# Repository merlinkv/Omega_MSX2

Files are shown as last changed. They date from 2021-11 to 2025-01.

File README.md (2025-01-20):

# Omega_MSX2
Update of the Omega Home Computer Project

# Original description

This project is an open source implementation of an MSX2 compatible computer. The project is built using a combination of 1980's era components - Z80 CPU, V9958 VDP, AY-3-8910/YM2149F PSG, 8255 PPI, 7400-series logic, and some newer components, such as 512 KiB SRAM and 512 KiB Flash ROM and a few simple programmable logic devices (ATF16V8B SPLDs).

# Keyboard PCB

* 14-04-2024
   - Version updated to 1.2 MKV
   - Schematics, PCB and Gerbers successfully ported to KiCad 8.0.1
   - The board has been rerouted.
   - Some components are now SMD
   - [Interactive BOM](https://htmlpreview.github.io/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)

# Mainboard PCB

* 10-05-2024
   - Added positility to select the connection type of Slots pin 44 (by SPDT switch SW3). They can be connected to GND (normal) or to NMI.
   - [Interactive BOM](https://htmlpreview.github.io/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)
* 20-04-2024
   - Version updated to 1.2.7 MKV
   - Power lines design has been changed.
   - Board has been re-routed.
* 14-04-2024
   - Version updated to 1.2.6 MKV
   - Schematics, PCB and Gerbers successfully ported to KiCad 8.0.1
   - The board has been re-routed.

# July 18, 2023

Added new ROMs.

# Mainboard PCB 1.2.5 MKV

* Improved routing parameters resulting on a bit more clear video & audio. In my opinion, before the RGB image was very good, now is really great.
* Power Switch footprint modified to, if desired, allow solder big section wires.
* Added another +5v Extra Power connector. The idea is to use it with horizontal pins and connect one small 4x4cm fan on top of the V9958.
* Board is tested working 100% with F4-FMPAC & o4Mega (4MB RAM) modules, internal Gotek with LCD 16x2 screen, cartridges Carnivore 2 & TDC-600 (floppy controller) at the same time with one **5.2v/3A** PSU

# Mainboard PCB 1.2 MKV

* Added possibility to use up to four different ROMs (two PLCC32 IC's).
* Added extra footprints for ROM selection switches.
* Changed internal FDD power connector to a better position.
* Changed all routing parameters and a couple of silk errors corrected.

# Mainboard PCB 1.1 MKV

Omega Mainboard PCB 1.1 MKV is a variant of the Mainboards 1.4US & 1.4EU by Sergey Kiselev & Jordi Solis

All "standard" capacitors, resistors & inductors are now in SMD 1206 format and placed at the bottom of the PCB.

New footprints for internal/external connections:

* 5-pins connector for DC-DC converter (+5v IN - +12v/-12v OUT)
* 2-pins connector for Power ON-OFF switch
* Two Extra Power connectors +5v (2-pins)
* One Extra Power connector +12v/-12v (3-pins)
* Connector for FM-PAC Module (AMP-GND, 2-pins)
* Connector for FM-PAC Power (+12v/-12v, 3-pins)
* Connector for RGB & Composite video (5-pins)
* Connector for S-Video (3-pins)
* Connector for Audio (Mono, 2-pins)
* Separate connectors for NMI & RESET (2-pins each)
* NMI signal connected to pin 44 of each slots (MSX3 Update?)
* FDD Power Connector (+5v/+12v, 4-pins)

# Notes

* Electrolytic capacitors: I recommend to use High Frequency and Low ESR ones.
* SMD resistors: Best is to use ones with 1% tolerance. All must be 1/4w.
* SMD capacitors: I recommend to use X7R type (10%) or less tolerance.
* ROM: AM29F040, SST39SF040 or compatible IC's can be used.
* SPLD's: ATF16V8B or GAL16V8B can be used without needed to use new jed's.
* For power cable and power switch best is to use wires with big section.
* At the moment I recommend to use one **5.2v/3A PSU**.
* It's possible to use one **5.5v/3A** PSU (near the limits but it's inside the power range).

# Links

* https://www.winuaespanol.com/phpbb3/viewtopic.php?p=13291#p13291
* https://github.com/skiselev/omega
* https://www.va-de-retro.com/foros/viewtopic.php?f=17&t=9304&start=40#p168183
* http://retrowiki.es/viewtopic.php?f=49&t=200037057&start=32#p200145495

# Images

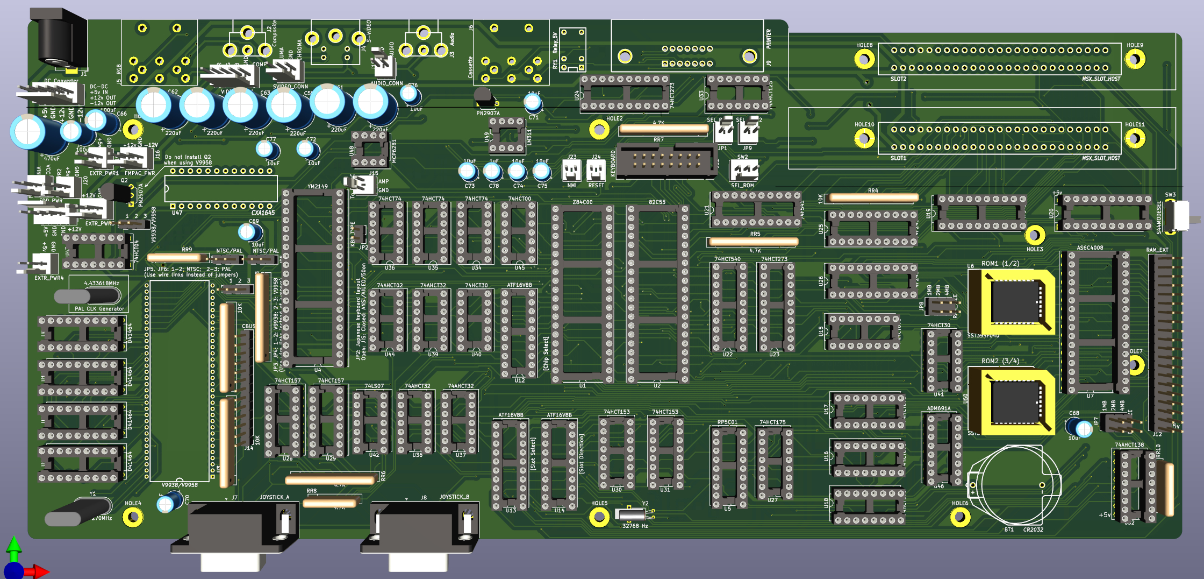
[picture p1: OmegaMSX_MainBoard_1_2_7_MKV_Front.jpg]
Vwersion 1.2.7 MKV Front

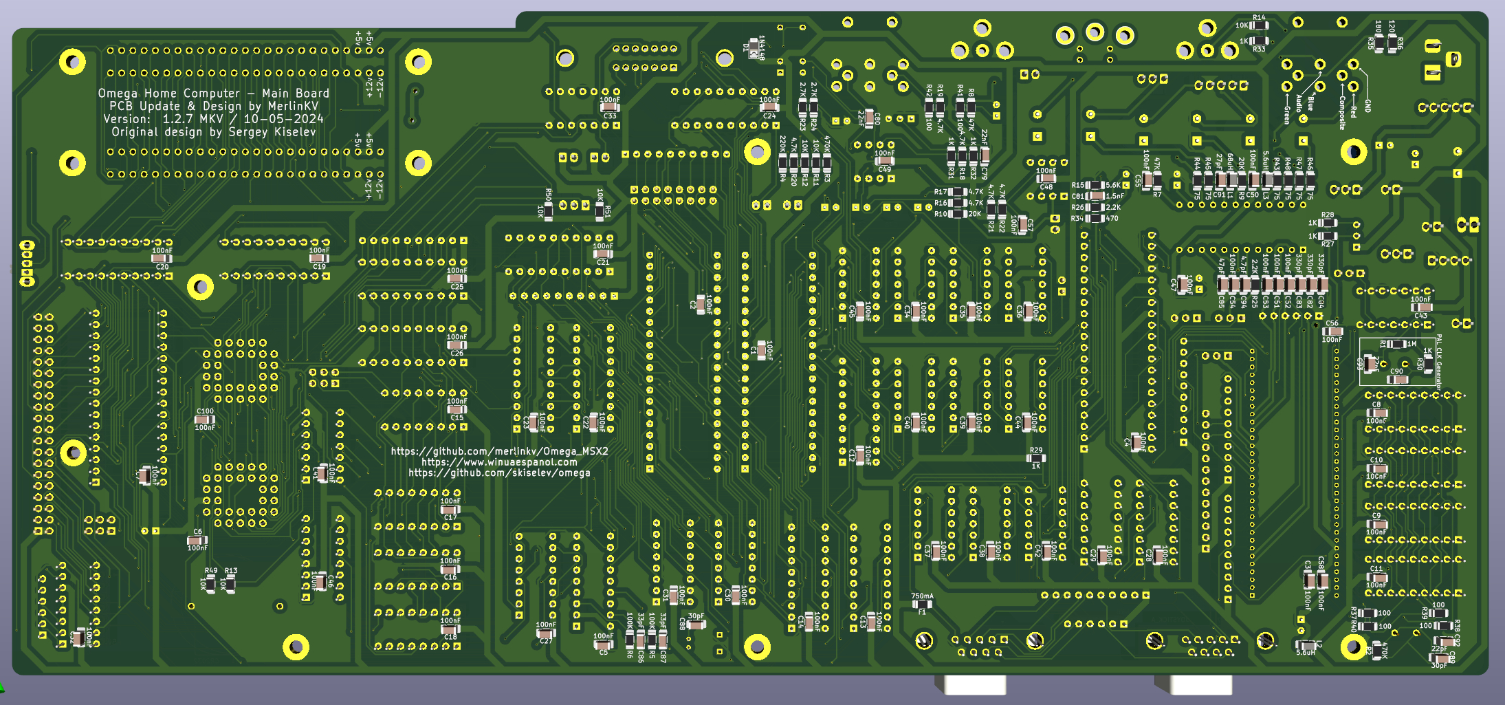
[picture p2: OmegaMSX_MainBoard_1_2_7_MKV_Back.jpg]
Vwersion 1.2.7 MKV Back

Vwersion 1.2.7 MKV Back
Vwersion 1.2.7 MKV Back
Vwersion 1.2.7 MKV Back
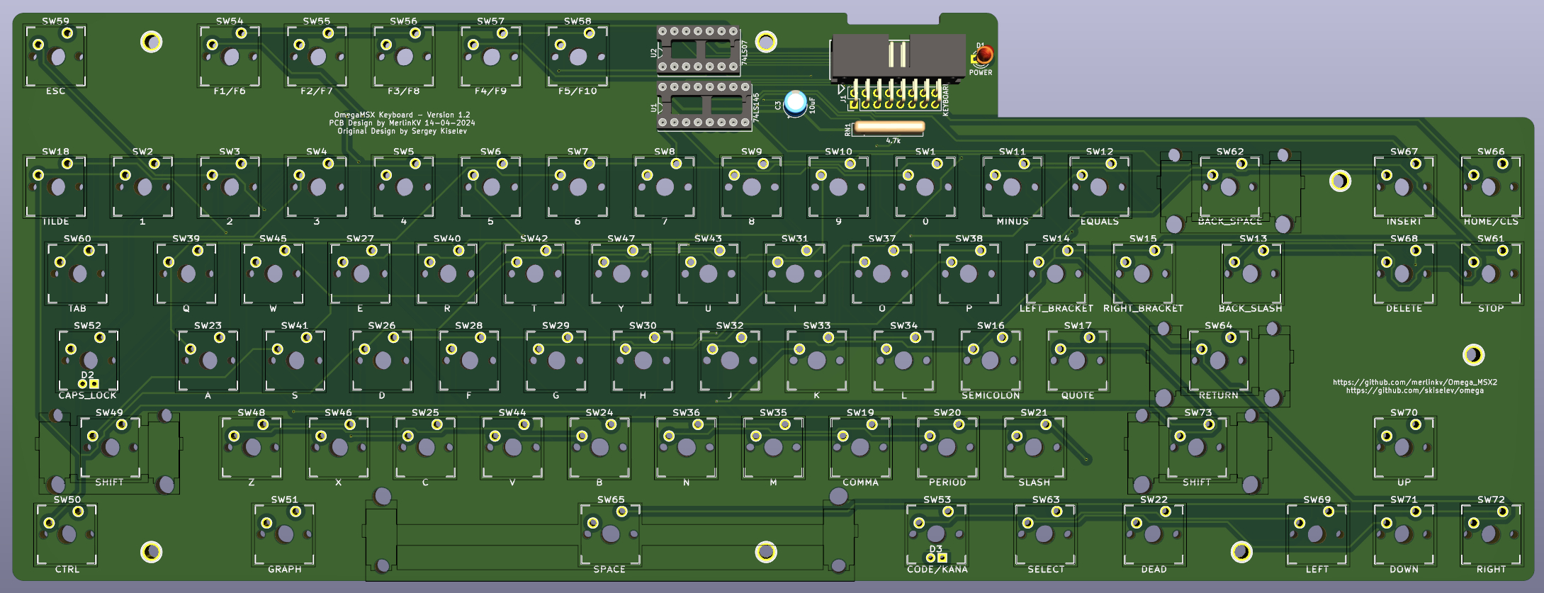
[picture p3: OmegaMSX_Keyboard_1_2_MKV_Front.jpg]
Version 1.2 MKV Front

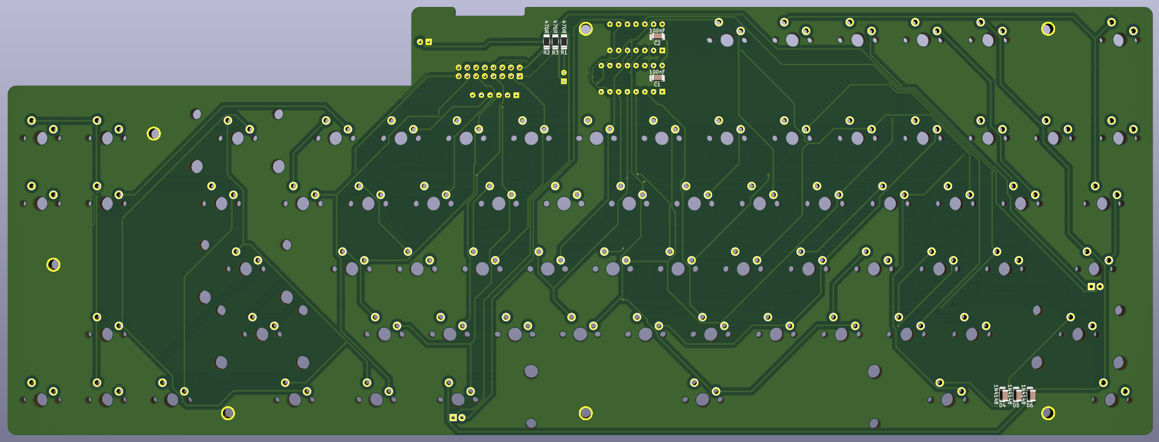
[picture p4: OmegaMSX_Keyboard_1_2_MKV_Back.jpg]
Version 1.2 MKV Back


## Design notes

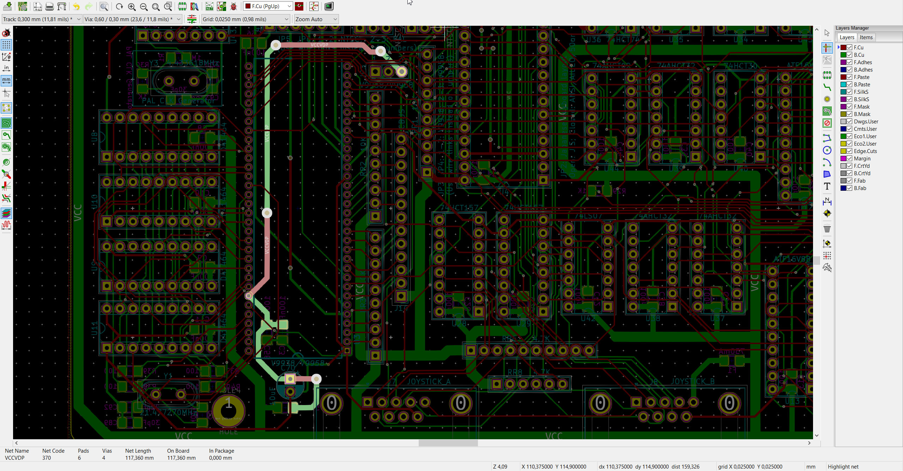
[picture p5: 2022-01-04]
Mainboard_1_2_MKV/OmegaMB_1_2_MKV_VCCVDP.jpg

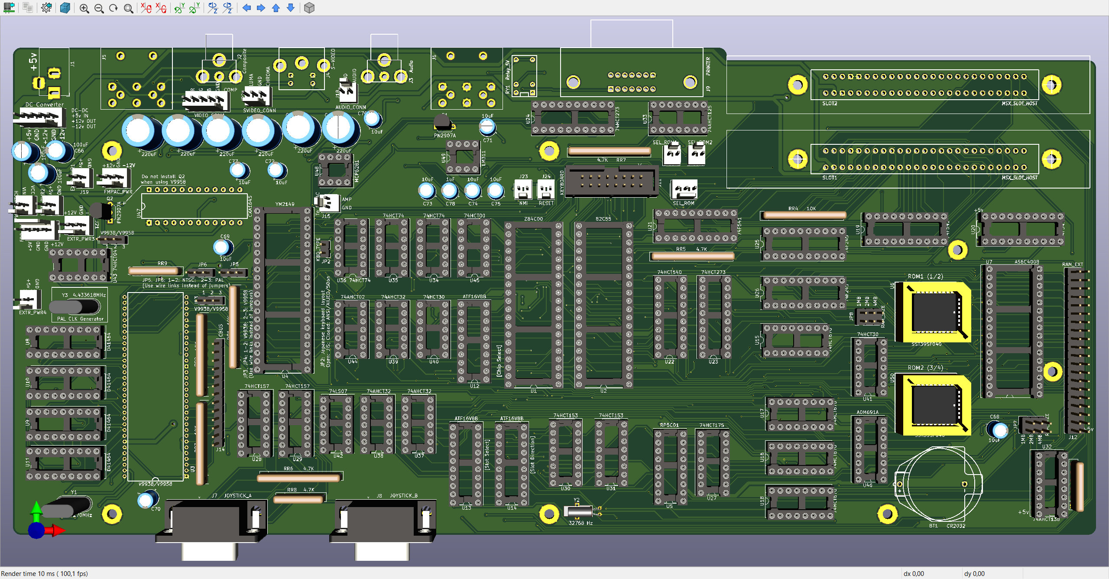
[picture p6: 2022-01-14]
Mainboard_1_2_5_MKV/OmegaMB_1_2_5_MKV_Front.jpg

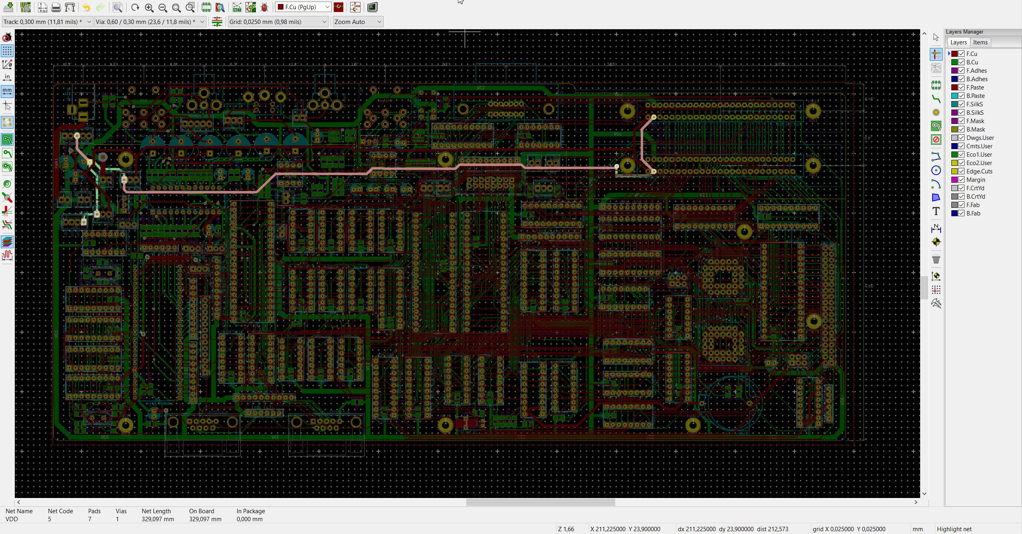
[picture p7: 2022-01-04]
Mainboard_1_2_MKV/OmegaMB_1_2_MKV_VDD.jpg

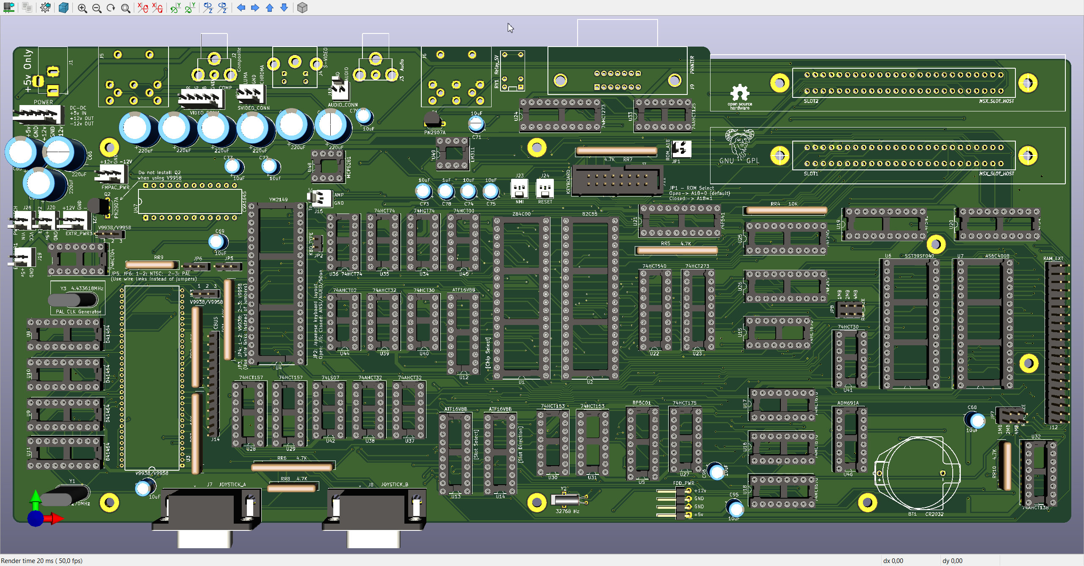
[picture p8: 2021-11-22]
Mainboard_1_1_MKV/OmegaMB_1_1_MKV_Front.jpg

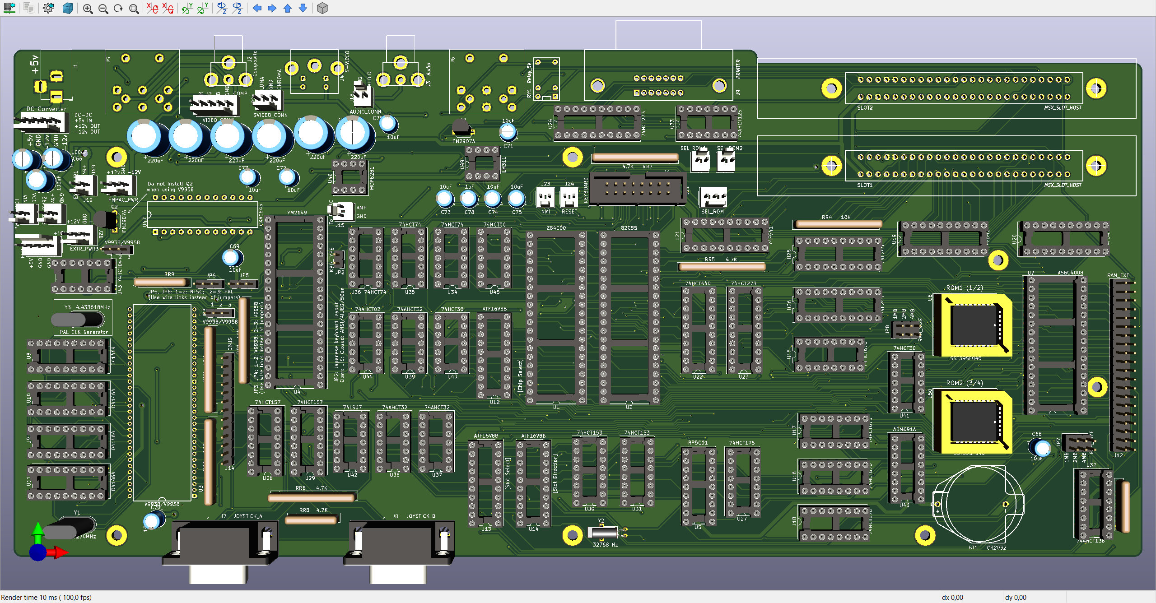
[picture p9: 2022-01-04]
Mainboard_1_2_MKV/OmegaMB_1_2_MKV_Front.jpg

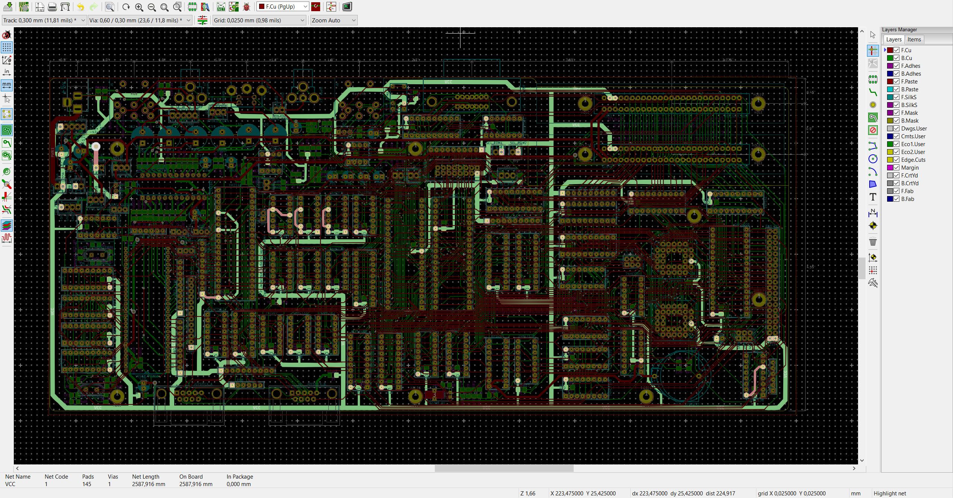
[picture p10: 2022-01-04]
Mainboard_1_2_MKV/OmegaMB_1_2_MKV_VCC.jpg

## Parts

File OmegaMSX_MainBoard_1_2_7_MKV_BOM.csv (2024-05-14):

Id | Designator | Footprint | Quantity | Designation | Supplier and ref
1 | SW3 | SW_Slide_SPDT_Angled_CK_OS102011MA1Q | 1 | S44MODESEL
2 | HOLE1,HOLE2,HOLE3,HOLE4,HOLE5,HOLE6,HOLE7,HOLE8,HOLE9,HOLE10,HOLE11 | MountingHole_3mm_Pad | 11 | HOLE
3 | C59,C60,C63,C64,C61,C62 | CP_Radial_D10.0mm_P5.00mm | 6 | 220uF
4 | C65 | CP_Radial_D10.0mm_P5.00mm | 1 | 470uF
5 | C66,C67 | CP_Radial_D6.3mm_P2.50mm | 2 | 100uF
6 | C72,C75,C76,C74,C77,C71,C73,C68,C69,C70 | CP_Radial_D5.0mm_P2.50mm | 10 | 10uF
7 | J1 | BarrelJack_Horizontal | 1 | 5V
8 | J7 | DSUB-9_Male_Horizontal_P2.77x2.84mm_EdgePinOffset4.94mm_Housed_MountingHolesOffset7.48mm | 1 | JOYSTICK_A
9 | J8 | DSUB-9_Male_Horizontal_P2.77x2.84mm_EdgePinOffset4.94mm_Housed_MountingHolesOffset7.48mm | 1 | JOYSTICK_B
10 | JP1 | Molex_KK-254_AE-6410-02A_1x02_P2.54mm_Vertical | 1 | SEL_ROM1
11 | JP2 | PinHeader_1x02_P2.54mm_Vertical | 1 | KBD_TYPE
12 | JP3,JP4 | PinHeader_1x03_P2.54mm_Vertical | 2 | V9938/V9958
13 | JP5,JP6 | PinHeader_1x03_P2.54mm_Vertical | 2 | NTSC/PAL
14 | RR1,RR2,RR3,RR4 | R_Array_SIP10 | 4 | 10K
15 | RR6,RR5,RR7 | R_Array_SIP10 | 3 | 4.7K
16 | RR8,RR10 | R_Array_SIP6 | 2 | 4.7K
17 | RR9 | R_Array_SIP6 | 1 | 470
18 | U2 | DIP-40_W15.24mm_Socket | 1 | 82C55
19 | U3 | IC_SDIP64_600 | 1 | V9938/V9958
20 | U4 | DIP-40_W15.24mm_Socket | 1 | YM2149
21 | U5 | DIP-18_W7.62mm_Socket | 1 | RP5C01
22 | U6,U50 | SST39SF040_PLCC32 | 2 | SST39SF040
23 | U7 | DIP-32_W15.24mm_Socket | 1 | AS6C4008
24 | U8,U9,U10,U11 | DIP-18_W7.62mm_Socket | 4 | D41464
25 | U12,U14,U13 | DIP-20_W7.62mm_Socket | 3 | ATF16V8B
26 | U15,U17,U18,U16 | DIP-16_W7.62mm_Socket | 4 | 74HCT670
27 | U20,U21,U19 | DIP-20_W7.62mm_Socket | 3 | 74F541
28 | U23,U24 | DIP-20_W7.62mm_Socket | 2 | 74HCT273
29 | U25,U26 | DIP-20_W7.62mm_Socket | 2 | 74F245
30 | U27 | DIP-16_W7.62mm_Socket | 1 | 74HCT175
31 | U28,U29 | DIP-16_W7.62mm_Socket | 2 | 74HCT157
32 | U31,U30 | DIP-16_W7.62mm_Socket | 2 | 74HCT153
33 | U33 | DIP-14_W7.62mm_Socket | 1 | 74AHCT125
34 | U34,U35,U36 | DIP-14_W7.62mm_Socket | 3 | 74HCT74
35 | U38,U39,U37 | DIP-14_W7.62mm_Socket | 3 | 74AHCT32
36 | U42 | DIP-14_W7.62mm_Socket | 1 | 74LS07
37 | U44 | DIP-14_W7.62mm_Socket | 1 | 74AHCT02
38 | U45 | DIP-14_W7.62mm_Socket | 1 | 74HCT00
39 | U47 | IC_DIP24_400 | 1 | CXA1645
40 | Y3 | Crystal_HC49-U_Vertical | 1 | 4.433618MHz
41 | J3 | Conn_RCA_Right | 1 | Audio
42 | U22 | DIP-20_W7.62mm_Socket | 1 | 74HCT540
43 | U40,U41 | DIP-14_W7.62mm_Socket | 2 | 74HCT30
44 | J11 | IDC-Header_2x08_P2.54mm_Vertical | 1 | KEYBOARD
45 | Q2,Q1 | TO-92L_Inline_Wide | 2 | PN2907A
46 | J12 | PinHeader_2x20_P2.54mm_Vertical | 1 | RAM_EXT
47 | BT1 | Battery_Holder_CR2032_Universal | 1 | CR2032
48 | U46 | DIP-16_W7.62mm_Socket | 1 | ADM691A
49 | J9 | Conn_Micro_Ribbon_14F | 1 | PRINTER
50 | J4 | Conn_Mini_DIN_4pin | 1 | S-VIDEO
51 | U48 | DIP-8_W7.62mm_Socket | 1 | MCP6281
52 | U43 | DIP-14_W7.62mm_Socket | 1 | 74HCT04
53 | J6 | DIN8 | 1 | Cassette
54 | RY1 | Relay_SPDT | 1 | Relay_5V
55 | C78 | CP_Radial_D5.0mm_P2.50mm | 1 | 1uF
56 | U49 | DIP-8_W7.62mm_Socket | 1 | LM311
57 | J5 | DIN8 | 1 | RGB
58 | J2 | Conn_RCA_Right | 1 | Composite
59 | Y1 | Crystal_HC49-U_Vertical | 1 | 21.477270MHz
60 | Y2 | Crystal_C38-LF_D3.0mm_L8.0mm_Horizontal_1EP_style2 | 1 | 32768 Hz
61 | J14 | PinHeader_1x13_P2.54mm_Vertical | 1 | CBUS
62 | JP7,JP8 | PinHeader_2x03_P2.54mm_Vertical | 2 | RAM_SIZE
63 | U32 | DIP-16_W7.62mm_Socket | 1 | 74AHCT138
64 | J15 | Molex_KK-254_AE-6410-02A_1x02_P2.54mm_Vertical | 1 | To_FMPAC
65 | J16 | Molex_KK-254_AE-6410-03A_1x03_P2.54mm_Vertical | 1 | FMPAC_PWR
66 | J25 | Molex_KK-254_AE-6410-04A_1x04_P2.54mm_Vertical | 1 | FDD_PWR
67 | J21 | Molex_KK-254_AE-6410-03A_1x03_P2.54mm_Vertical | 1 | EXTR_PWR3
68 | SLOT1,SLOT2 | Conn_Edge_50P | 2 | MSX_SLOT_HOST
69 | U1 | DIP-40_W15.24mm_Socket | 1 | Z84C00
70 | J22 | Molex_KK-254_AE-6410-03A_1x03_P2.54mm_Vertical | 1 | SVIDEO_CONN
71 | J19 | Molex_KK-254_AE-6410-02A_1x02_P2.54mm_Vertical | 1 | EXTR_PWR1
72 | J20 | Molex_KK-254_AE-6410-02A_1x02_P2.54mm_Vertical | 1 | EXTR_PWR2
73 | J17 | Molex_KK-254_AE-6410-05A_1x05_P2.54mm_Vertical | 1 | VIDEO_CONN
74 | J18 | Molex_KK-254_AE-6410-02A_1x02_P2.54mm_Vertical | 1 | AUDIO_CONN
75 | J23 | Molex_KK-254_AE-6410-02A_1x02_P2.54mm_Vertical | 1 | NMI
76 | J24 | Molex_KK-254_AE-6410-02A_1x02_P2.54mm_Vertical | 1 | RESET
77 | J10 | Molex_KK-254_AE-6410-05A_1x05_P2.54mm_Vertical | 1 | DC Converter
78 | JP9 | Molex_KK-254_AE-6410-02A_1x02_P2.54mm_Vertical | 1 | SEL_ROM2
79 | SW2 | Molex_KK-254_AE-6410-03A_1x03_P2.54mm_Vertical | 1 | SEL_ROM
80 | J27 | Molex_KK-254_AE-6410-02A_1x02_P2.54mm_Vertical | 1 | EXTR_PWR4
81 | J26 | Molex_KK-254_AE-6410-02A_1x02_P2.54mm_Vertical_Omega | 1 | PWR_SW
82 | C1,C2,C4,C5,C6,C7,C8,C9,C10,C11,C12,C13,C14,C15,C17,C18,C20,C21,C22,C24,C25,C26,C27,C28,C29,C30,C31,C32,C33,C34,C35,C36,C37,C38,C39,C40,C41,C42,C43,C44,C45,C46,C47,C52,C56,C23,C54,C51,C53,C19,C16,C48,C57,C49,C55,C58,C3,C50,C100 | C_1206_3216Metric_Pad1.33x1.80mm_HandSolder | 59 | 100nF
83 | C80,C79 | C_1206_3216Metric_Pad1.33x1.80mm_HandSolder | 2 | 22nF
84 | C82,C83,C84 | C_1206_3216Metric_Pad1.33x1.80mm_HandSolder | 3 | 330pF
85 | C85 | C_1206_3216Metric_Pad1.33x1.80mm_HandSolder | 1 | 47pF
86 | C86,C87 | C_1206_3216Metric_Pad1.33x1.80mm_HandSolder | 2 | 33pF
87 | C92,C93 | C_1206_3216Metric_Pad1.33x1.80mm_HandSolder | 2 | 22pF
88 | D1 | D_1206_3216Metric_Pad1.42x1.75mm_HandSolder | 1 | 1N4148
89 | R1 | R_1206_3216Metric_Pad1.30x1.75mm_HandSolder | 1 | 1M
90 | R2,R3 | R_1206_3216Metric_Pad1.30x1.75mm_HandSolder | 2 | 470K
91 | R5,R6 | R_1206_3216Metric_Pad1.30x1.75mm_HandSolder | 2 | 100K
92 | R7,R8 | R_1206_3216Metric_Pad1.30x1.75mm_HandSolder | 2 | 47K
93 | R17,R21,R22,R16,R19,R18,R20 | R_1206_3216Metric_Pad1.30x1.75mm_HandSolder | 7 | 4.7K
94 | R25,R26 | R_1206_3216Metric_Pad1.30x1.75mm_HandSolder | 2 | 2.2K
95 | R30,R29,R27,R28,R31,R32,R33 | R_1206_3216Metric_Pad1.30x1.75mm_HandSolder | 7 | 1K
96 | R37,R39,R40,R41,R38,R42 | R_1206_3216Metric_Pad1.30x1.75mm_HandSolder | 6 | 100
97 | R47,R48,R45,R44,R43,R46 | R_1206_3216Metric_Pad1.30x1.75mm_HandSolder | 6 | 75
98 | R9,R10 | R_1206_3216Metric_Pad1.30x1.75mm_HandSolder | 2 | 20K
99 | C94 | C_1206_3216Metric_Pad1.33x1.80mm_HandSolder | 1 | 4.7pF
100 | C81 | C_1206_3216Metric_Pad1.33x1.80mm_HandSolder | 1 | 1.5nF
101 | R13,R12,R11,R14,R49,R50,R51 | R_1206_3216Metric_Pad1.30x1.75mm_HandSolder | 7 | 10K
102 | R15 | R_1206_3216Metric_Pad1.30x1.75mm_HandSolder | 1 | 5.6K
103 | L1 | L_1206_3216Metric_Pad1.42x1.75mm_HandSolder | 1 | 68uH
104 | C91 | C_1206_3216Metric_Pad1.33x1.80mm_HandSolder | 1 | 27pF
105 | R23,R24 | R_1206_3216Metric_Pad1.30x1.75mm_HandSolder | 2 | 2.7K
106 | R4 | R_1206_3216Metric_Pad1.30x1.75mm_HandSolder | 1 | 220K
107 | R35 | R_1206_3216Metric_Pad1.30x1.75mm_HandSolder | 1 | 180
108 | R36 | R_1206_3216Metric_Pad1.30x1.75mm_HandSolder | 1 | 120
109 | R34 | R_1206_3216Metric_Pad1.30x1.75mm_HandSolder | 1 | 470
110 | L2,L3 | L_1206_3216Metric_Pad1.42x1.75mm_HandSolder | 2 | 5.6uH
111 | F1 | Fuse_1206_3216Metric_Pad1.42x1.75mm_HandSolder | 1 | 750mA
112 | C89,C90,C88 | C_1206_3216Metric_Pad1.33x1.80mm_HandSolder | 3 | 30pF

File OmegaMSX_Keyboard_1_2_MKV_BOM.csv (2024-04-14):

Id | Designator | Footprint | Quantity | Designation | Supplier and ref
1 | SW1 | CHERRY_PCB_100H | 1 | 0
2 | SW2 | CHERRY_PCB_100H | 1 | 1
3 | SW3 | CHERRY_PCB_100H | 1 | 2
4 | SW4 | CHERRY_PCB_100H | 1 | 3
5 | SW5 | CHERRY_PCB_100H | 1 | 4
6 | SW6 | CHERRY_PCB_100H | 1 | 5
7 | SW7 | CHERRY_PCB_100H | 1 | 6
8 | SW8 | CHERRY_PCB_100H | 1 | 7
9 | SW9 | CHERRY_PCB_100H | 1 | 8
10 | SW10 | CHERRY_PCB_100H | 1 | 9
11 | SW11 | CHERRY_PCB_100H | 1 | MINUS
12 | SW12 | CHERRY_PCB_100H | 1 | EQUALS
13 | SW13 | CHERRY_PCB_150H | 1 | BACK_SLASH
14 | SW14 | CHERRY_PCB_100H | 1 | LEFT_BRACKET
15 | SW15 | CHERRY_PCB_100H | 1 | RIGHT_BRACKET
16 | SW16 | CHERRY_PCB_100H | 1 | SEMICOLON
17 | SW17 | CHERRY_PCB_100H | 1 | QUOTE
18 | SW18 | CHERRY_PCB_100H | 1 | TILDE
19 | SW19 | CHERRY_PCB_100H | 1 | COMMA
20 | SW20 | CHERRY_PCB_100H | 1 | PERIOD
21 | SW21 | CHERRY_PCB_100H | 1 | SLASH
22 | SW22 | CHERRY_PCB_100H | 1 | DEAD
23 | SW23 | CHERRY_PCB_100H | 1 | A
24 | SW24 | CHERRY_PCB_100H | 1 | B
25 | SW25 | CHERRY_PCB_100H | 1 | C
26 | SW26 | CHERRY_PCB_100H | 1 | D
27 | SW27 | CHERRY_PCB_100H | 1 | E
28 | SW28 | CHERRY_PCB_100H | 1 | F
29 | SW29 | CHERRY_PCB_100H | 1 | G
30 | SW30 | CHERRY_PCB_100H | 1 | H
31 | SW31 | CHERRY_PCB_100H | 1 | I
32 | SW32 | CHERRY_PCB_100H | 1 | J
33 | SW33 | CHERRY_PCB_100H | 1 | K
34 | SW34 | CHERRY_PCB_100H | 1 | L
35 | SW35 | CHERRY_PCB_100H | 1 | M
36 | SW36 | CHERRY_PCB_100H | 1 | N
37 | SW37 | CHERRY_PCB_100H | 1 | O
38 | SW38 | CHERRY_PCB_100H | 1 | P
39 | SW39 | CHERRY_PCB_100H | 1 | Q
40 | SW40 | CHERRY_PCB_100H | 1 | R
41 | SW41 | CHERRY_PCB_100H | 1 | S
42 | SW42 | CHERRY_PCB_100H | 1 | T
43 | SW43 | CHERRY_PCB_100H | 1 | U
44 | SW44 | CHERRY_PCB_100H | 1 | V
45 | SW45 | CHERRY_PCB_100H | 1 | W
46 | SW46 | CHERRY_PCB_100H | 1 | X
47 | SW47 | CHERRY_PCB_100H | 1 | Y
48 | SW48 | CHERRY_PCB_100H | 1 | Z
49 | SW49 | CHERRY_PCB_225H | 1 | SHIFT
50 | SW50 | CHERRY_PCB_125H | 1 | CTRL
51 | SW51 | CHERRY_PCB_125H | 1 | GRAPH
52 | SW52 | CHERRY_PCB_175H | 1 | CAPS_LOCK
53 | SW53 | CHERRY_PCB_125H | 1 | CODE/KANA
54 | SW54 | CHERRY_PCB_100H | 1 | F1/F6
55 | SW55 | CHERRY_PCB_100H | 1 | F2/F7
56 | SW56 | CHERRY_PCB_100H | 1 | F3/F8
57 | SW57 | CHERRY_PCB_100H | 1 | F4/F9
58 | SW58 | CHERRY_PCB_100H | 1 | F5/F10
59 | SW59 | CHERRY_PCB_100H | 1 | ESC
60 | SW60 | CHERRY_PCB_100H | 1 | TAB
61 | SW61 | CHERRY_PCB_100H | 1 | STOP
62 | SW62 | CHERRY_PCB_200H | 1 | BACK_SPACE
63 | SW64 | CHERRY_PCB_225H | 1 | RETURN
64 | SW65 | CHERRY_PCB_625H | 1 | SPACE
65 | SW66 | CHERRY_PCB_100H | 1 | HOME/CLS
66 | SW67 | CHERRY_PCB_100H | 1 | INSERT
67 | SW68 | CHERRY_PCB_100H | 1 | DELETE
68 | SW69 | CHERRY_PCB_100H | 1 | LEFT
69 | SW70 | CHERRY_PCB_100H | 1 | UP
70 | SW71 | CHERRY_PCB_100H | 1 | DOWN
71 | SW72 | CHERRY_PCB_100H | 1 | RIGHT
72 | SW63 | CHERRY_PCB_125H | 1 | SELECT
73 | SW73 | CHERRY_PCB_275H | 1 | SHIFT
74 | C3 | CP_Radial_D5.0mm_P2.50mm | 1 | 10uF
75 | D1 | LED_D3.0mm | 1 | POWER
76 | HOLE1,HOLE2,HOLE3,HOLE4,HOLE5,HOLE6,HOLE7 | Hole_3mm | 7 | HOLE
77 | J1 | PinHeader_2x08_P2.54mm_Vertical | 1 | KEYBOARD
78 | U1 | DIP-16_W7.62mm_Socket | 1 | 74LS145
79 | U2 | DIP-14_W7.62mm_Socket | 1 | 74LS07
80 | D3 | CHERRY_MX_LED | 1 | KANA
81 | D2 | CHERRY_MX_LED | 1 | CAPS
82 | RN1 | R_Array_SIP6 | 1 | 4.7k
83 | C1,C2 | C_1206_3216Metric_Pad1.33x1.80mm_HandSolder | 2 | 100nF
84 | D4,D5,D6 | C_1206_3216Metric_Pad1.33x1.80mm_HandSolder | 3 | 1N4148
85 | R1,R2,R3 | R_1206_3216Metric_Pad1.30x1.75mm_HandSolder | 3 | 470R

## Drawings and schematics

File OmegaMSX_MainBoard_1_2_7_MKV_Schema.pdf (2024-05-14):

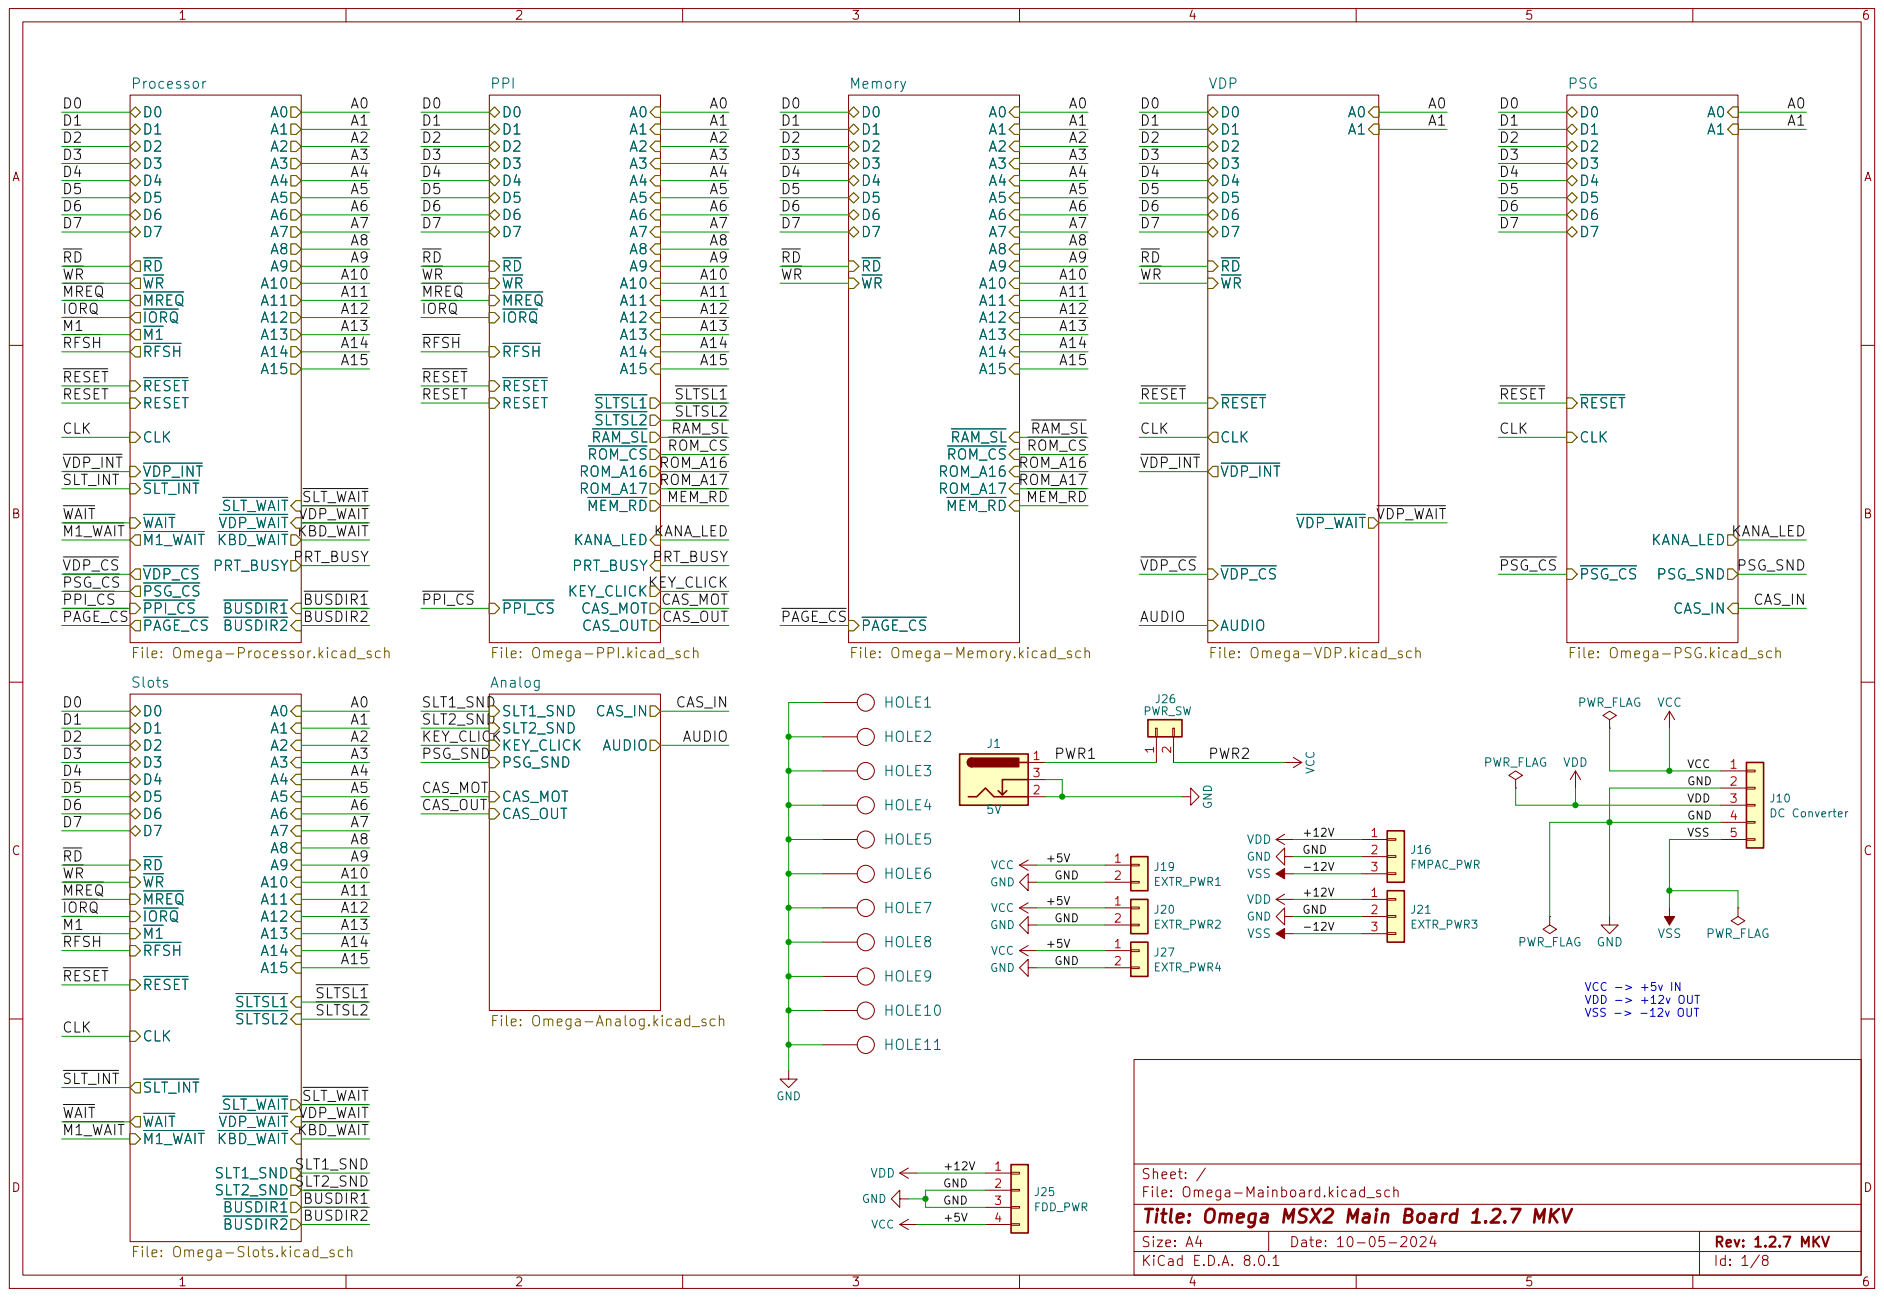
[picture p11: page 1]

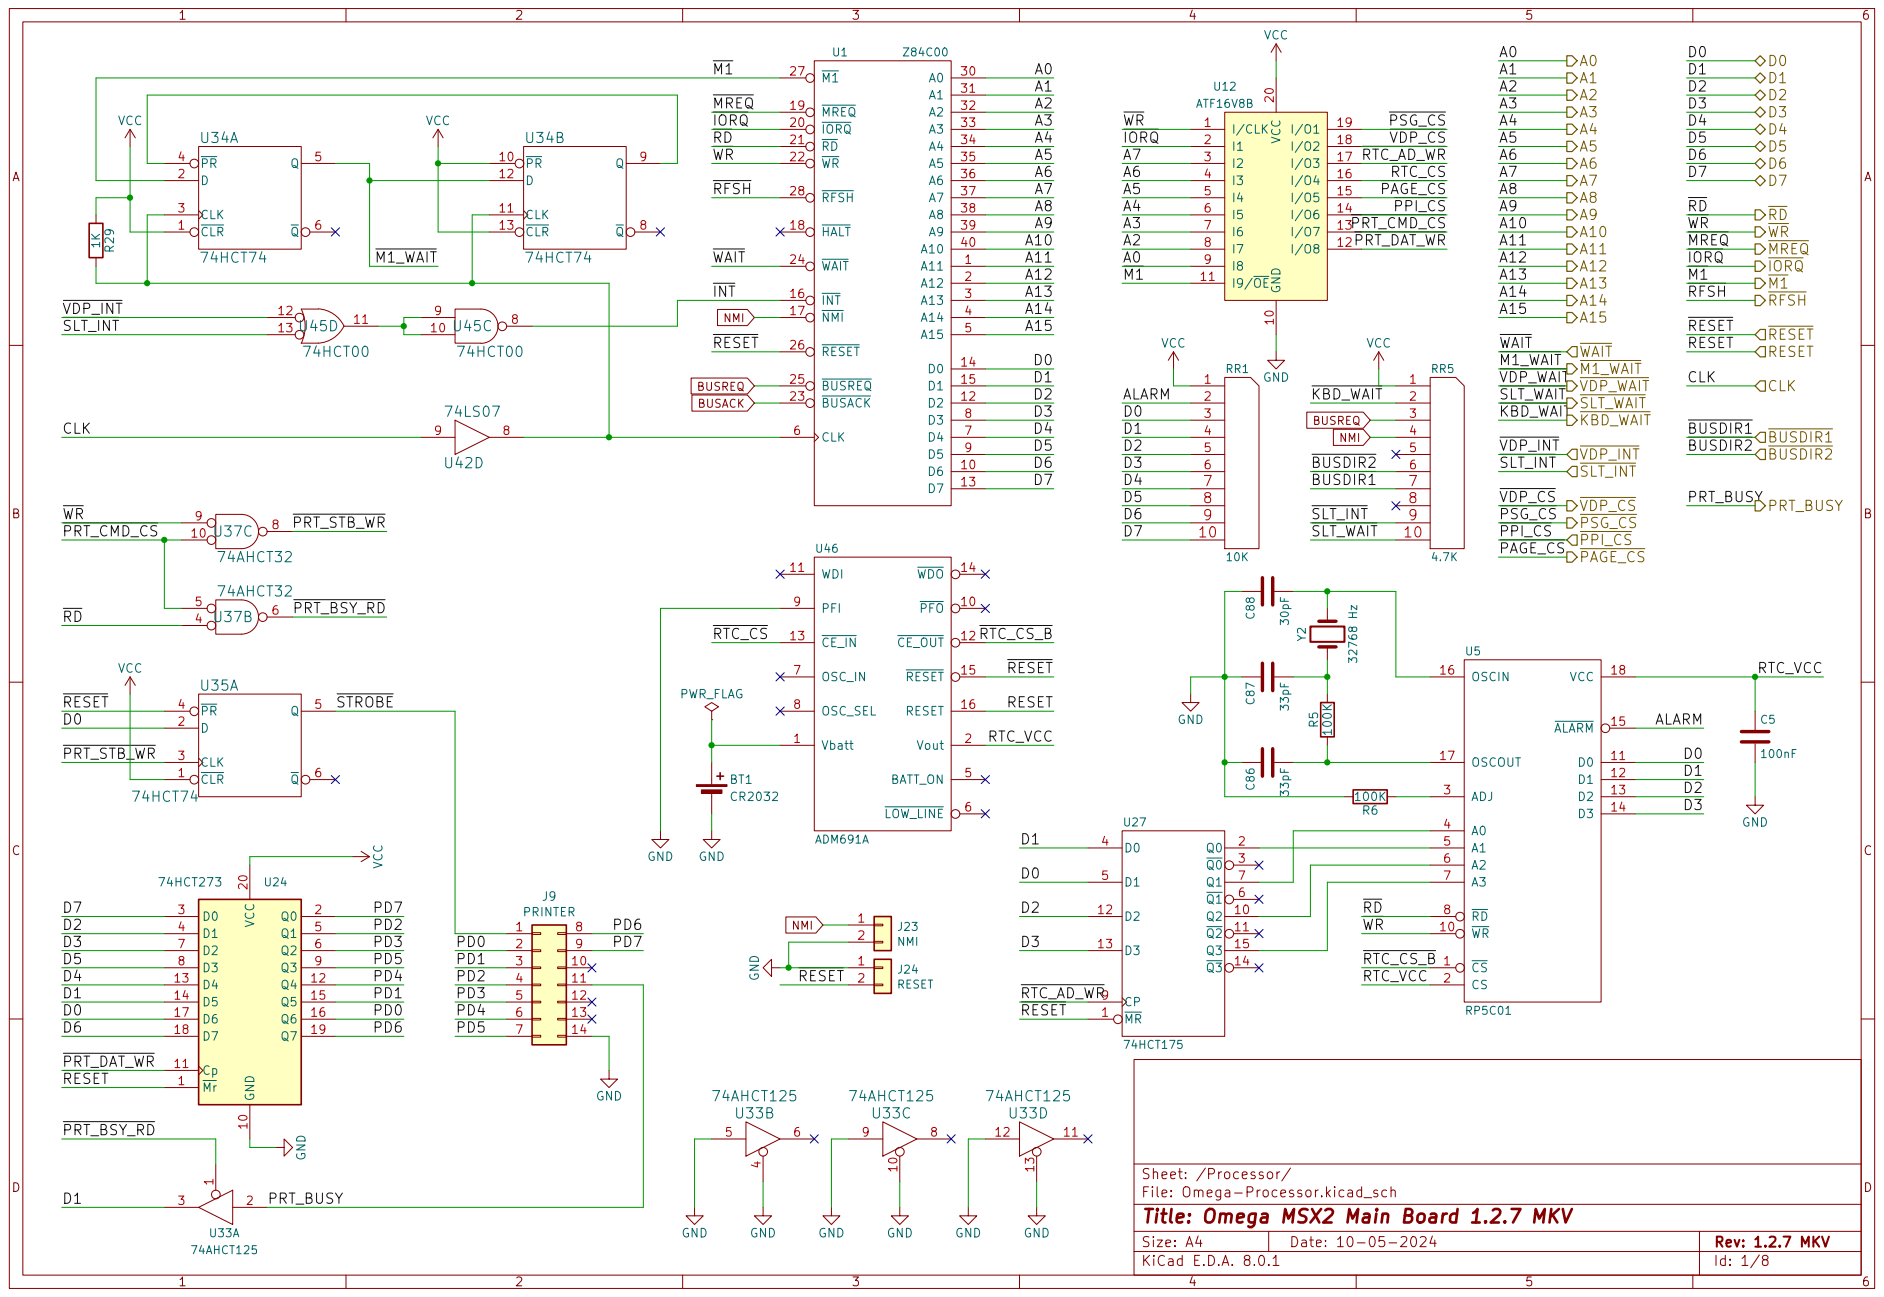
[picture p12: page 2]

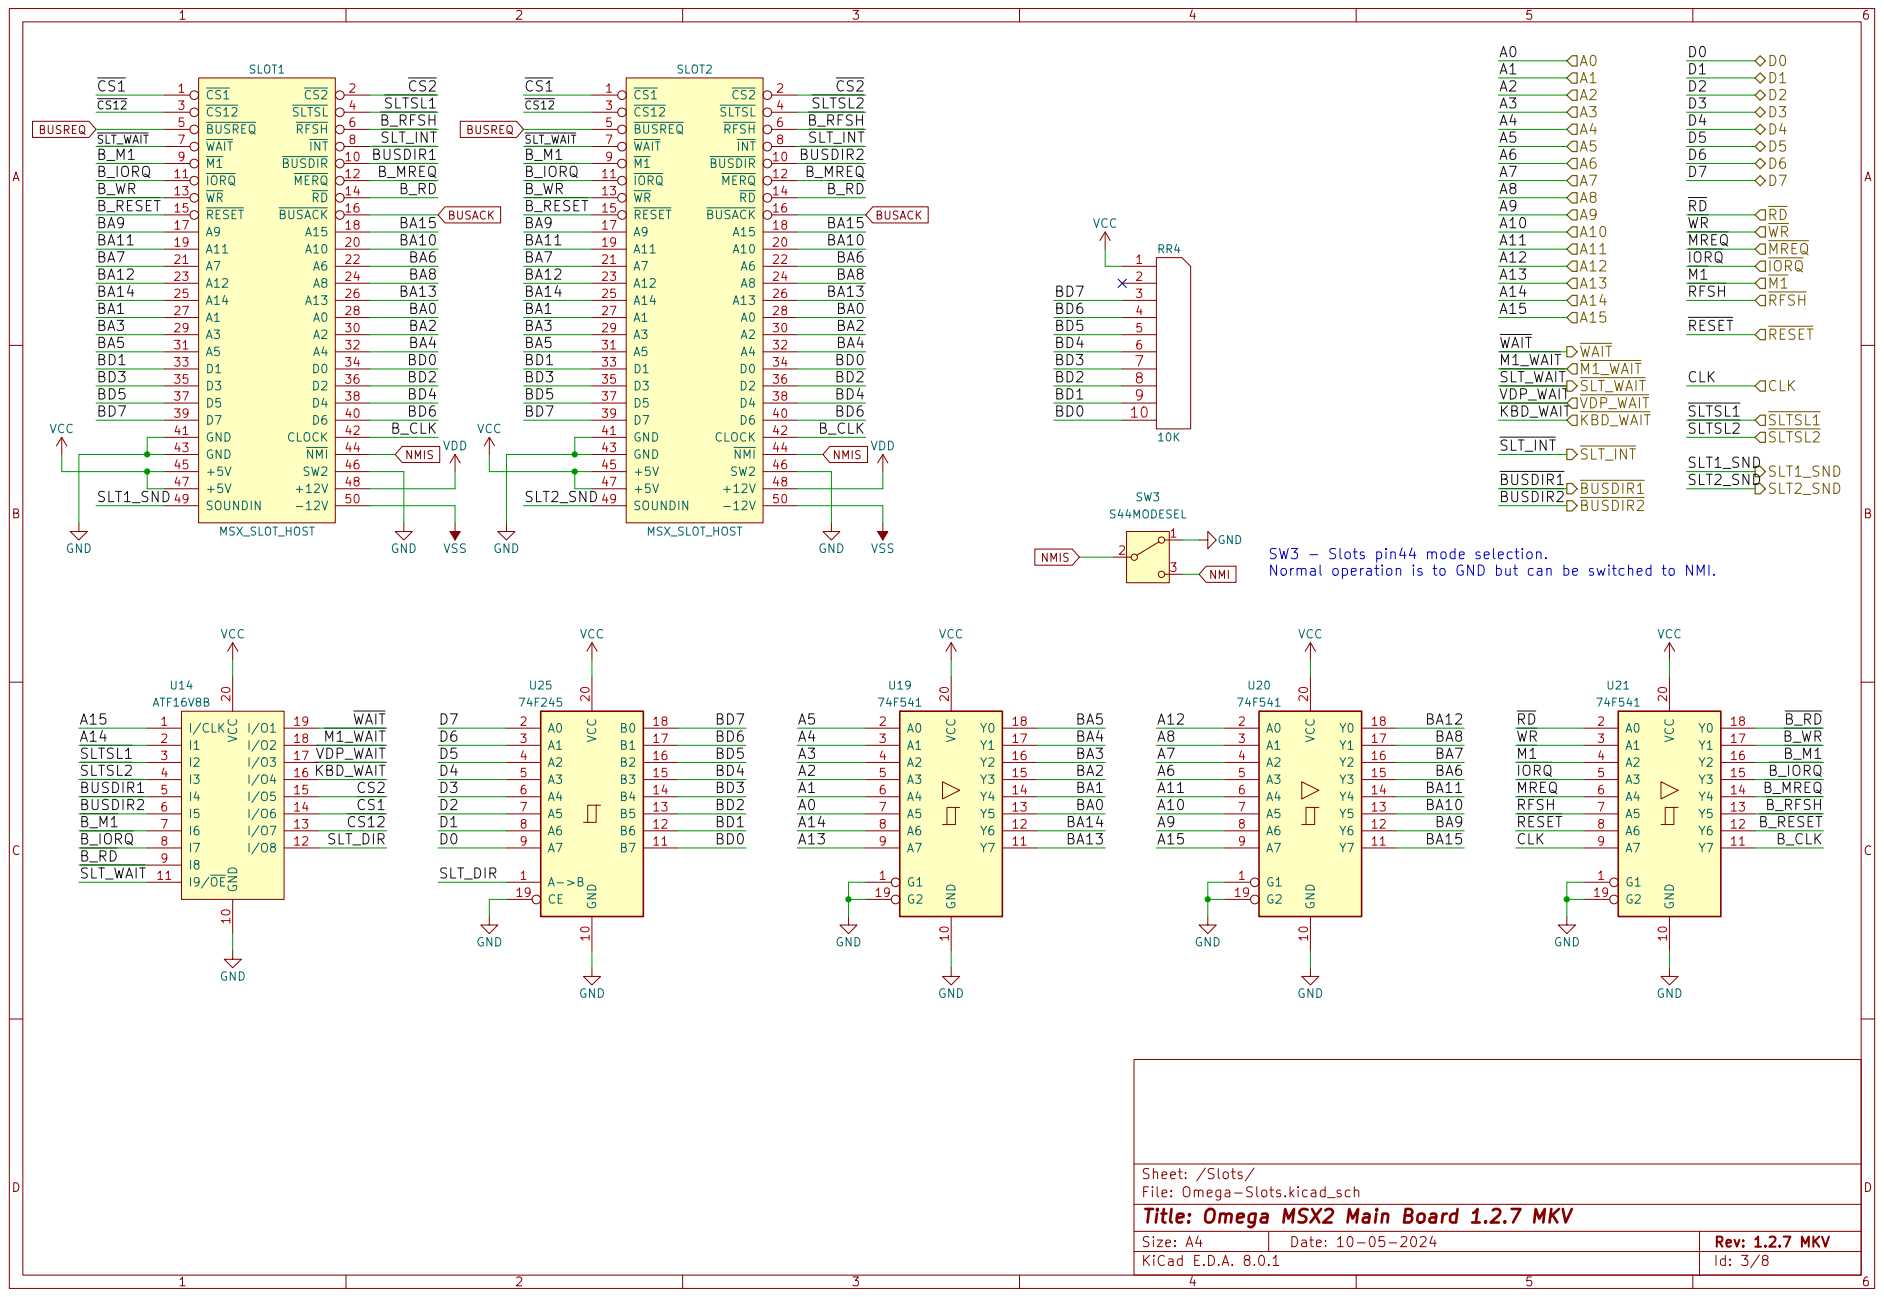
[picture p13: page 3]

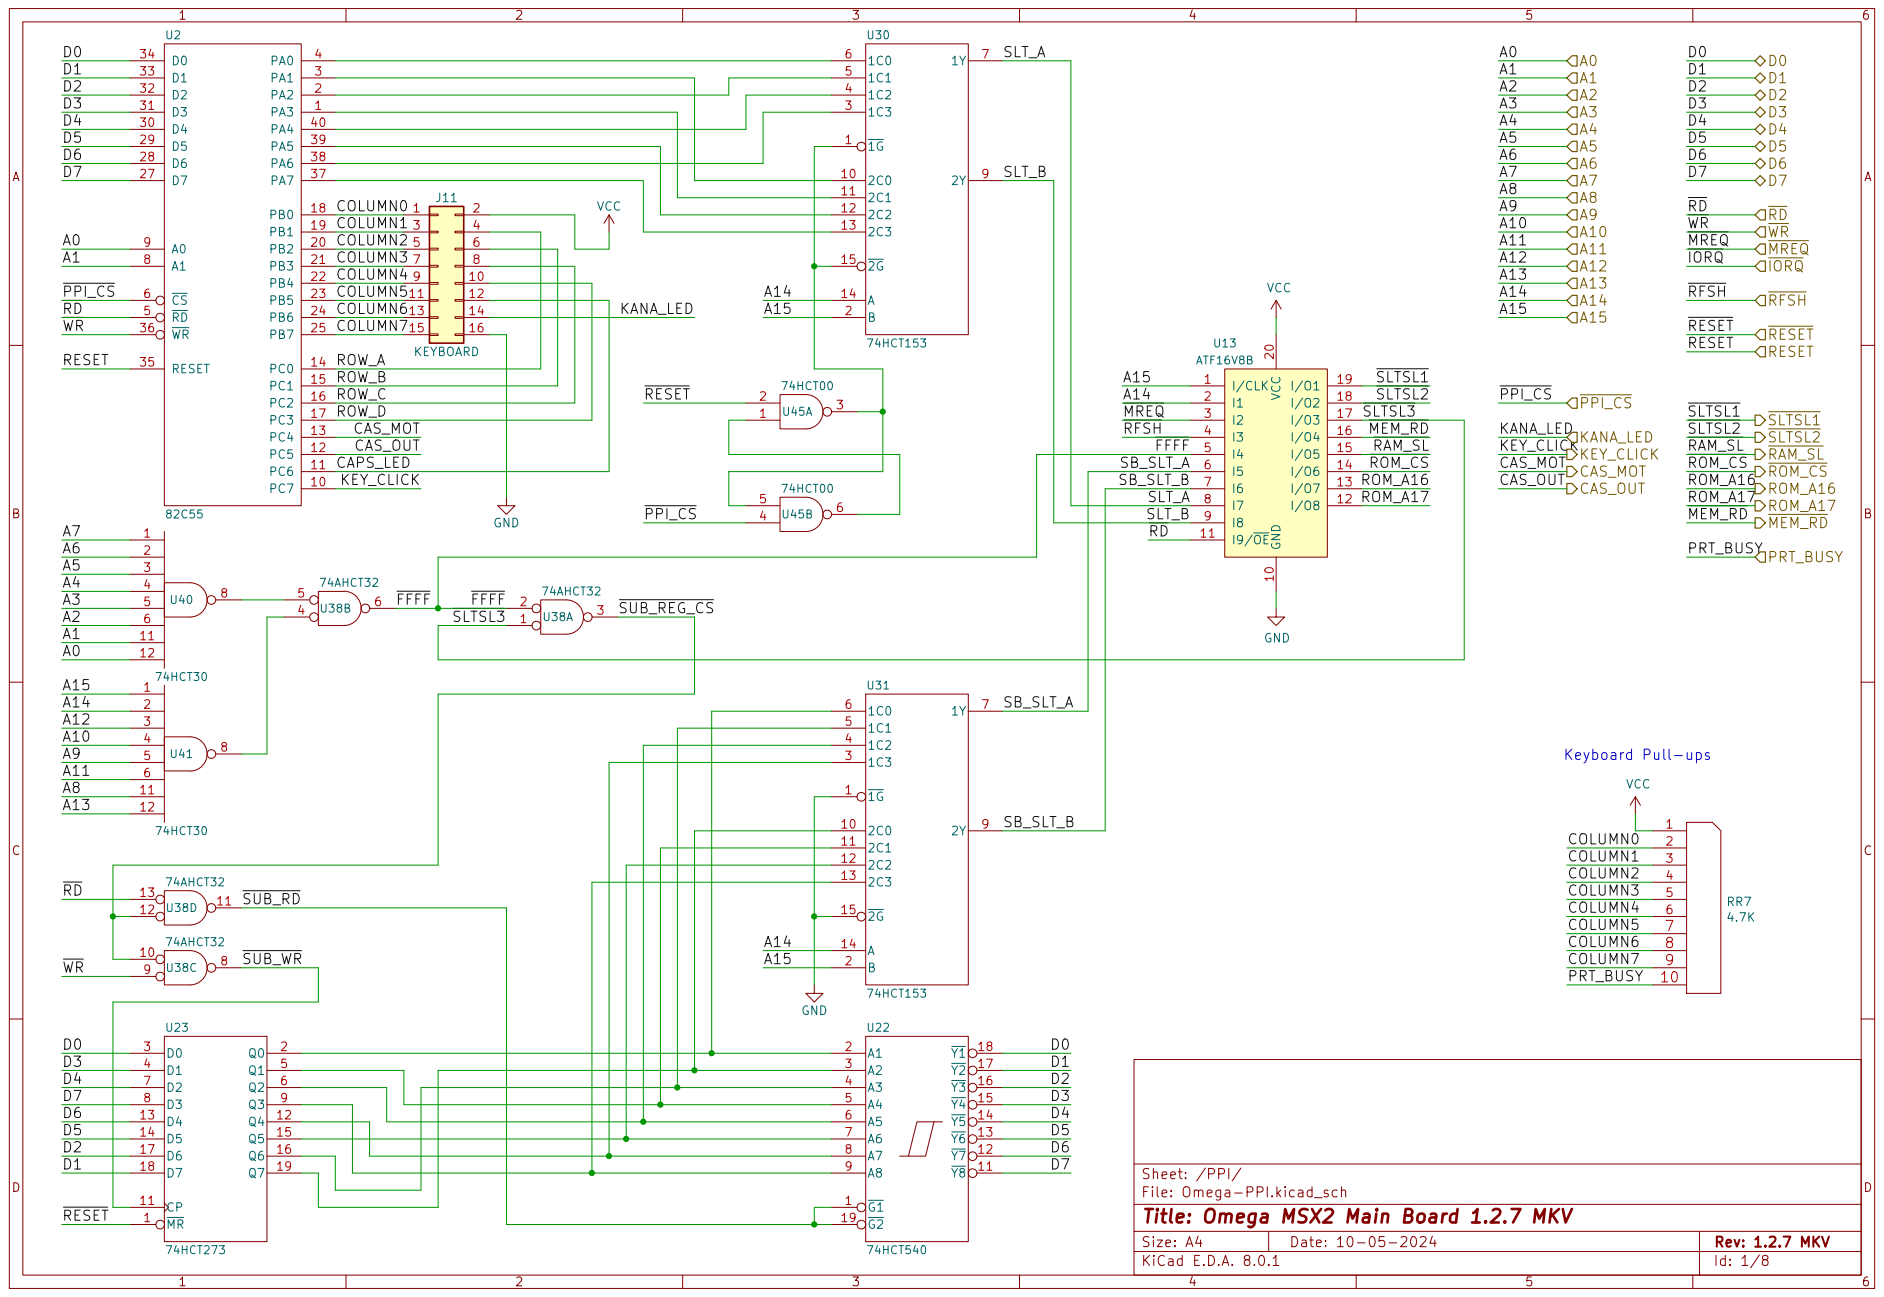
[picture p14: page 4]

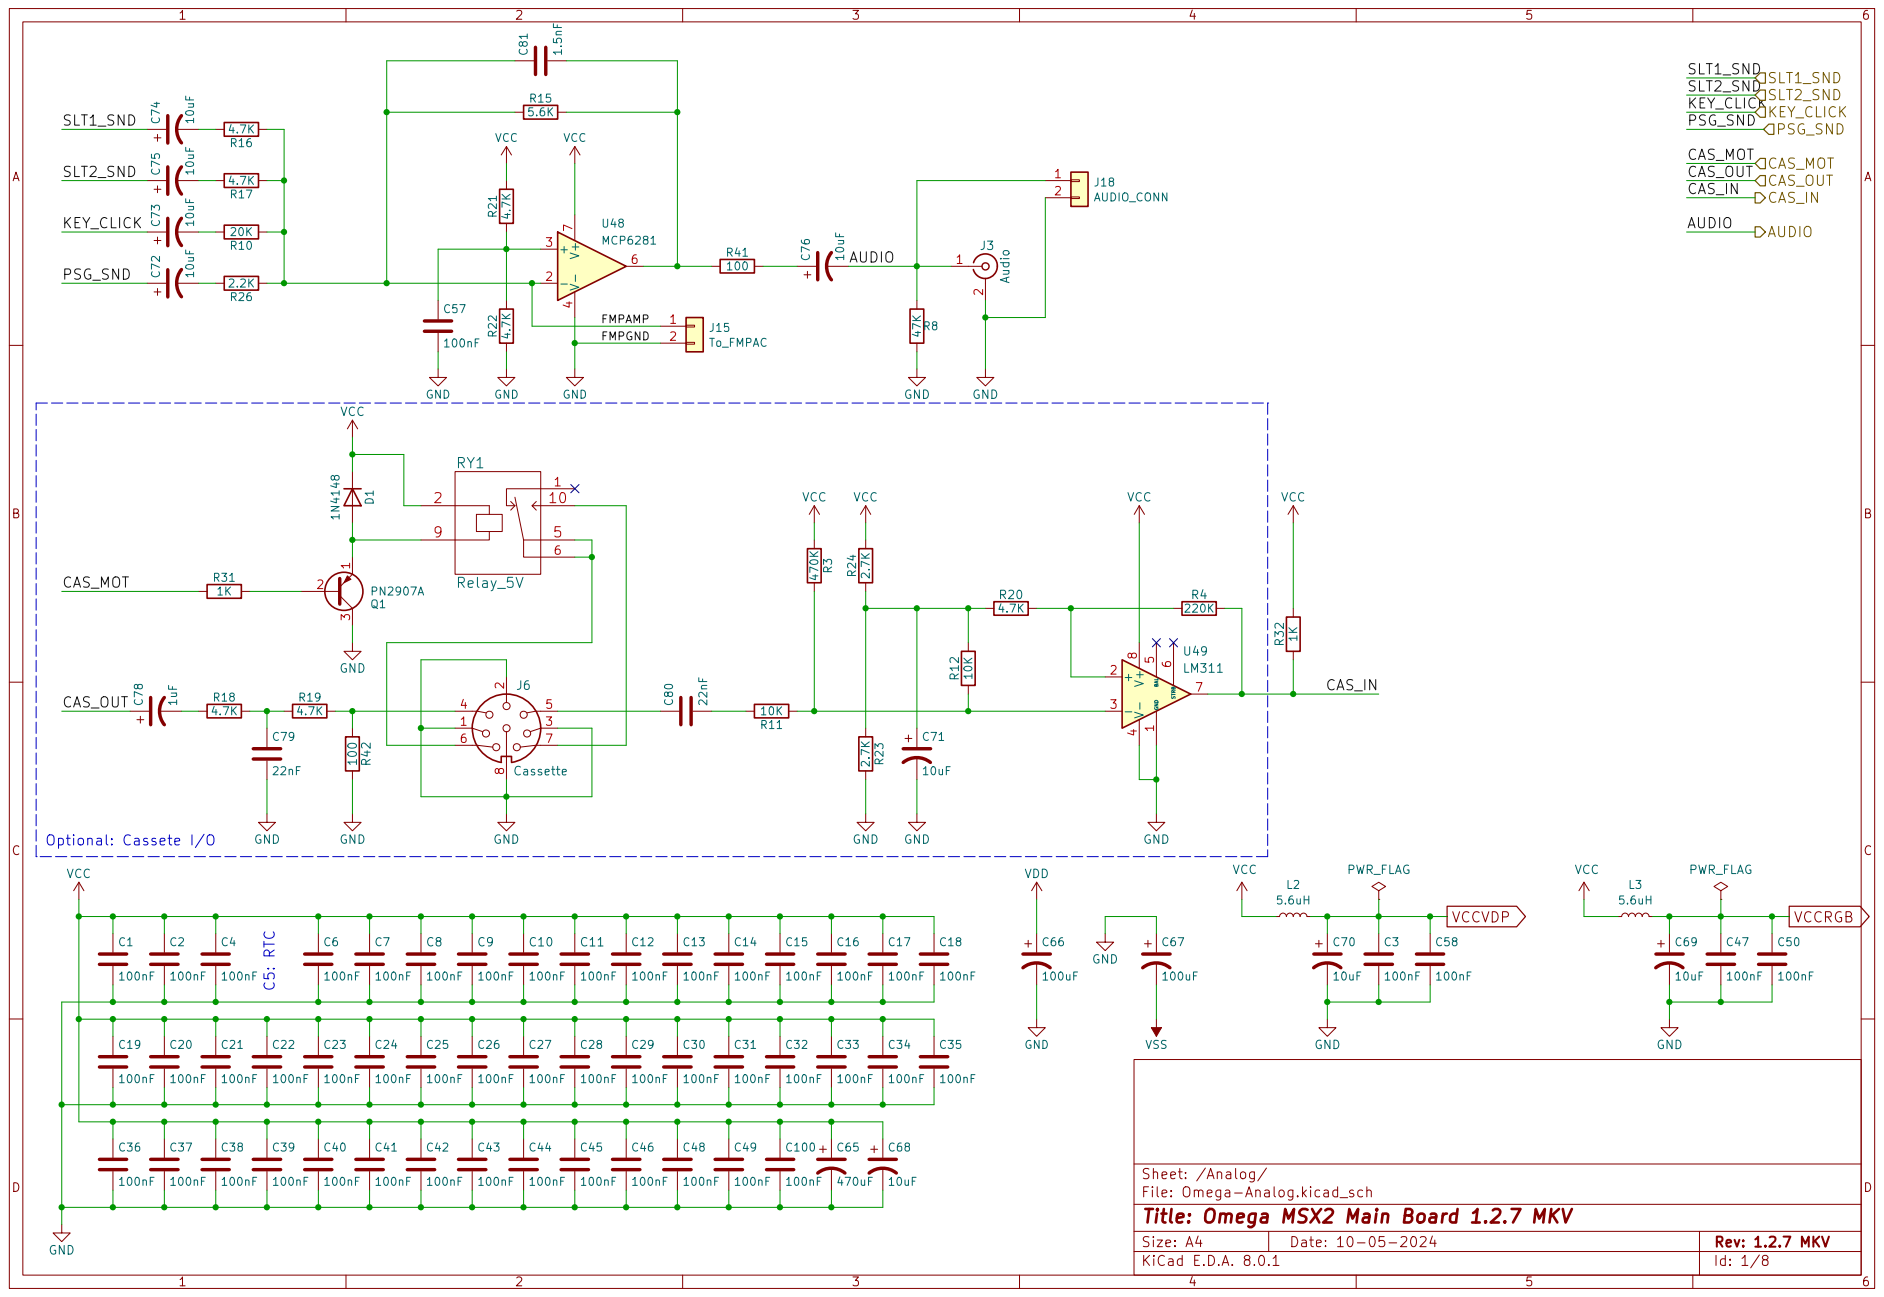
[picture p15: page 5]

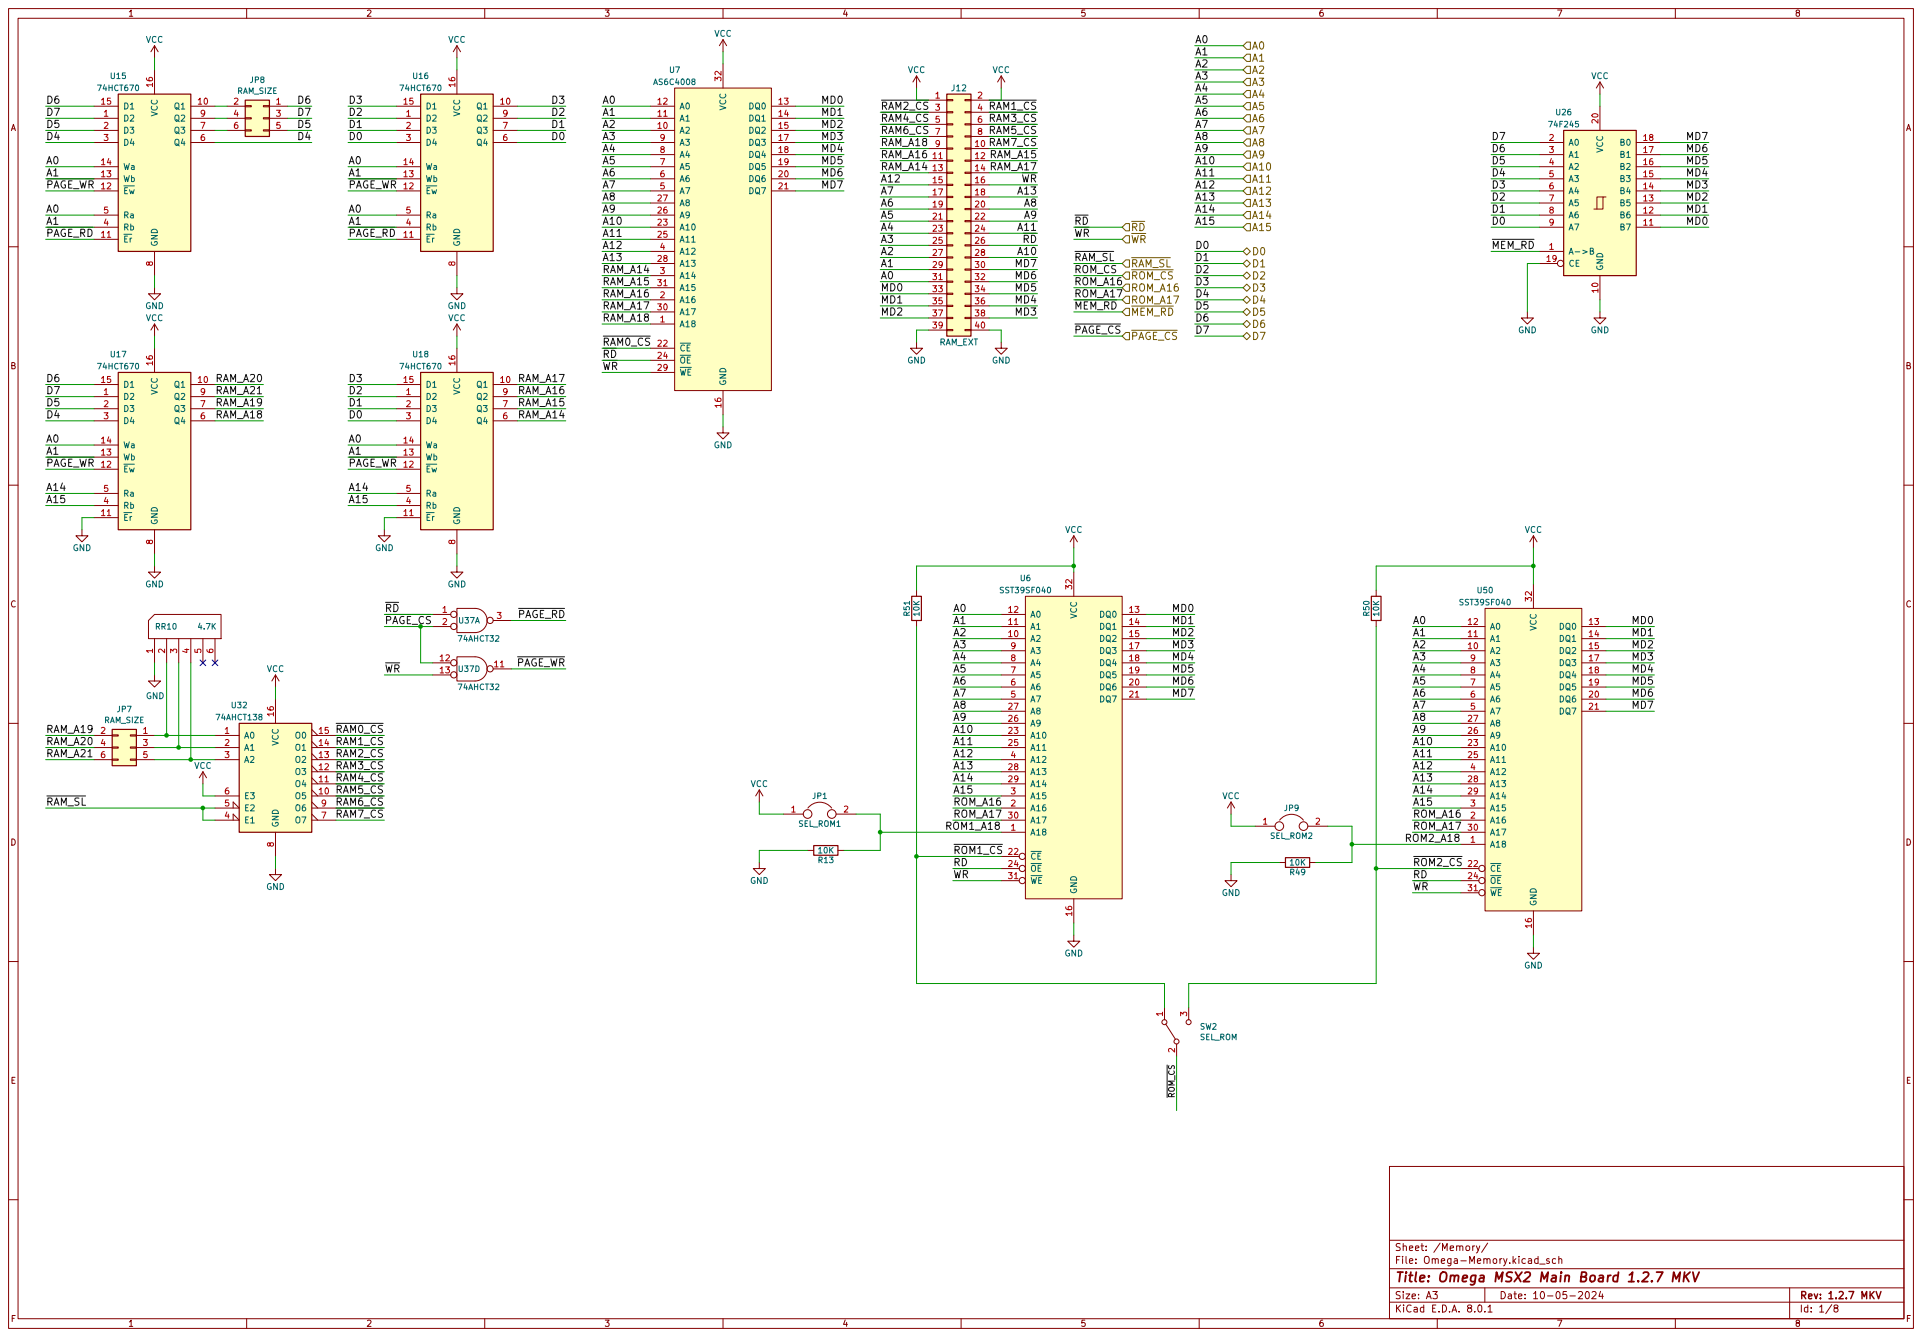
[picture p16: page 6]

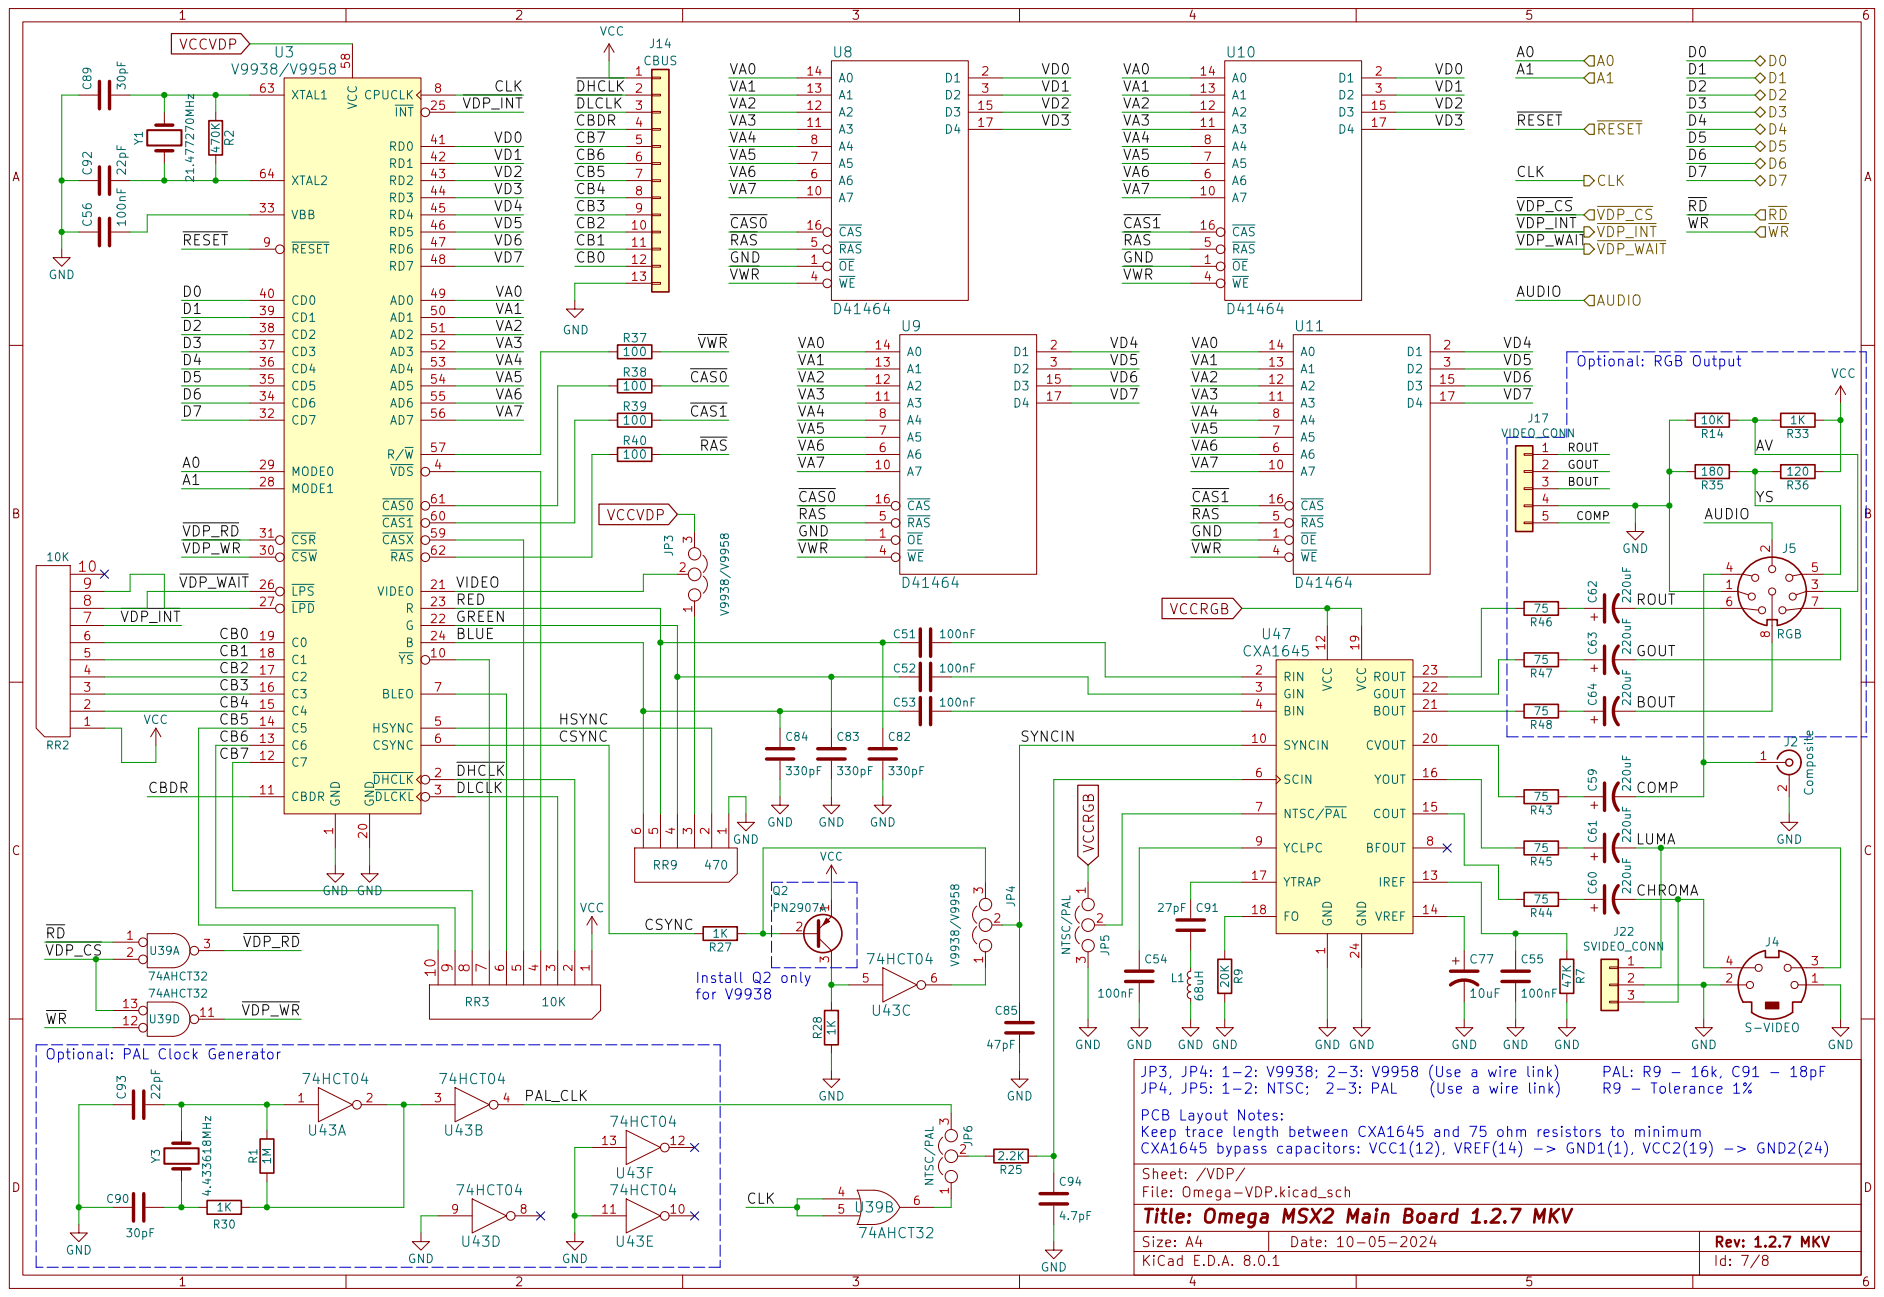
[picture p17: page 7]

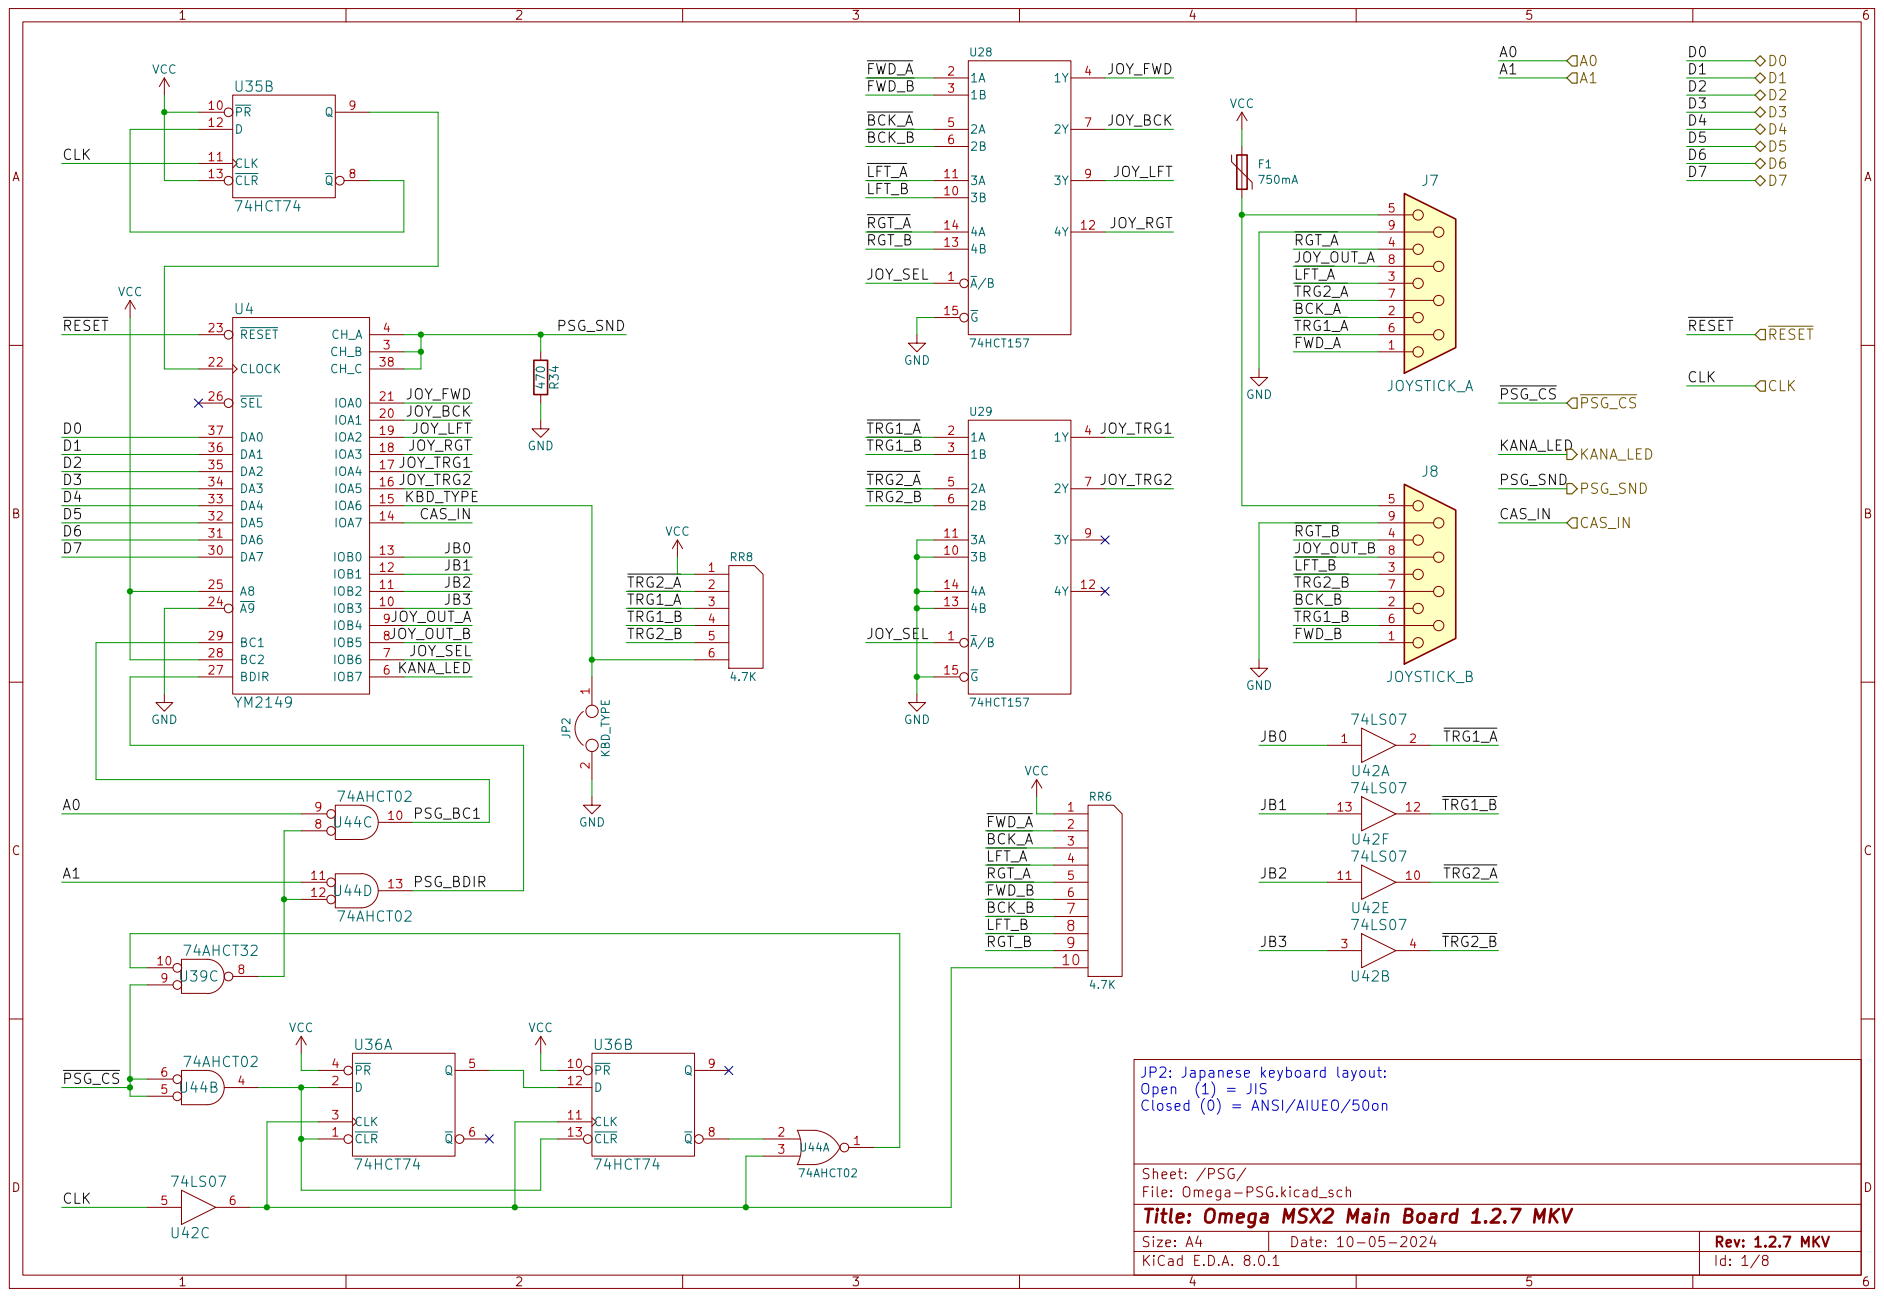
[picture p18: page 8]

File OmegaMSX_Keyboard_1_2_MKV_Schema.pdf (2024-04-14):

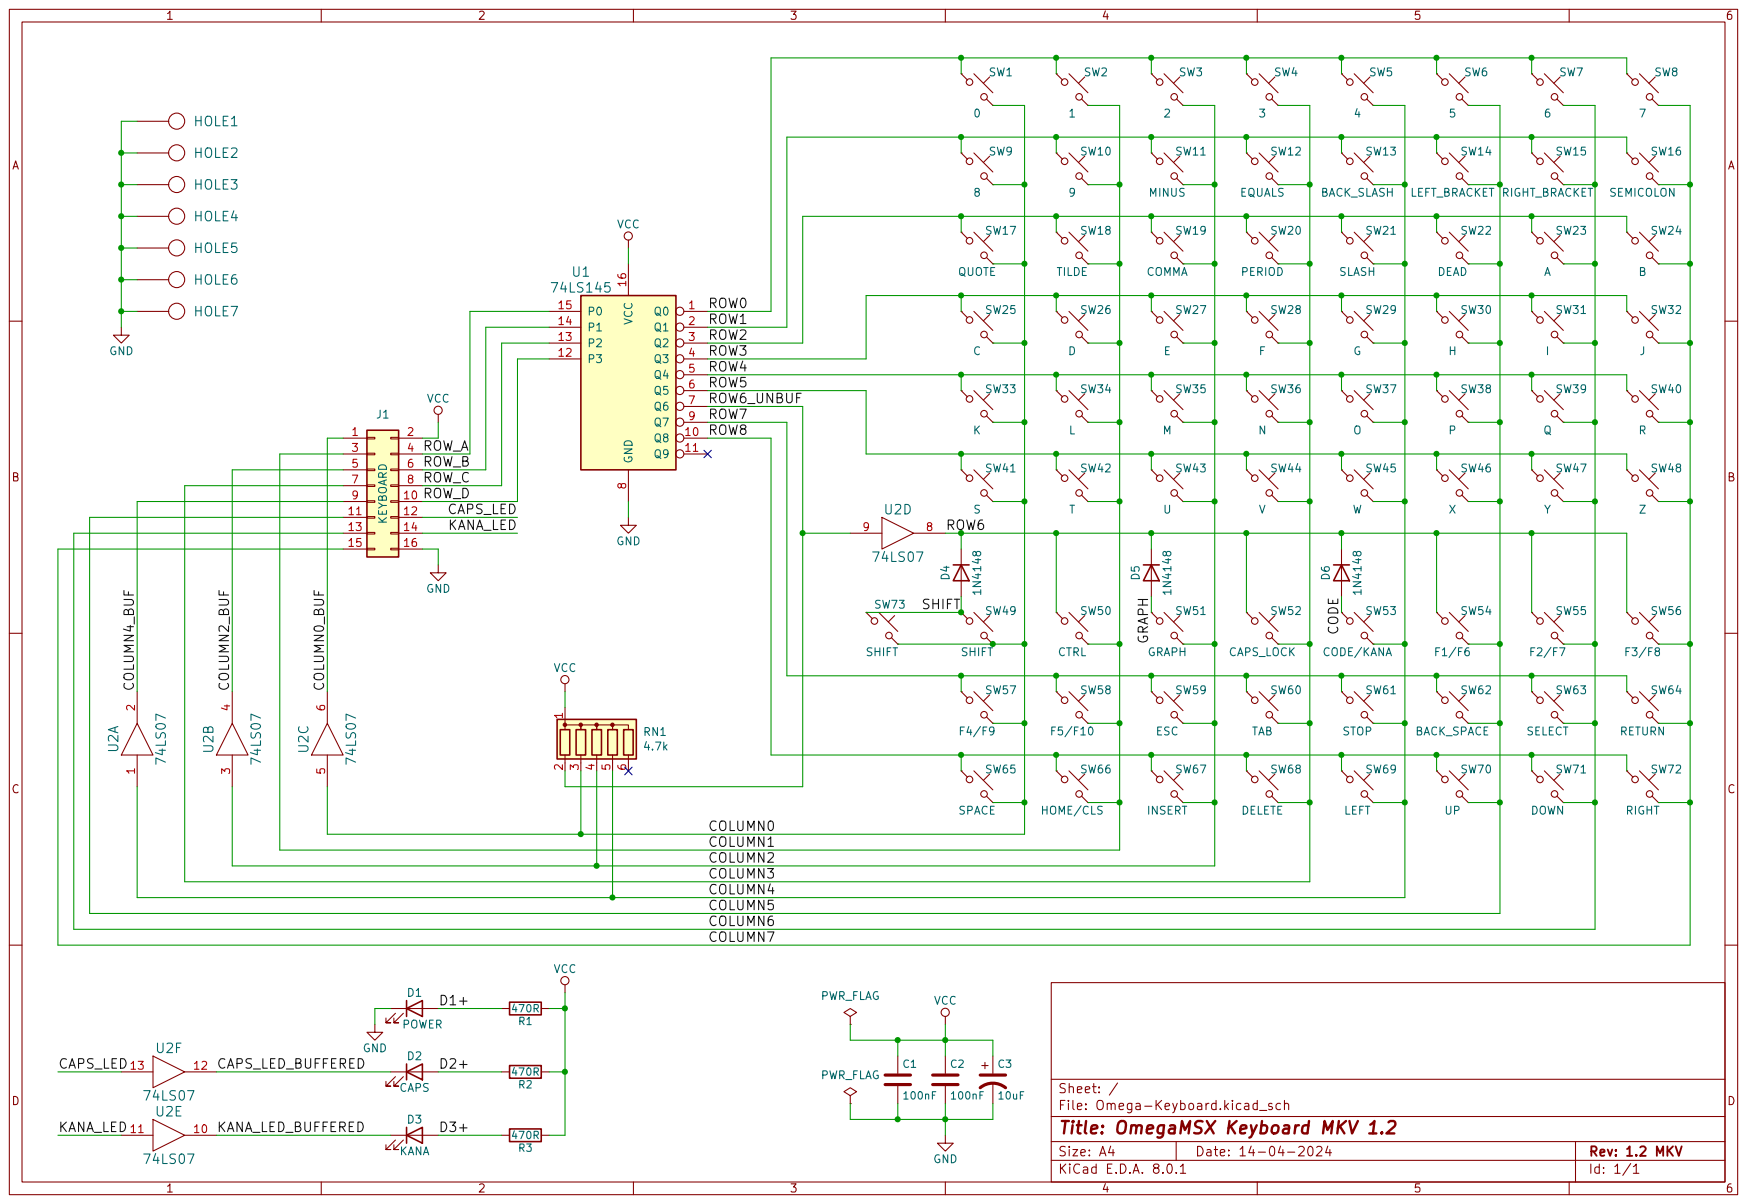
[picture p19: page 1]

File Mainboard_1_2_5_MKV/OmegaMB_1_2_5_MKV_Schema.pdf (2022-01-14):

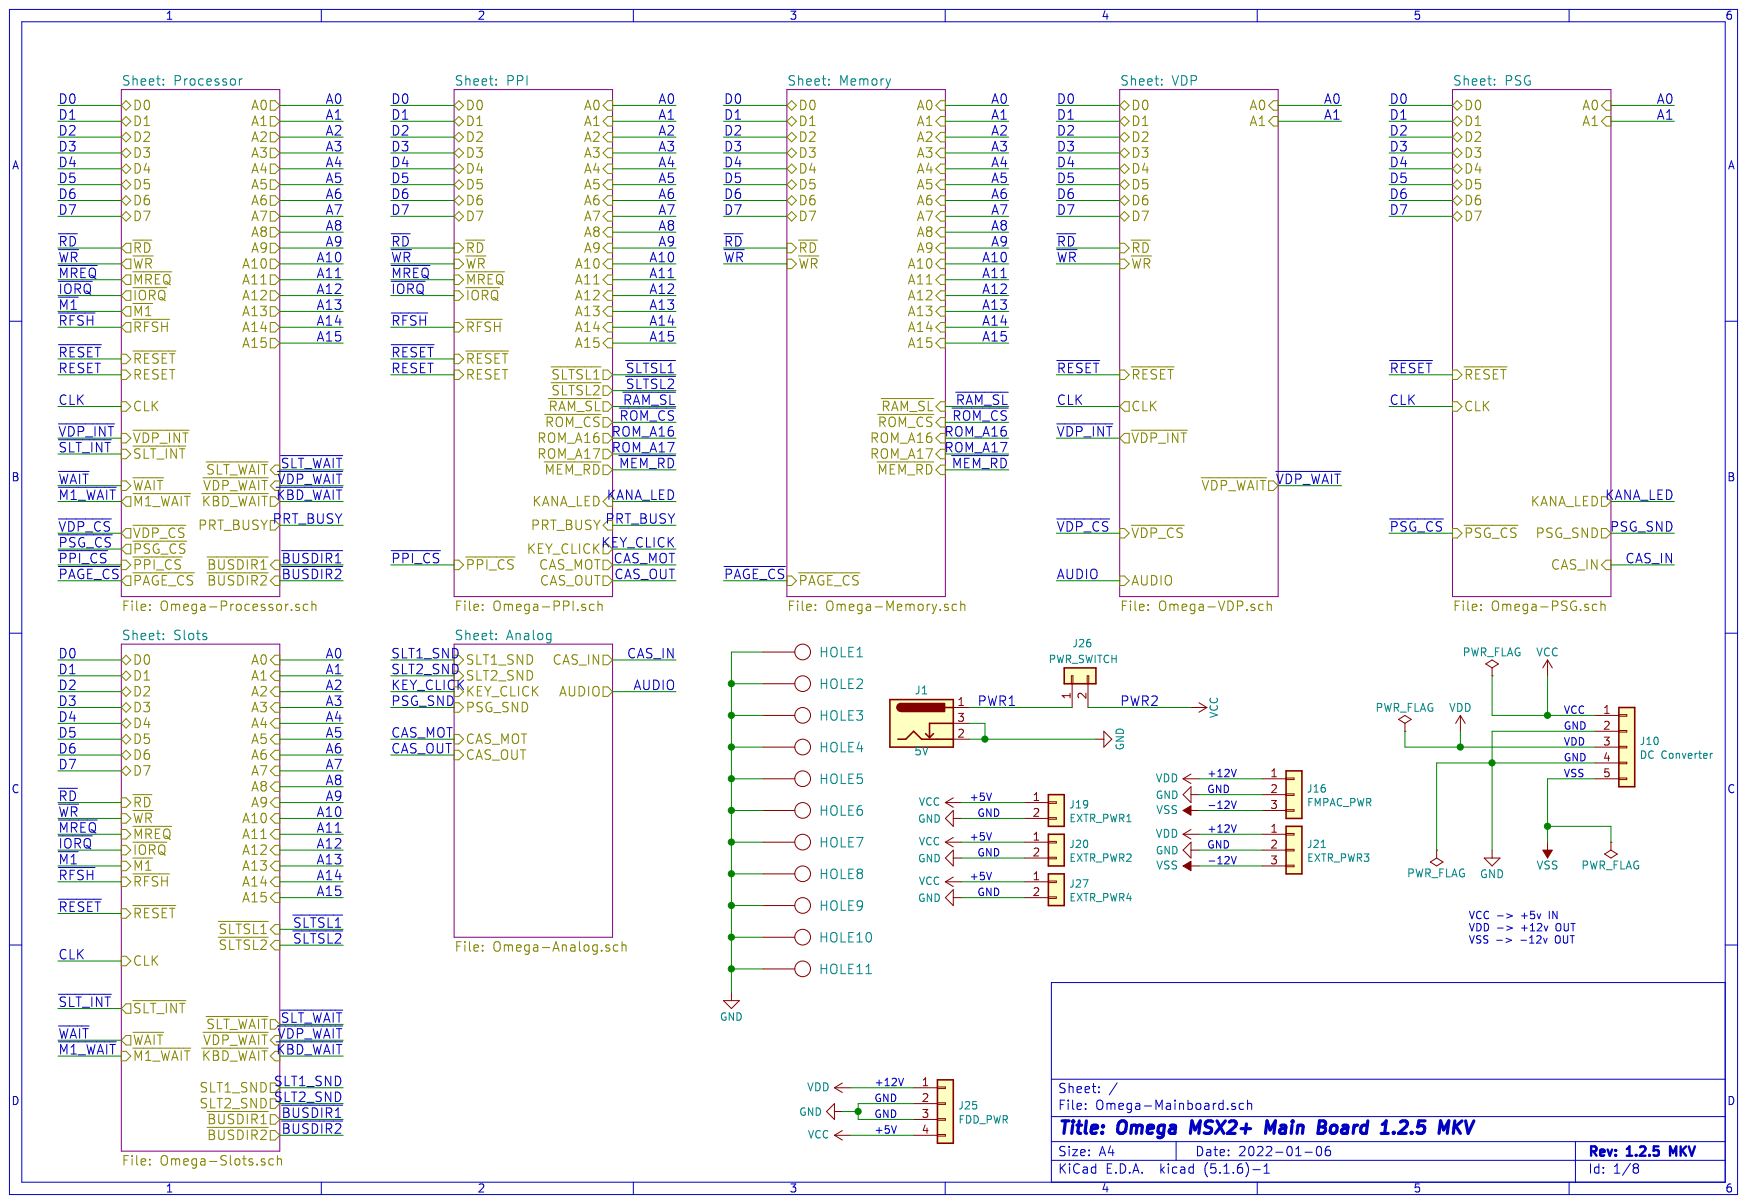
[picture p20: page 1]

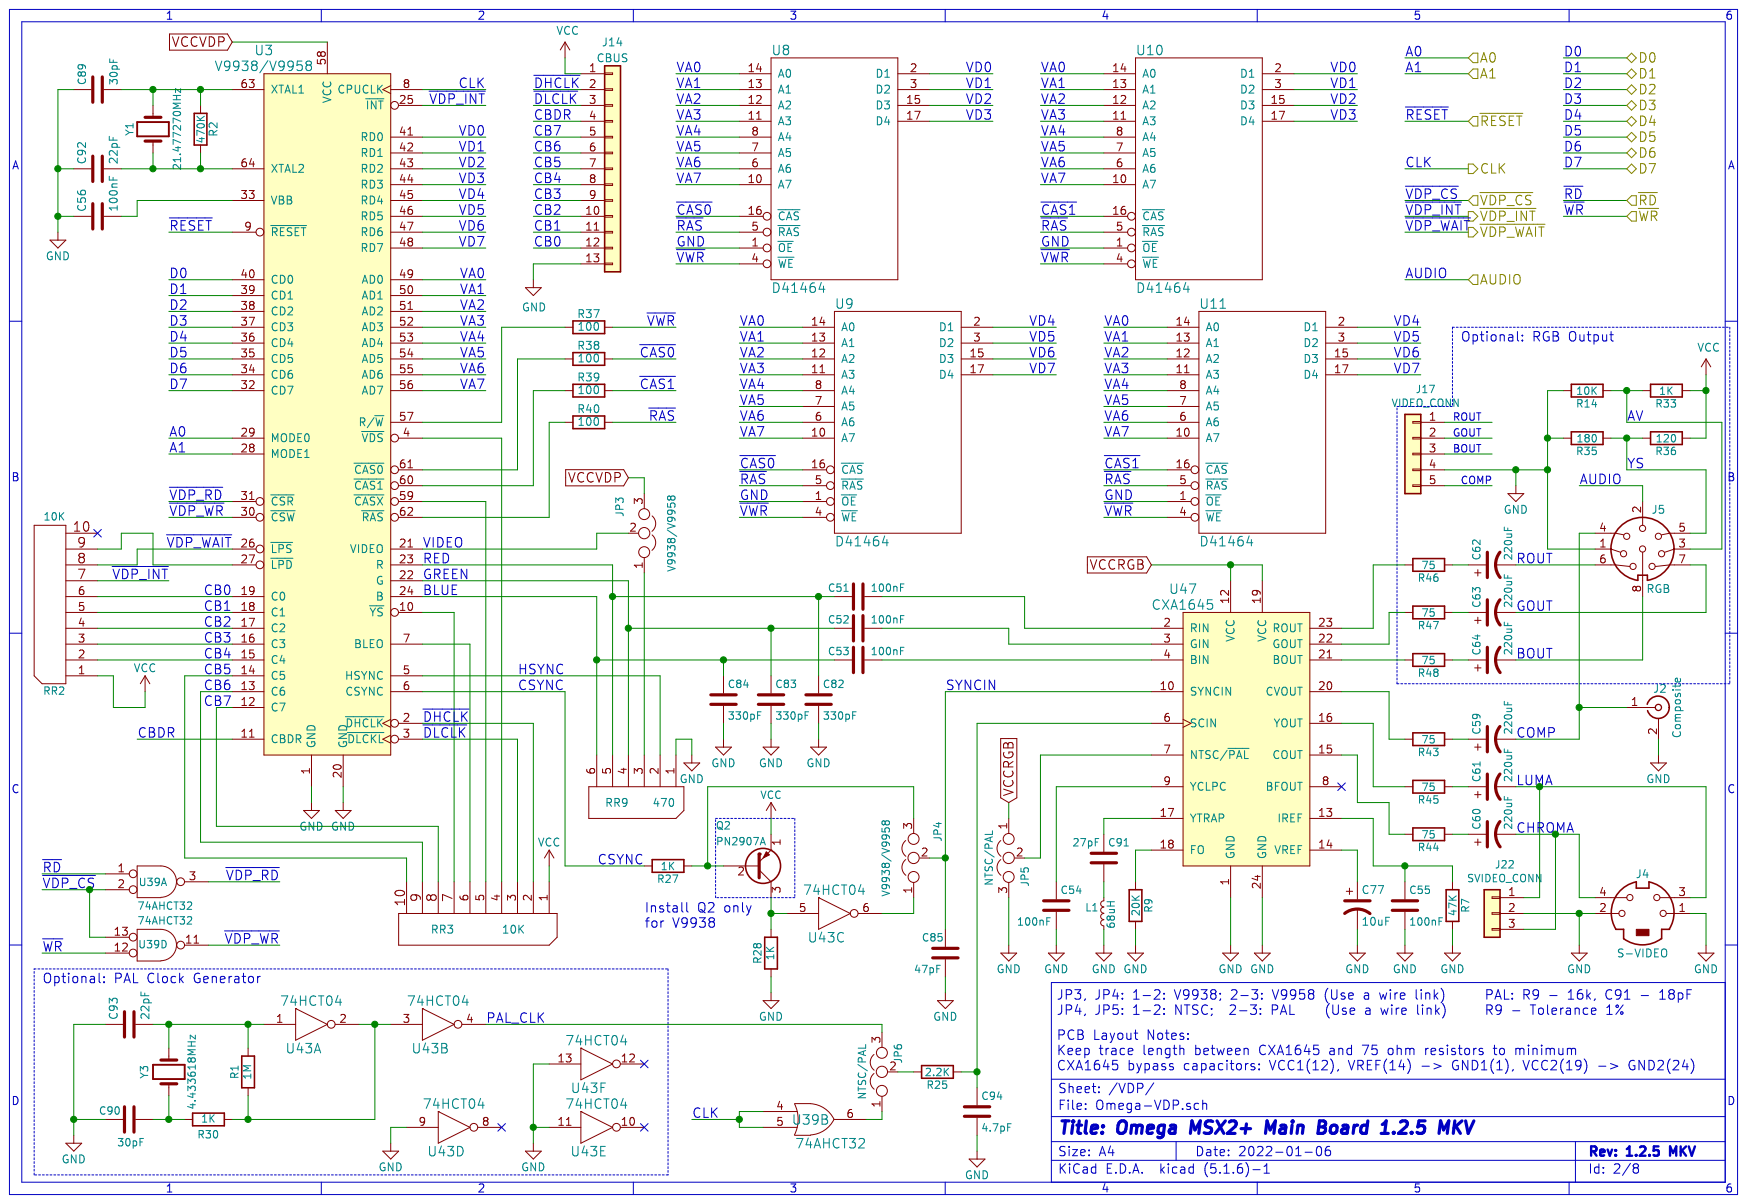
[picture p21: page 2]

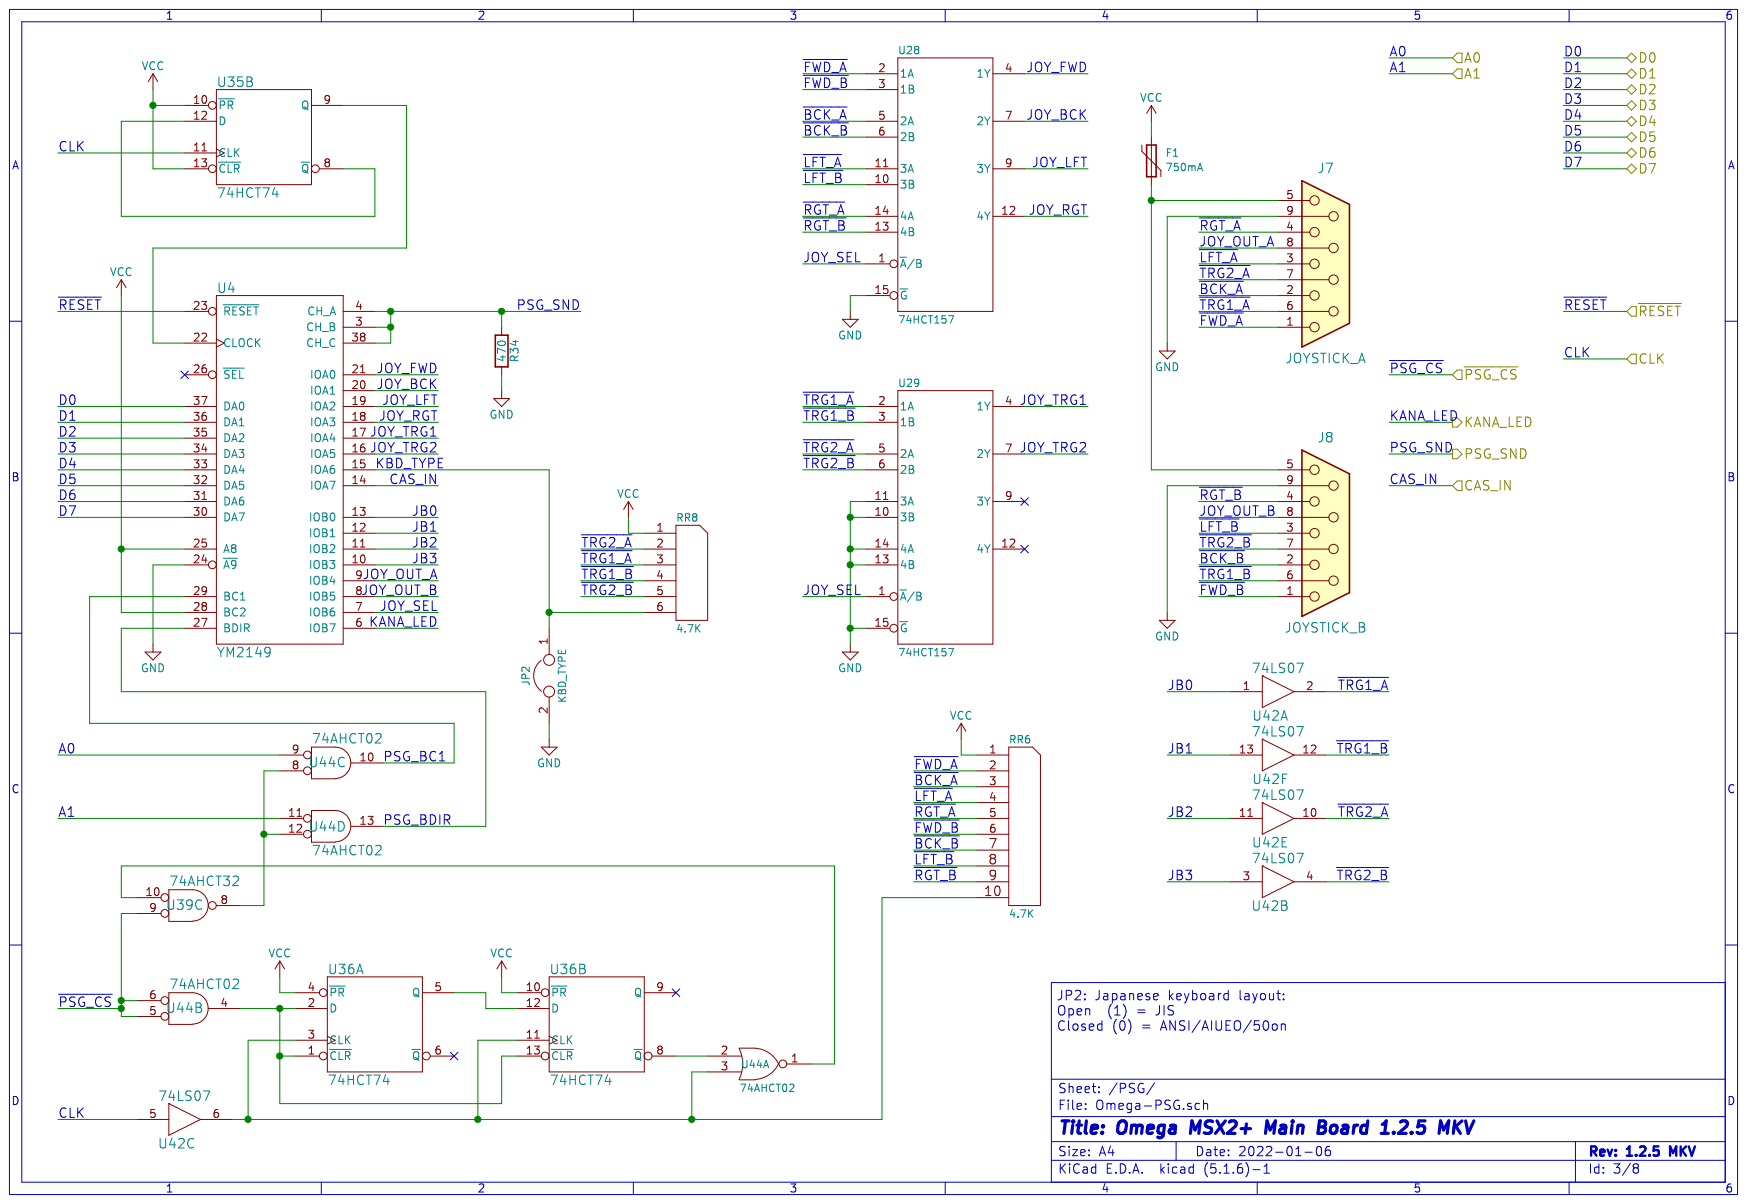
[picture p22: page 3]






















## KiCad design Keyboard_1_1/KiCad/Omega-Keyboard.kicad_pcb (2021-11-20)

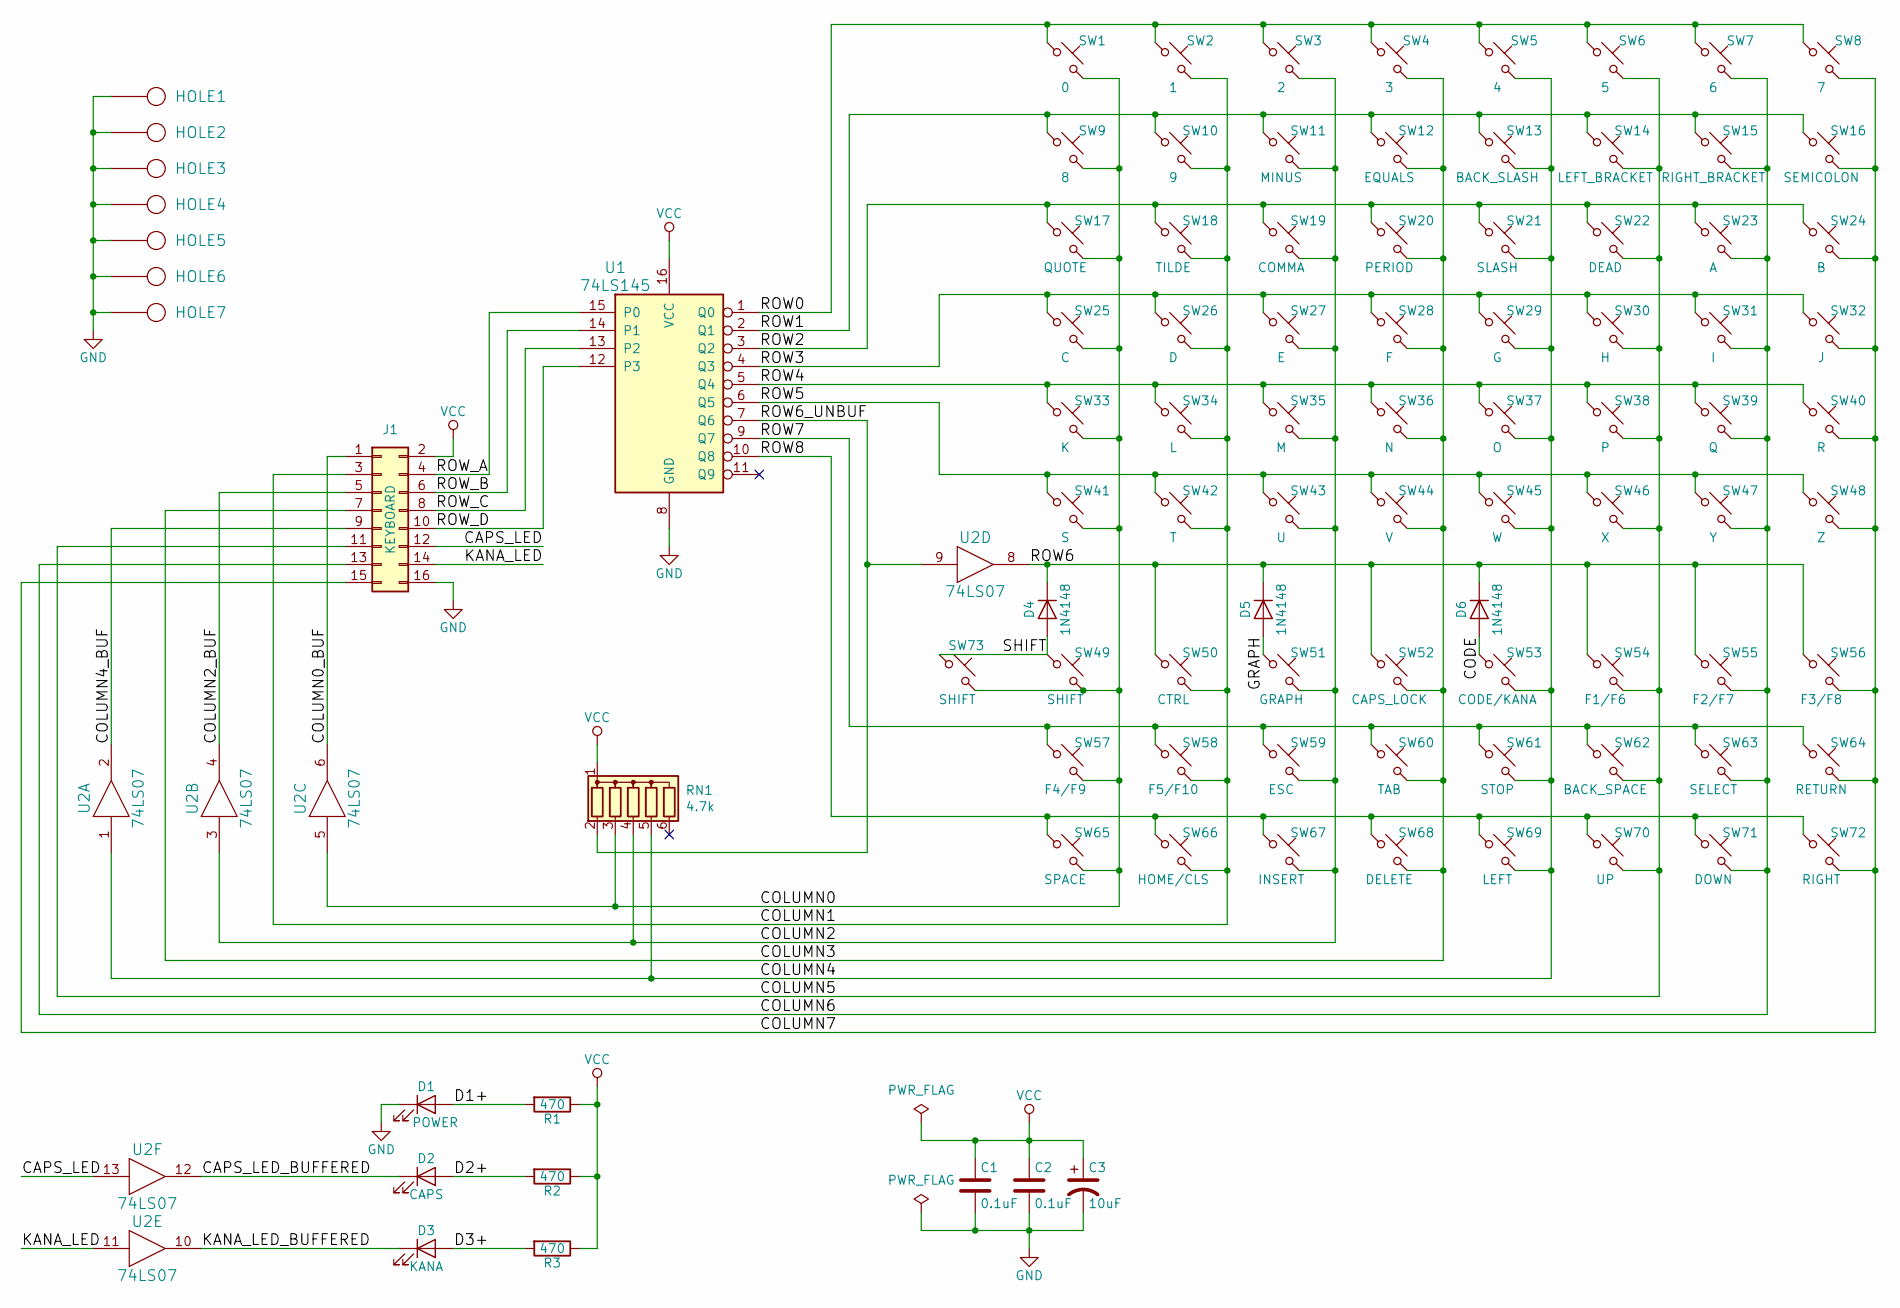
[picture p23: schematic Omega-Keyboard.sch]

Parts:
C1, C2: 0.1uF; Cap_Cer_508
C3: 10uF; Cap_Tant_508
D1: POWER; LED_3mm
D2: CAPS; CHERRY_MX_LED
D3: KANA; CHERRY_MX_LED
D4, D5, D6: 1N4148; Diode_762
HOLE1, HOLE2, HOLE3, HOLE4, HOLE5, HOLE6, HOLE7: HOLE; Hole_3mm
J1: KEYBOARD; Conn_Pin_Header_8x2_2.54mm
R1, R2, R3: 470; Res_762
RN1: 4.7k; Conn_SIL6
SW1: 0; CHERRY_PCB_100H
SW2: 1; CHERRY_PCB_100H
SW3: 2; CHERRY_PCB_100H
SW4: 3; CHERRY_PCB_100H
SW5: 4; CHERRY_PCB_100H
SW6: 5; CHERRY_PCB_100H
SW7: 6; CHERRY_PCB_100H
SW8: 7; CHERRY_PCB_100H
SW9: 8; CHERRY_PCB_100H
SW10: 9; CHERRY_PCB_100H
SW11: MINUS; CHERRY_PCB_100H
SW12: EQUALS; CHERRY_PCB_100H
SW13: BACK_SLASH; CHERRY_PCB_150H
SW14: LEFT_BRACKET; CHERRY_PCB_100H
SW15: RIGHT_BRACKET; CHERRY_PCB_100H
SW16: SEMICOLON; CHERRY_PCB_100H
SW17: QUOTE; CHERRY_PCB_100H
SW18: TILDE; CHERRY_PCB_100H
SW19: COMMA; CHERRY_PCB_100H
SW20: PERIOD; CHERRY_PCB_100H
SW21: SLASH; CHERRY_PCB_100H
SW22: DEAD; CHERRY_PCB_125H
SW23: A; CHERRY_PCB_100H
SW24: B; CHERRY_PCB_100H
SW25: C; CHERRY_PCB_100H
SW26: D; CHERRY_PCB_100H
SW27: E; CHERRY_PCB_100H
SW28: F; CHERRY_PCB_100H
SW29: G; CHERRY_PCB_100H
SW30: H; CHERRY_PCB_100H
SW31: I; CHERRY_PCB_100H
SW32: J; CHERRY_PCB_100H
SW33: K; CHERRY_PCB_100H
SW34: L; CHERRY_PCB_100H
SW35: M; CHERRY_PCB_100H
SW36: N; CHERRY_PCB_100H
SW37: O; CHERRY_PCB_100H
SW38: P; CHERRY_PCB_100H
SW39: Q; CHERRY_PCB_100H
SW40: R; CHERRY_PCB_100H
SW41: S; CHERRY_PCB_100H
SW42: T; CHERRY_PCB_100H
SW43: U; CHERRY_PCB_100H
SW44: V; CHERRY_PCB_100H
SW45: W; CHERRY_PCB_100H
SW46: X; CHERRY_PCB_100H
SW47: Y; CHERRY_PCB_100H
SW48: Z; CHERRY_PCB_100H
SW49: SHIFT; CHERRY_PCB_225H
SW50: CTRL; CHERRY_PCB_125H
SW51: GRAPH; CHERRY_PCB_125H
SW52: CAPS_LOCK; CHERRY_PCB_175H
SW53: CODE/KANA; CHERRY_PCB_125H
SW54: F1/F6; CHERRY_PCB_100H
SW55: F2/F7; CHERRY_PCB_100H
SW56: F3/F8; CHERRY_PCB_100H
SW57: F4/F9; CHERRY_PCB_100H
SW58: F5/F10; CHERRY_PCB_100H
SW59: ESC; CHERRY_PCB_100H
SW60: TAB; CHERRY_PCB_150H
SW61: STOP; CHERRY_PCB_100H
SW62: BACK_SPACE; CHERRY_PCB_200H
SW63: SELECT; CHERRY_PCB_125H
SW64: RETURN; CHERRY_PCB_225H
SW65: SPACE; CHERRY_PCB_625H
SW66: HOME/CLS; CHERRY_PCB_100H
SW67: INSERT; CHERRY_PCB_100H
SW68: DELETE; CHERRY_PCB_100H
SW69: LEFT; CHERRY_PCB_100H
SW70: UP; CHERRY_PCB_100H
SW71: DOWN; CHERRY_PCB_100H
SW72: RIGHT; CHERRY_PCB_100H
SW73: SHIFT; CHERRY_PCB_275H
U1: 74LS145; IC_DIP16_300
U2: 74LS07; IC_DIP14_300

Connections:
/CAPS_LED: J1.12, U2.13
/CAPS_LED_BUFFERED: D2.1 (K), U2.12
/CODE: D6.2 (A), SW53.1
/COLUMN0: RN1.3 (R2), SW1.2, SW9.2, SW17.2, SW25.2, SW33.2, SW41.2, SW49.2, SW57.2, SW65.2, SW73.2, U2.5
/COLUMN0_BUF: J1.1, U2.6
/COLUMN1: J1.3, SW2.2, SW10.2, SW18.2, SW26.2, SW34.2, SW42.2, SW50.2, SW58.2, SW66.2
/COLUMN2: RN1.4 (R3), SW3.2, SW11.2, SW19.2, SW27.2, SW35.2, SW43.2, SW51.2, SW59.2, SW67.2, U2.3
/COLUMN2_BUF: J1.5, U2.4
/COLUMN3: J1.7, SW4.2, SW12.2, SW20.2, SW28.2, SW36.2, SW44.2, SW52.2, SW60.2, SW68.2
/COLUMN4: RN1.5 (R4), SW5.2, SW13.2, SW21.2, SW29.2, SW37.2, SW45.2, SW53.2, SW61.2, SW69.2, U2.1
/COLUMN4_BUF: J1.9, U2.2
/COLUMN5: J1.11, SW6.2, SW14.2, SW22.2, SW30.2, SW38.2, SW46.2, SW54.2, SW62.2, SW70.2
/COLUMN6: J1.13, SW7.2, SW15.2, SW23.2, SW31.2, SW39.2, SW47.2, SW55.2, SW63.2, SW71.2
/COLUMN7: J1.15, SW8.2, SW16.2, SW24.2, SW32.2, SW40.2, SW48.2, SW56.2, SW64.2, SW72.2
/D1+: D1.2 (A), R1.2
/D2+: D2.2 (A), R2.2
/D3+: D3.2 (A), R3.2
/GRAPH: D5.2 (A), SW51.1
/KANA_LED: J1.14, U2.11
/KANA_LED_BUFFERED: D3.1 (K), U2.10
/ROW0: SW1.1, SW2.1, SW3.1, SW4.1, SW5.1, SW6.1, SW7.1, SW8.1, U1.1 (Q0)
/ROW1: SW9.1, SW10.1, SW11.1, SW12.1, SW13.1, SW14.1, SW15.1, SW16.1, U1.2 (Q1)
/ROW2: SW17.1, SW18.1, SW19.1, SW20.1, SW21.1, SW22.1, SW23.1, SW24.1, U1.3 (Q2)
/ROW3: SW25.1, SW26.1, SW27.1, SW28.1, SW29.1, SW30.1, SW31.1, SW32.1, U1.4 (Q3)
/ROW4: SW33.1, SW34.1, SW35.1, SW36.1, SW37.1, SW38.1, SW39.1, SW40.1, U1.5 (Q4)
/ROW5: SW41.1, SW42.1, SW43.1, SW44.1, SW45.1, SW46.1, SW47.1, SW48.1, U1.6 (Q5)
/ROW6: D4.1 (K), D5.1 (K), D6.1 (K), SW50.1, SW52.1, SW54.1, SW55.1, SW56.1, U2.8
/ROW6_UNBUF: RN1.2 (R1), U1.7 (Q6), U2.9
/ROW7: SW57.1, SW58.1, SW59.1, SW60.1, SW61.1, SW62.1, SW63.1, SW64.1, U1.9 (Q7)
/ROW8: SW65.1, SW66.1, SW67.1, SW68.1, SW69.1, SW70.1, SW71.1, SW72.1, U1.10 (Q8)
/ROW_A: J1.4, U1.15 (P0)
/ROW_B: J1.6, U1.14 (P1)
/ROW_C: J1.8, U1.13 (P2)
/ROW_D: J1.10, U1.12 (P3)
/SHIFT: D4.2 (A), SW49.1, SW73.1
GND: C1.2, C2.2, C3.2, D1.1 (K), HOLE1.1, HOLE2.1, HOLE3.1, HOLE4.1, HOLE5.1, HOLE6.1, HOLE7.1, J1.16, U1.8 (GND), U2.7 (GND)
VCC: C1.1, C2.1, C3.1, J1.2, R1.1, R2.1, R3.1, RN1.1 (common), U1.16 (VCC), U2.14 (VCC)

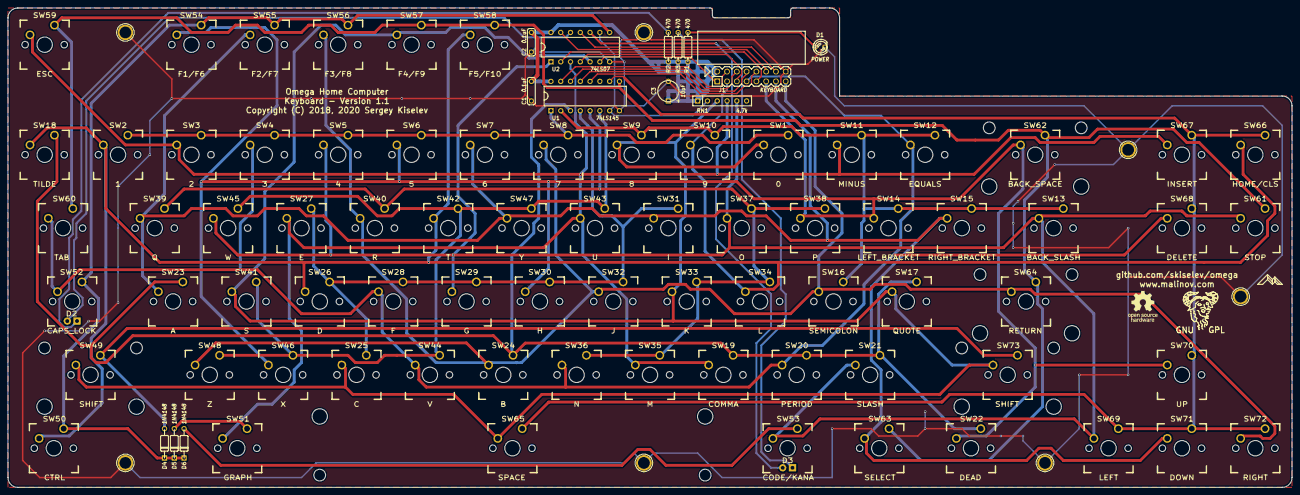
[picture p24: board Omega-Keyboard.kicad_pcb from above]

Board: 2 copper layers, 333.4 x 124.5 mm, 96 parts (0 on the bottom side), 37 nets.

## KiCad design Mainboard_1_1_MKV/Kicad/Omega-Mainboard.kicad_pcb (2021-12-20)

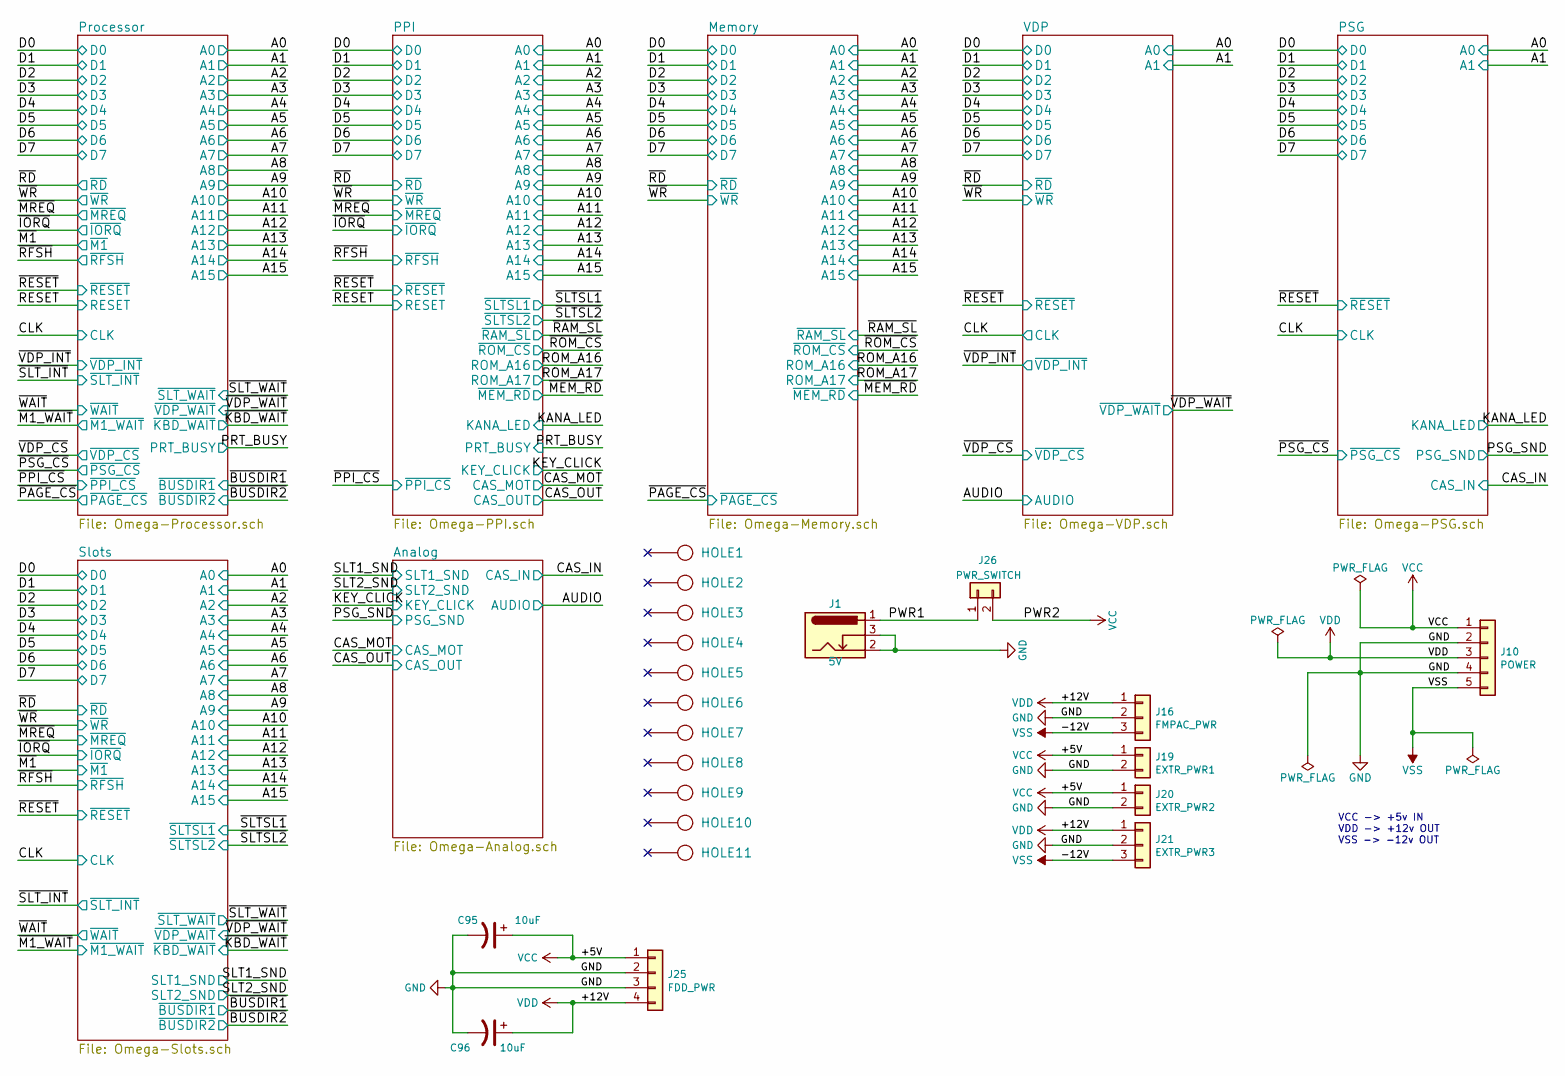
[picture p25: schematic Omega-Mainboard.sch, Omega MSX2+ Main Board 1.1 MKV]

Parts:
C95, C96: 10uF; CP_Radial_D5.0mm_P2.50mm
HOLE1, HOLE2, HOLE3, HOLE4, HOLE5, HOLE6, HOLE7, HOLE8, HOLE9, HOLE10, HOLE11: HOLE; MountingHole_3mm_Pad
J1: 5V; BarrelJack_Horizontal
J10: POWER; Molex_KK-254_AE-6410-05A_1x05_P2.54mm_Vertical
J16: FMPAC_PWR; Molex_KK-254_AE-6410-03A_1x03_P2.54mm_Vertical
J19: EXTR_PWR1; Molex_KK-254_AE-6410-02A_1x02_P2.54mm_Vertical
J20: EXTR_PWR2; Molex_KK-254_AE-6410-02A_1x02_P2.54mm_Vertical
J21: EXTR_PWR3; Molex_KK-254_AE-6410-03A_1x03_P2.54mm_Vertical
J25: FDD_PWR; PinHeader_1x04_P2.54mm_Horizontal
J26: PWR_SWITCH; Molex_KK-254_AE-6410-02A_1x02_P2.54mm_Vertical

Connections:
/PWR1: J1.1, J26.1
GND: C95.2, C96.2, J1.2, J1.3, J10.2, J10.4, J16.2, J19.2, J20.2, J21.2, J25.2, J25.3; also elsewhere on the board
VCC: C95.1, J10.1, J19.1, J20.1, J25.1, J26.2; also elsewhere on the board
VDD: C96.1, J10.3, J16.1, J21.1, J25.4; also elsewhere on the board
VSS: J10.5, J16.3, J21.3; also elsewhere on the board

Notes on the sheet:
VCC -> +5v IN VDD -> +12v OUT VSS -> -12v OUT

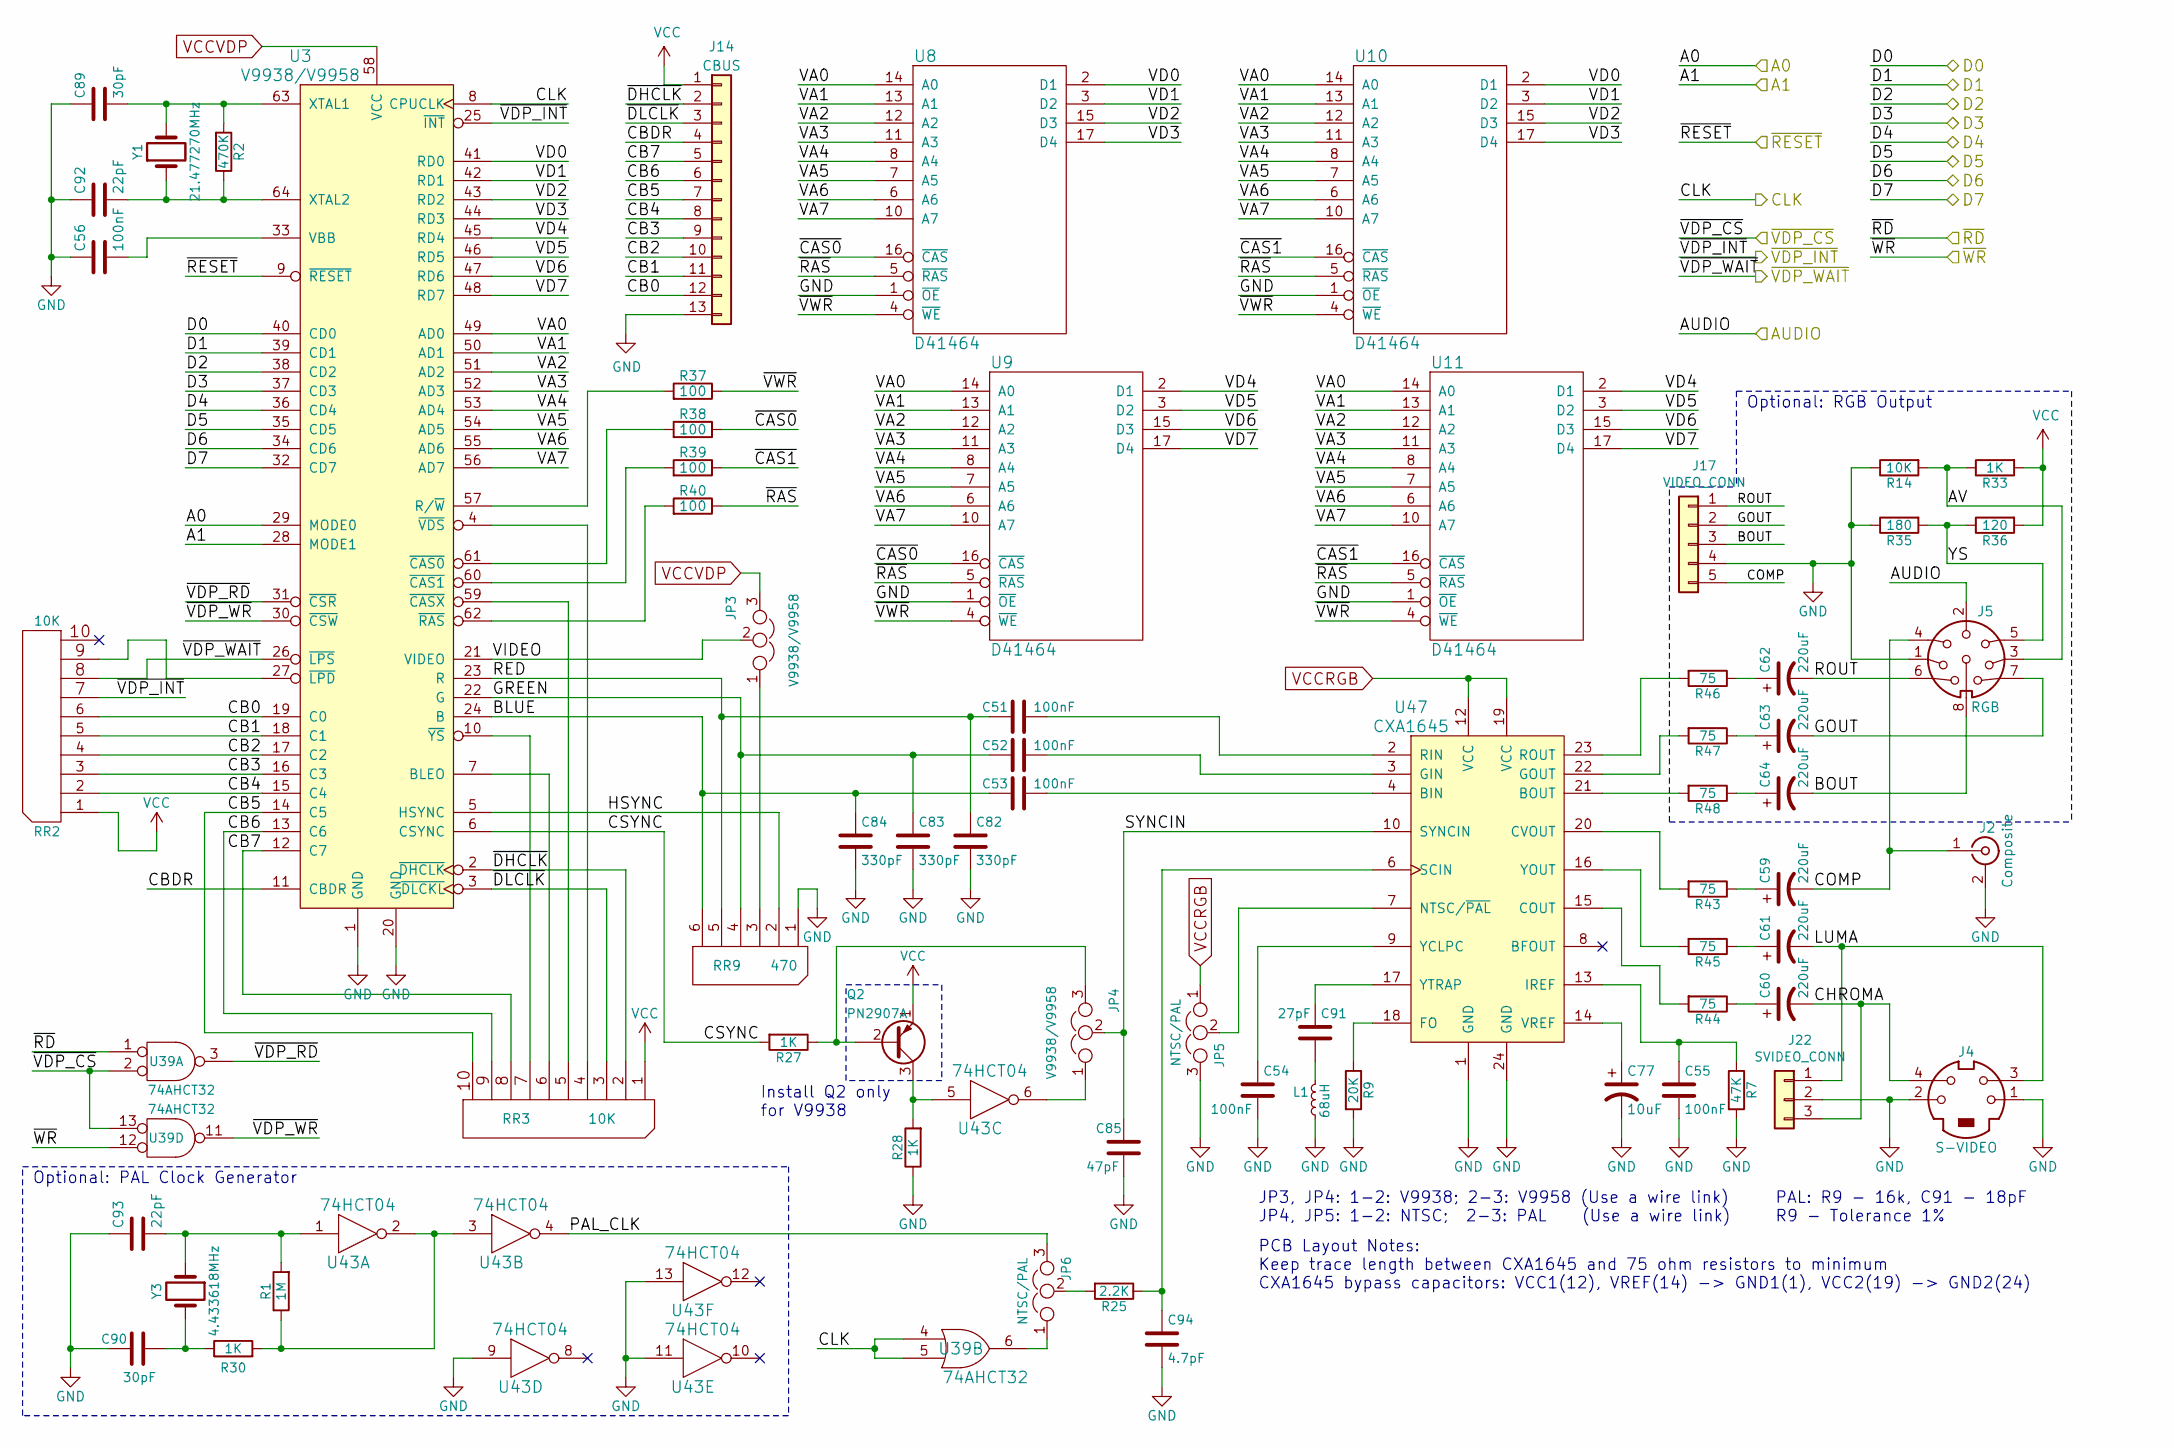
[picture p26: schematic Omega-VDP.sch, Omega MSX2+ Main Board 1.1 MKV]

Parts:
C51, C52, C53, C54, C55, C56: 100nF; C_1206_3216Metric_Pad1.42x1.75mm_HandSolder
C59, C60, C61, C62, C63, C64: 220uF; CP_Radial_D10.0mm_P5.00mm
C77: 10uF; CP_Radial_D5.0mm_P2.50mm
C82, C83, C84: 330pF; C_1206_3216Metric_Pad1.42x1.75mm_HandSolder
C85: 47pF; C_1206_3216Metric_Pad1.42x1.75mm_HandSolder
C89, C90: 30pF; C_1206_3216Metric_Pad1.42x1.75mm_HandSolder
C91: 27pF; C_1206_3216Metric_Pad1.42x1.75mm_HandSolder
C92, C93: 22pF; C_1206_3216Metric_Pad1.42x1.75mm_HandSolder
C94: 4.7pF; C_1206_3216Metric_Pad1.42x1.75mm_HandSolder
J2: Composite; Conn_RCA_Right
J4: S-VIDEO; Conn_Mini_DIN_4pin
J5: RGB; DIN8
J14: CBUS; PinHeader_1x13_P2.54mm_Vertical
J17: VIDEO_CONN; Molex_KK-254_AE-6410-05A_1x05_P2.54mm_Vertical
J22: SVIDEO_CONN; Molex_KK-254_AE-6410-03A_1x03_P2.54mm_Vertical
JP3, JP4: V9938/V9958; PinHeader_1x03_P2.54mm_Vertical
JP5, JP6: NTSC/PAL; PinHeader_1x03_P2.54mm_Vertical
L1: 68uH; L_1206_3216Metric_Pad1.42x1.75mm_HandSolder
Q2: PN2907A; TO-92L_Inline_Wide
R1: 1M; R_1206_3216Metric_Pad1.42x1.75mm_HandSolder
R2: 470K; R_1206_3216Metric_Pad1.42x1.75mm_HandSolder
R7: 47K; R_1206_3216Metric_Pad1.42x1.75mm_HandSolder
R9: 20K; R_1206_3216Metric_Pad1.42x1.75mm_HandSolder
R14: 10K; R_1206_3216Metric_Pad1.42x1.75mm_HandSolder
R25: 2.2K; R_1206_3216Metric_Pad1.42x1.75mm_HandSolder
R27, R28, R30, R33: 1K; R_1206_3216Metric_Pad1.42x1.75mm_HandSolder
R35: 180; R_1206_3216Metric_Pad1.42x1.75mm_HandSolder
R36: 120; R_1206_3216Metric_Pad1.42x1.75mm_HandSolder
R37, R38, R39, R40: 100; R_1206_3216Metric_Pad1.42x1.75mm_HandSolder
R43, R44, R45, R46, R47, R48: 75; R_1206_3216Metric_Pad1.42x1.75mm_HandSolder
RR2, RR3: 10K; R_Array_SIP10
RR9: 470; R_Array_SIP6
U3: V9938/V9958; IC_SDIP64_600
U8, U9, U10, U11: D41464; DIP-18_W7.62mm_Socket
U39: 74AHCT32; DIP-14_W7.62mm_Socket
U43: 74HCT04; DIP-14_W7.62mm_Socket
U47: CXA1645; IC_DIP24_400
Y1: 21.477270MHz; Crystal_HC49-U_Vertical
Y3: 4.433618MHz; Crystal_HC49-U_Vertical

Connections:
/A0: U3.29 (MODE0); also elsewhere on the board
/A1: U3.28 (MODE1); also elsewhere on the board
/AUDIO: J5.2; also elsewhere on the board
/CLK: U3.8 (CPUCLK), U39.4, U39.5; also elsewhere on the board
/D0: U3.40 (CD0); also elsewhere on the board
/D1: U3.39 (CD1); also elsewhere on the board
/D2: U3.38 (CD2); also elsewhere on the board
/D3: U3.37 (CD3); also elsewhere on the board
/D4: U3.36 (CD4); also elsewhere on the board
/D5: U3.35 (CD5); also elsewhere on the board
/D6: U3.34 (CD6); also elsewhere on the board
/D7: U3.32 (CD7); also elsewhere on the board
/VDP/AV: J5.3, R14.2, R33.1
/VDP/BLUE: C53.1, C84.1, RR9.6, U3.24 (B)
/VDP/BOUT: C64.2, J5.8, J17.3
/VDP/CB0: J14.12, RR2.6, U3.19 (C0)
/VDP/CB1: J14.11, RR2.5, U3.18 (C1)
/VDP/CB2: J14.10, RR2.4, U3.17 (C2)
/VDP/CB3: J14.9, RR2.3, U3.16 (C3)
/VDP/CB4: J14.8, RR2.2, U3.15 (C4)
/VDP/CB5: J14.7, RR3.10, U3.14 (C5)
/VDP/CB6: J14.6, RR3.9, U3.13 (C6)
/VDP/CB7: J14.5, RR3.8, U3.12 (C7)
/VDP/CBDR: J14.4, U3.11 (CBDR)
/VDP/CHROMA: C60.2, J4.4, J22.3
/VDP/COMP: C59.2, J2.1 (In), J5.4, J17.5
/VDP/CSYNC: R27.2, U3.6 (CSYNC)
/VDP/GOUT: C63.2, J5.7, J17.2
/VDP/GREEN: C52.1, C83.1, RR9.4, U3.22 (G)
/VDP/HSYNC: RR9.2, U3.5 (HSYNC)
/VDP/LUMA: C61.2, J4.3, J22.1
/VDP/PAL_CLK: JP6.3, U43.4
/VDP/RED: C51.1, C82.1, RR9.5, U3.23 (R)
/VDP/ROUT: C62.2, J5.6, J17.1
/VDP/SYNCIN: C85.1, JP4.2, U47.10 (SYNCIN)
/VDP/VA0: U3.49 (AD0), U8.14 (A0), U9.14 (A0), U10.14 (A0), U11.14 (A0)
/VDP/VA1: U3.50 (AD1), U8.13 (A1), U9.13 (A1), U10.13 (A1), U11.13 (A1)
/VDP/VA2: U3.51 (AD2), U8.12 (A2), U9.12 (A2), U10.12 (A2), U11.12 (A2)
/VDP/VA3: U3.52 (AD3), U8.11 (A3), U9.11 (A3), U10.11 (A3), U11.11 (A3)
/VDP/VA4: U3.53 (AD4), U8.8 (A4), U9.8 (A4), U10.8 (A4), U11.8 (A4)
/VDP/VA5: U3.54 (AD5), U8.7 (A5), U9.7 (A5), U10.7 (A5), U11.7 (A5)
/VDP/VA6: U3.55 (AD6), U8.6 (A6), U9.6 (A6), U10.6 (A6), U11.6 (A6)
/VDP/VA7: U3.56 (AD7), U8.10 (A7), U9.10 (A7), U10.10 (A7), U11.10 (A7)
/VDP/VD0: U3.41 (RD0), U8.2 (D1), U10.2 (D1)
/VDP/VD1: U3.42 (RD1), U8.3 (D2), U10.3 (D2)
/VDP/VD2: U3.43 (RD2), U8.15 (D3), U10.15 (D3)
/VDP/VD3: U3.44 (RD3), U8.17 (D4), U10.17 (D4)
/VDP/VD4: U3.45 (RD4), U9.2 (D1), U11.2 (D1)
/VDP/VD5: U3.46 (RD5), U9.3 (D2), U11.3 (D2)
/VDP/VD6: U3.47 (RD6), U9.15 (D3), U11.15 (D3)
/VDP/VD7: U3.48 (RD7), U9.17 (D4), U11.17 (D4)
/VDP/VIDEO: JP3.2, U3.21 (VIDEO)
/VDP/YS: J5.5, R35.2, R36.1
/VDP/~CAS0: R38.1, U8.16 (~CAS), U9.16 (~CAS)
/VDP/~CAS1: R39.1, U10.16 (~CAS), U11.16 (~CAS)
/VDP/~DHCLK: J14.2, RR3.2, U3.2 (~DHCLK)
/VDP/~DLCLK: J14.3, RR3.3, U3.3 (~DLCKL)
/VDP/~RAS: R40.1, U8.5 (~RAS), U9.5 (~RAS), U10.5 (~RAS), U11.5 (~RAS)
/VDP/~VDP_RD: U3.31 (~CSR), U39.3
/VDP/~VDP_WR: U3.30 (~CSW), U39.11
/VDP/~VWR: R37.1, U8.4 (~WE), U9.4 (~WE), U10.4 (~WE), U11.4 (~WE)
/~RD: U39.1; also elsewhere on the board
/~RESET: U3.9 (~RESET); also elsewhere on the board
/~VDP_CS: U39.2, U39.13; also elsewhere on the board
/~VDP_INT: RR2.7, U3.25 (~INT); also elsewhere on the board
/~VDP_WAIT: RR2.8, U3.26 (~LPS); also elsewhere on the board
/~WR: U39.12; also elsewhere on the board
GND: C54.2, C55.2, C56.1, C77.2, C82.2, C83.2, C84.2, C85.2, C89.1, C90.1, C92.1, C93.1, C94.2, J2.2 (Ext), J4.1, J4.2, J5.1, J14.13, J17.4, J22.2, JP5.3, L1.2, R7.2, R9.2, R14.1, R28.1, R35.1, RR9.1 (COM), U3.1 (GND), U3.20 (GND), U8.1 (~OE), U8.18 (GND), U9.1 (~OE), U9.18 (GND), U10.1 (~OE), U10.18 (GND), U11.1 (~OE), U11.18 (GND), U39.7 (GND), U43.7 (GND), U43.9, U43.11, U43.13, U47.1 (GND), U47.24 (GND); also elsewhere on the board
unnamed: C51.2, U47.2 (RIN)
unnamed: C52.2, U47.3 (GIN)
unnamed: C53.2, U47.4 (BIN)
unnamed: C54.1, U47.9 (YCLPC)
unnamed: C55.1, R7.1, U47.13 (IREF)
unnamed: C56.2, U3.33 (VBB)
unnamed: C59.1, R43.1
unnamed: C60.1, R44.1
unnamed: C61.1, R45.1
unnamed: C62.1, R46.1
unnamed: C63.1, R47.1
unnamed: C64.1, R48.1
unnamed: C77.1, U47.14 (VREF)
unnamed: C89.2, R2.2, U3.63 (XTAL1), Y1.2
unnamed: C90.2, R30.1, Y3.2
unnamed: C91.1, U47.17 (YTRAP)
unnamed: C91.2, L1.1
unnamed: C92.2, R2.1, U3.64 (XTAL2), Y1.1
unnamed: C93.2, R1.2, U43.1, Y3.1
unnamed: C94.1, R25.1, U47.6 (SCIN)
unnamed: JP3.1, RR9.3
unnamed: JP4.1, U43.6
unnamed: JP4.3, Q2.2 (B), R27.1
unnamed: JP5.2, U47.7 (NTSC/~PAL)
unnamed: JP6.1, U39.6
unnamed: JP6.2, R25.2
unnamed: Q2.3 (C), R28.2, U43.5
unnamed: R1.1, R30.2, U43.2, U43.3
unnamed: R9.1, U47.18 (FO)
unnamed: R37.2, U3.57 (R/~W)
unnamed: R38.2, U3.61 (~CAS0)
unnamed: R39.2, U3.60 (~CAS1)
unnamed: R40.2, U3.62 (~RAS)
unnamed: R43.2, U47.20 (CVOUT)
unnamed: R44.2, U47.15 (COUT)
unnamed: R45.2, U47.16 (YOUT)
unnamed: R46.2, U47.23 (ROUT)
unnamed: R47.2, U47.22 (GOUT)
unnamed: R48.2, U47.21 (BOUT)
unnamed: RR2.9, U3.27 (~LPD)
unnamed: RR3.4, U3.4 (~VDS)
unnamed: RR3.5, U3.59 (~CASX)
unnamed: RR3.6, U3.7 (BLEO)
unnamed: RR3.7, U3.10 (~YS)
VCC: J14.1, Q2.1 (E), R33.2, R36.2, RR2.1 (COM), RR3.1 (COM), U8.9 (VCC), U9.9 (VCC), U10.9 (VCC), U11.9 (VCC), U39.14 (VCC), U43.14 (VCC); also elsewhere on the board
VCCRGB: JP5.1, U47.12 (VCC), U47.19 (VCC); also elsewhere on the board
VCCVDP: JP3.3, U3.58 (VCC); also elsewhere on the board

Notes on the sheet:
JP3, JP4: 1-2: V9938; 2-3: V9958 (Use a wire link) JP4, JP5: 1-2: NTSC; 2-3: PAL (Use a wire link)
PAL: R9 - 16k, C91 - 18pF R9 - Tolerance 1%
PCB Layout Notes: Keep trace length between CXA1645 and 75 ohm resistors to minimum CXA1645 bypass capacitors: VCC1(12), VREF(14) -> GND1(1), VCC2(19) -> GND2(24)
Optional: PAL Clock Generator
Optional: RGB Output
Install Q2 only for V9938

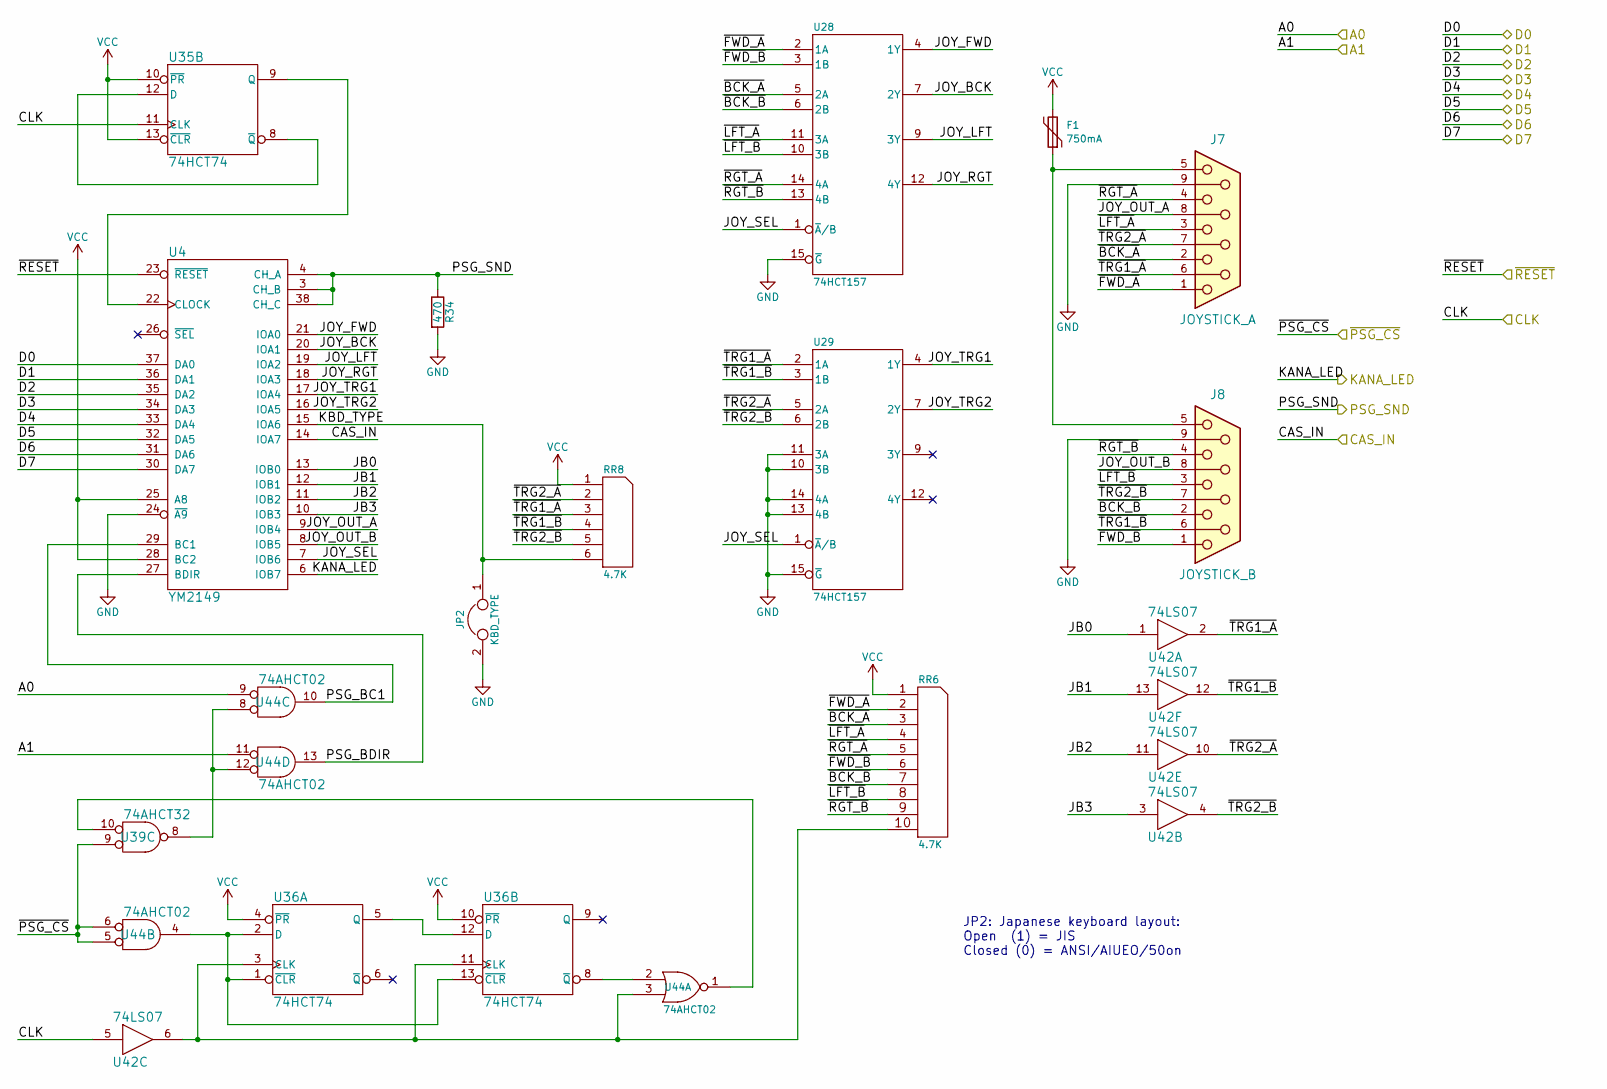
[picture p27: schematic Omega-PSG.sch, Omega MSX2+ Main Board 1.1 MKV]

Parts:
F1: 750mA; Fuse_1206_3216Metric_Pad1.42x1.75mm_HandSolder
J7: JOYSTICK_A; DSUB-9_Male_Horizontal_P2.77x2.84mm_EdgePinOffset4.94mm_Hou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
J8: JOYSTICK_B; DSUB-9_Male_Horizontal_P2.77x2.84mm_EdgePinOffset4.94mm_Hou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
JP2: KBD_TYPE; PinHeader_1x02_P2.54mm_Vertical
R34: 470; R_1206_3216Metric_Pad1.42x1.75mm_HandSolder
RR6: 4.7K; R_Array_SIP10
RR8: 4.7K; R_Array_SIP6
U4: YM2149; DIP-40_W15.24mm_Socket
U28, U29: 74HCT157; DIP-16_W7.62mm_Socket
U35, U36: 74HCT74; DIP-14_W7.62mm_Socket
U39: 74AHCT32; IC_DIP14_300
U42: 74LS07; DIP-14_W7.62mm_Socket
U44: 74AHCT02; DIP-14_W7.62mm_Socket

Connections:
/A0: U44.9; also elsewhere on the board
/A1: U44.11; also elsewhere on the board
/CAS_IN: U4.14 (IOA7); also elsewhere on the board
/CLK: U35.11 (CLK), U42.5; also elsewhere on the board
/D0: U4.37 (DA0); also elsewhere on the board
/D1: U4.36 (DA1); also elsewhere on the board
/D2: U4.35 (DA2); also elsewhere on the board
/D3: U4.34 (DA3); also elsewhere on the board
/D4: U4.33 (DA4); also elsewhere on the board
/D5: U4.32 (DA5); also elsewhere on the board
/D6: U4.31 (DA6); also elsewhere on the board
/D7: U4.30 (DA7); also elsewhere on the board
/KANA_LED: U4.6 (IOB7); also elsewhere on the board
/PSG/JB0: U4.13 (IOB0), U42.1
/PSG/JB1: U4.12 (IOB1), U42.13
/PSG/JB2: U4.11 (IOB2), U42.11
/PSG/JB3: U4.10 (IOB3), U42.3
/PSG/JOY_BCK: U4.20 (IOA1), U28.7 (2Y)
/PSG/JOY_FWD: U4.21 (IOA0), U28.4 (1Y)
/PSG/JOY_LFT: U4.19 (IOA2), U28.9 (3Y)
/PSG/JOY_OUT_A: J7.8, U4.9 (IOB4)
/PSG/JOY_OUT_B: J8.8, U4.8 (IOB5)
/PSG/JOY_RGT: U4.18 (IOA3), U28.12 (4Y)
/PSG/JOY_SEL: U4.7 (IOB6), U28.1 (~A~/B), U29.1 (~A~/B)
/PSG/JOY_TRG1: U4.17 (IOA4), U29.4 (1Y)
/PSG/JOY_TRG2: U4.16 (IOA5), U29.7 (2Y)
/PSG/KBD_TYPE: JP2.1, RR8.6, U4.15 (IOA6)
/PSG/PSG_BC1: U4.29 (BC1), U44.10
/PSG/PSG_BDIR: U4.27 (BDIR), U44.13
/PSG/~BCK_A: J7.2, RR6.3, U28.5 (2A)
/PSG/~BCK_B: J8.2, RR6.7, U28.6 (2B)
/PSG/~FWD_A: J7.1, RR6.2, U28.2 (1A)
/PSG/~FWD_B: J8.1, RR6.6, U28.3 (1B)
/PSG/~LFT_A: J7.3, RR6.4, U28.11 (3A)
/PSG/~LFT_B: J8.3, RR6.8, U28.10 (3B)
/PSG/~RGT_A: J7.4, RR6.5, U28.14 (4A)
/PSG/~RGT_B: J8.4, RR6.9, U28.13 (4B)
/PSG/~TRG1_A: J7.6, RR8.3, U29.2 (1A), U42.2
/PSG/~TRG1_B: J8.6, RR8.4, U29.3 (1B), U42.12
/PSG/~TRG2_A: J7.7, RR8.2, U29.5 (2A), U42.10
/PSG/~TRG2_B: J8.7, RR8.5, U29.6 (2B), U42.4
/PSG_SND: R34.1, U4.3 (CH_B), U4.4 (CH_A), U4.38 (CH_C); also elsewhere on the board
/~PSG_CS: U39.9, U44.5, U44.6; also elsewhere on the board
/~RESET: U4.23 (~RESET); also elsewhere on the board
GND: J7.9, J8.9, JP2.2, R34.2, U4.1 (GND), U4.24 (~A9), U28.8 (GND), U28.15 (~G), U29.8 (GND), U29.10 (3B), U29.11 (3A), U29.13 (4B), U29.14 (4A), U29.15 (~G), U35.7 (GND), U36.7 (GND), U39.7 (GND), U42.7 (GND), U44.7 (GND); also elsewhere on the board
unnamed: F1.1, J7.5, J8.5
unnamed: RR6.10, U36.3 (CLK), U36.11 (CLK), U42.6, U44.3
unnamed: U4.22 (CLOCK), U35.9 (Q)
unnamed: U35.8 (~Q), U35.12 (D)
unnamed: U36.1 (~CLR), U36.2 (D), U36.13 (~CLR), U44.4
unnamed: U36.8 (~Q), U44.2
unnamed: U36.5 (Q), U36.12 (D)
unnamed: U39.8, U44.8, U44.12
unnamed: U39.10, U44.1
VCC: F1.2, RR6.1 (COM), RR8.1 (COM), U4.25 (A8), U4.28 (BC2), U4.40 (VCC), U28.16 (VCC), U29.16 (VCC), U35.10 (~PR), U35.13 (~CLR), U35.14 (VCC), U36.4 (~PR), U36.10 (~PR), U36.14 (VCC), U39.14 (VCC), U42.14 (VCC), U44.14 (VCC); also elsewhere on the board

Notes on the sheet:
JP2: Japanese keyboard layout: Open (1) = JIS Closed (0) = ANSI/AIUEO/50on

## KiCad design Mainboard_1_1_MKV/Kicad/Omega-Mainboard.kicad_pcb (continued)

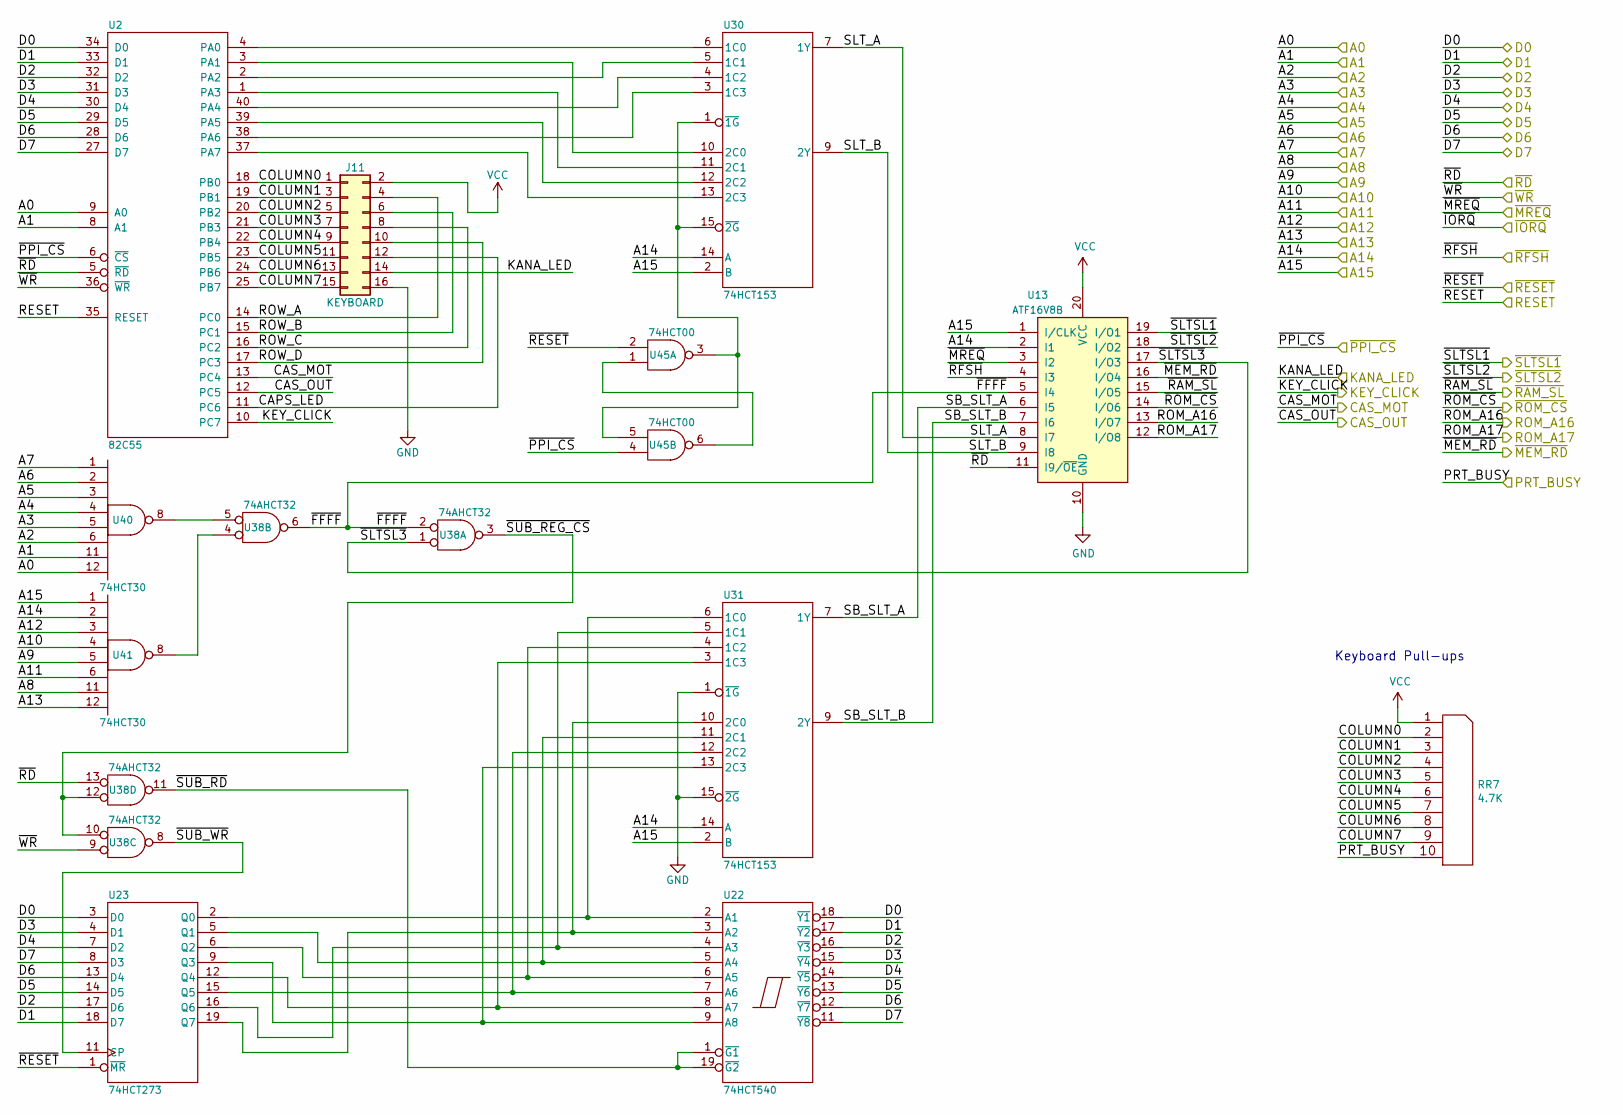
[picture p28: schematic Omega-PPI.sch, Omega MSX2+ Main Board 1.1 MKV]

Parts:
J11: KEYBOARD; IDC-Header_2x08_P2.54mm_Vertical
RR7: 4.7K; R_Array_SIP10
U2: 82C55; DIP-40_W15.24mm_Socket
U13: ATF16V8B; DIP-20_W7.62mm_Socket
U22: 74HCT540; DIP-20_W7.62mm_Socket
U23: 74HCT273; DIP-20_W7.62mm_Socket
U30, U31: 74HCT153; DIP-16_W7.62mm_Socket
U38: 74AHCT32; DIP-14_W7.62mm_Socket
U40, U41: 74HCT30; DIP-14_W7.62mm_Socket
U45: 74HCT00; DIP-14_W7.62mm_Socket

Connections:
/A0: U2.9 (A0), U40.12; also elsewhere on the board
/A1: U2.8 (A1), U40.11; also elsewhere on the board
/A2: U40.6; also elsewhere on the board
/A3: U40.5; also elsewhere on the board
/A4: U40.4; also elsewhere on the board
/A5: U40.3; also elsewhere on the board
/A6: U40.2; also elsewhere on the board
/A7: U40.1; also elsewhere on the board
/A8: U41.11; also elsewhere on the board
/A9: U41.5; also elsewhere on the board
/A10: U41.4; also elsewhere on the board
/A11: U41.6; also elsewhere on the board
/A12: U41.3; also elsewhere on the board
/A13: U41.12; also elsewhere on the board
/A14: U13.2 (I1), U30.14 (A), U31.14 (A), U41.2; also elsewhere on the board
/A15: U13.1 (I/CLK), U30.2 (B), U31.2 (B), U41.1; also elsewhere on the board
/CAS_MOT: U2.13 (PC4); also elsewhere on the board
/CAS_OUT: U2.12 (PC5); also elsewhere on the board
/D0: U2.34 (D0), U22.18 (~Y1), U23.3 (D0); also elsewhere on the board
/D1: U2.33 (D1), U22.17 (~Y2), U23.18 (D7); also elsewhere on the board
/D2: U2.32 (D2), U22.16 (~Y3), U23.17 (D6); also elsewhere on the board
/D3: U2.31 (D3), U22.15 (~Y4), U23.4 (D1); also elsewhere on the board
/D4: U2.30 (D4), U22.14 (~Y5), U23.7 (D2); also elsewhere on the board
/D5: U2.29 (D5), U22.13 (~Y6), U23.14 (D5); also elsewhere on the board
/D6: U2.28 (D6), U22.12 (~Y7), U23.13 (D4); also elsewhere on the board
/D7: U2.27 (D7), U22.11 (~Y8), U23.8 (D3); also elsewhere on the board
/KANA_LED: J11.14; also elsewhere on the board
/KEY_CLICK: U2.10 (PC7); also elsewhere on the board
/PPI/CAPS_LED: J11.12, U2.11 (PC6)
/PPI/COLUMN0: J11.1, RR7.2, U2.18 (PB0)
/PPI/COLUMN1: J11.3, RR7.3, U2.19 (PB1)
/PPI/COLUMN2: J11.5, RR7.4, U2.20 (PB2)
/PPI/COLUMN3: J11.7, RR7.5, U2.21 (PB3)
/PPI/COLUMN4: J11.9, RR7.6, U2.22 (PB4)
/PPI/COLUMN5: J11.11, RR7.7, U2.23 (PB5)
/PPI/COLUMN6: J11.13, RR7.8, U2.24 (PB6)
/PPI/COLUMN7: J11.15, RR7.9, U2.25 (PB7)
/PPI/ROW_A: J11.4, U2.14 (PC0)
/PPI/ROW_B: J11.6, U2.15 (PC1)
/PPI/ROW_C: J11.8, U2.16 (PC2)
/PPI/ROW_D: J11.10, U2.17 (PC3)
/PPI/SB_SLT_A: U13.6 (I5), U31.7 (1Y)
/PPI/SB_SLT_B: U13.7 (I6), U31.9 (2Y)
/PPI/SLT_A: U13.8 (I7), U30.7 (1Y)
/PPI/SLT_B: U13.9 (I8), U30.9 (2Y)
/PPI/~FFFF: U13.5 (I4), U38.2, U38.6
/PPI/~SLTSL3: U13.17 (I/O3), U38.1
/PPI/~SUB_RD: U22.1 (~G1), U22.19 (~G2), U38.11
/PPI/~SUB_REG_CS: U38.3, U38.10, U38.12
/PPI/~SUB_WR: U23.11 (CP), U38.8
/PRT_BUSY: RR7.10; also elsewhere on the board
/RESET: U2.35 (RESET); also elsewhere on the board
/ROM_A16: U13.13 (I/O7); also elsewhere on the board
/ROM_A17: U13.12 (I/O8); also elsewhere on the board
/~MEM_RD: U13.16 (I/O4); also elsewhere on the board
/~MREQ: U13.3 (I2); also elsewhere on the board
/~PPI_CS: U2.6 (~CS), U45.4; also elsewhere on the board
/~RAM_SL: U13.15 (I/O5); also elsewhere on the board
/~RD: U2.5 (~RD), U13.11 (I9/~OE), U38.13; also elsewhere on the board
/~RESET: U23.1 (~MR), U45.2; also elsewhere on the board
/~RFSH: U13.4 (I3); also elsewhere on the board
/~ROM_CS: U13.14 (I/O6); also elsewhere on the board
/~SLTSL1: U13.19 (I/O1); also elsewhere on the board
/~SLTSL2: U13.18 (I/O2); also elsewhere on the board
/~WR: U2.36 (~WR), U38.9; also elsewhere on the board
GND: J11.16, U2.7 (GND), U13.10 (GND), U22.10 (GND), U23.10 (GND), U30.8 (GND), U31.1 (~1G), U31.8 (GND), U31.15 (~2G), U38.7 (GND), U40.7 (GND), U41.7 (GND), U45.7 (GND); also elsewhere on the board
unnamed: U2.1 (PA3), U30.11 (2C1)
unnamed: U2.2 (PA2), U30.5 (1C1)
unnamed: U2.3 (PA1), U30.10 (2C0)
unnamed: U2.4 (PA0), U30.6 (1C0)
unnamed: U2.37 (PA7), U30.13 (2C3)
unnamed: U2.38 (PA6), U30.3 (1C3)
unnamed: U2.39 (PA5), U30.12 (2C2)
unnamed: U2.40 (PA4), U30.4 (1C2)
unnamed: U22.2 (A1), U23.2 (Q0), U31.6 (1C0)
unnamed: U22.3 (A2), U23.19 (Q7), U31.10 (2C0)
unnamed: U22.4 (A3), U23.16 (Q6), U31.5 (1C1)
unnamed: U22.5 (A4), U23.5 (Q1), U31.11 (2C1)
unnamed: U22.6 (A5), U23.6 (Q2), U31.4 (1C2)
unnamed: U22.7 (A6), U23.15 (Q5), U31.12 (2C2)
unnamed: U22.8 (A7), U23.12 (Q4), U31.3 (1C3)
unnamed: U22.9 (A8), U23.9 (Q3), U31.13 (2C3)
unnamed: U30.1 (~1G), U30.15 (~2G), U45.3, U45.5
unnamed: U38.4, U41.8
unnamed: U38.5, U40.8
unnamed: U45.1, U45.6
VCC: J11.2, RR7.1 (COM), U2.26 (VCC), U13.20 (VCC), U22.20 (VCC), U23.20 (VCC), U30.16 (VCC), U31.16 (VCC), U38.14 (VCC), U40.14 (VCC), U41.14 (VCC), U45.14 (VCC); also elsewhere on the board

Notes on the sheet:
Keyboard Pull-ups

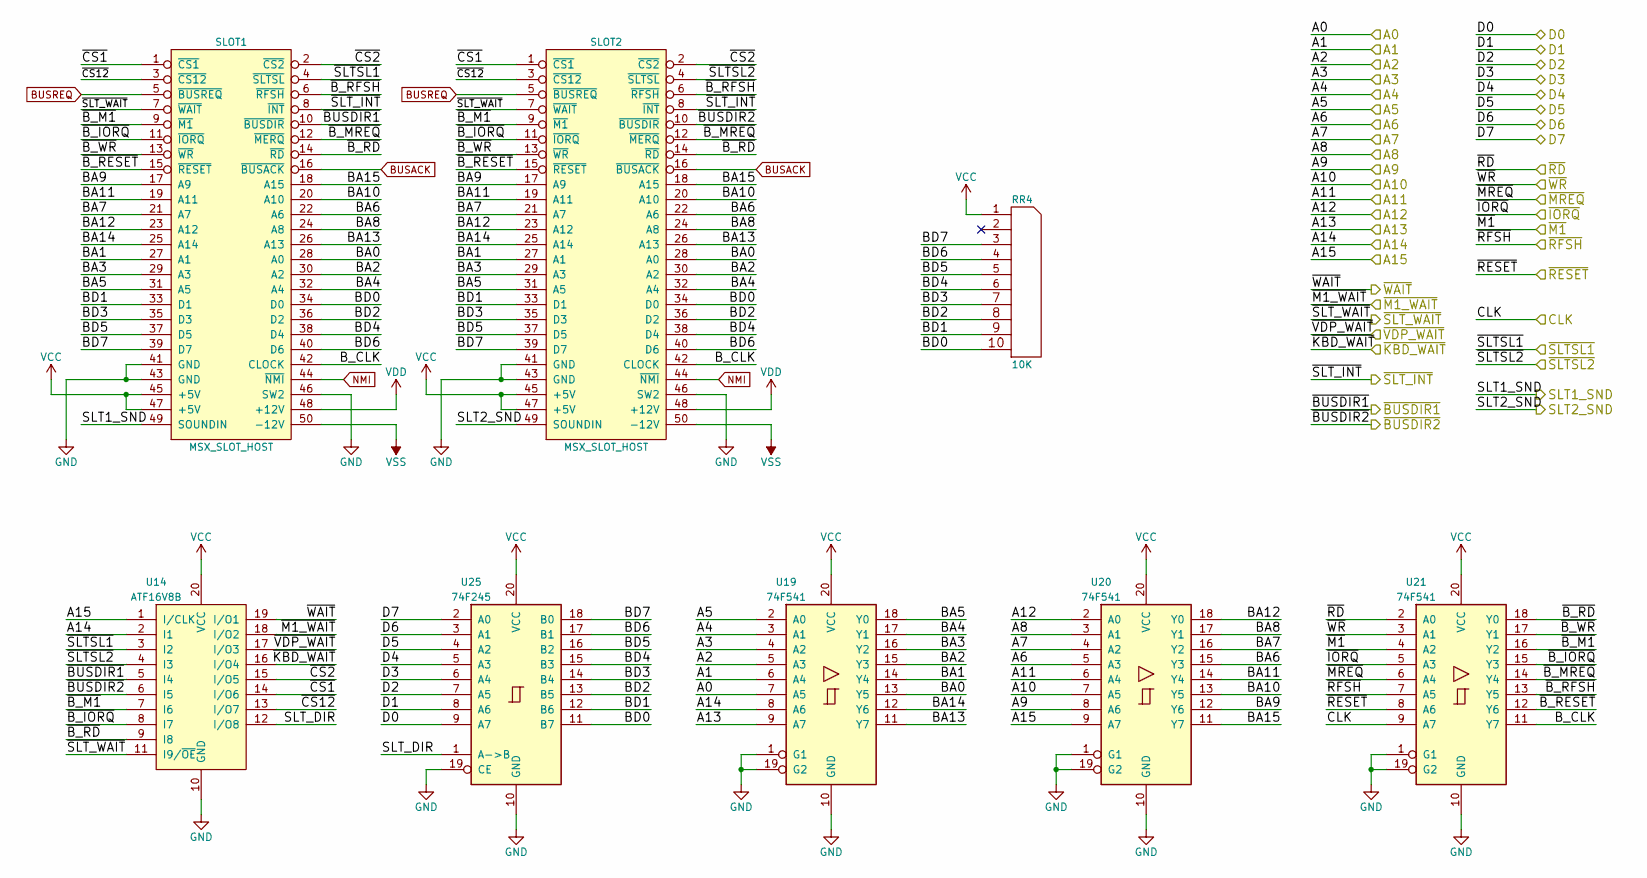
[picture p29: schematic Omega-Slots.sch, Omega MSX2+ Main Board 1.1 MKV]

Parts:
RR4: 10K; R_Array_SIP10
SLOT1, SLOT2: MSX_SLOT_HOST; Conn_Edge_50P
U14: ATF16V8B; DIP-20_W7.62mm_Socket
U19, U20, U21: 74F541; DIP-20_W7.62mm_Socket
U25: 74F245; DIP-20_W7.62mm_Socket

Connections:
/A0: U19.7 (A5); also elsewhere on the board
/A1: U19.6 (A4); also elsewhere on the board
/A2: U19.5 (A3); also elsewhere on the board
/A3: U19.4 (A2); also elsewhere on the board
/A4: U19.3 (A1); also elsewhere on the board
/A5: U19.2 (A0); also elsewhere on the board
/A6: U20.5 (A3); also elsewhere on the board
/A7: U20.4 (A2); also elsewhere on the board
/A8: U20.3 (A1); also elsewhere on the board
/A9: U20.8 (A6); also elsewhere on the board
/A10: U20.7 (A5); also elsewhere on the board
/A11: U20.6 (A4); also elsewhere on the board
/A12: U20.2 (A0); also elsewhere on the board
/A13: U19.9 (A7); also elsewhere on the board
/A14: U14.2 (I1), U19.8 (A6); also elsewhere on the board
/A15: U14.1 (I/CLK), U20.9 (A7); also elsewhere on the board
/CLK: U21.9 (A7); also elsewhere on the board
/D0: U25.9 (A7); also elsewhere on the board
/D1: U25.8 (A6); also elsewhere on the board
/D2: U25.7 (A5); also elsewhere on the board
/D3: U25.6 (A4); also elsewhere on the board
/D4: U25.5 (A3); also elsewhere on the board
/D5: U25.4 (A2); also elsewhere on the board
/D6: U25.3 (A1); also elsewhere on the board
/D7: U25.2 (A0); also elsewhere on the board
/SLT1_SND: SLOT1.49 (SOUNDIN); also elsewhere on the board
/SLT2_SND: SLOT2.49 (SOUNDIN); also elsewhere on the board
/Slots/BA0: SLOT1.28 (A0), SLOT2.28 (A0), U19.13 (Y5)
/Slots/BA1: SLOT1.27 (A1), SLOT2.27 (A1), U19.14 (Y4)
/Slots/BA2: SLOT1.30 (A2), SLOT2.30 (A2), U19.15 (Y3)
/Slots/BA3: SLOT1.29 (A3), SLOT2.29 (A3), U19.16 (Y2)
/Slots/BA4: SLOT1.32 (A4), SLOT2.32 (A4), U19.17 (Y1)
/Slots/BA5: SLOT1.31 (A5), SLOT2.31 (A5), U19.18 (Y0)
/Slots/BA6: SLOT1.22 (A6), SLOT2.22 (A6), U20.15 (Y3)
/Slots/BA7: SLOT1.21 (A7), SLOT2.21 (A7), U20.16 (Y2)
/Slots/BA8: SLOT1.24 (A8), SLOT2.24 (A8), U20.17 (Y1)
/Slots/BA9: SLOT1.17 (A9), SLOT2.17 (A9), U20.12 (Y6)
/Slots/BA10: SLOT1.20 (A10), SLOT2.20 (A10), U20.13 (Y5)
/Slots/BA11: SLOT1.19 (A11), SLOT2.19 (A11), U20.14 (Y4)
/Slots/BA12: SLOT1.23 (A12), SLOT2.23 (A12), U20.18 (Y0)
/Slots/BA13: SLOT1.26 (A13), SLOT2.26 (A13), U19.11 (Y7)
/Slots/BA14: SLOT1.25 (A14), SLOT2.25 (A14), U19.12 (Y6)
/Slots/BA15: SLOT1.18 (A15), SLOT2.18 (A15), U20.11 (Y7)
/Slots/BD0: RR4.10, SLOT1.34 (D0), SLOT2.34 (D0), U25.11 (B7)
/Slots/BD1: RR4.9, SLOT1.33 (D1), SLOT2.33 (D1), U25.12 (B6)
/Slots/BD2: RR4.8, SLOT1.36 (D2~), SLOT2.36 (D2~), U25.13 (B5)
/Slots/BD3: RR4.7, SLOT1.35 (D3), SLOT2.35 (D3), U25.14 (B4)
/Slots/BD4: RR4.6, SLOT1.38 (D4), SLOT2.38 (D4), U25.15 (B3)
/Slots/BD5: RR4.5, SLOT1.37 (D5), SLOT2.37 (D5), U25.16 (B2)
/Slots/BD6: RR4.4, SLOT1.40 (D6), SLOT2.40 (D6), U25.17 (B1)
/Slots/BD7: RR4.3, SLOT1.39 (D7), SLOT2.39 (D7), U25.18 (B0)
/Slots/B_CLK: SLOT1.42 (CLOCK), SLOT2.42 (CLOCK), U21.11 (Y7)
/Slots/SLT_DIR: U14.12 (I/O8), U25.1 (A->B)
/Slots/~B_IORQ: SLOT1.11 (~IORQ), SLOT2.11 (~IORQ), U14.8 (I7), U21.15 (Y3)
/Slots/~B_M1: SLOT1.9 (~M1), SLOT2.9 (~M1), U14.7 (I6), U21.16 (Y2)
/Slots/~B_MREQ: SLOT1.12 (~MERQ), SLOT2.12 (~MERQ), U21.14 (Y4)
/Slots/~B_RD: SLOT1.14 (~RD), SLOT2.14 (~RD), U14.9 (I8), U21.18 (Y0)
/Slots/~B_RESET: SLOT1.15 (~RESET), SLOT2.15 (~RESET), U21.12 (Y6)
/Slots/~B_RFSH: SLOT1.6 (~RFSH), SLOT2.6 (~RFSH), U21.13 (Y5)
/Slots/~B_WR: SLOT1.13 (~WR), SLOT2.13 (~WR), U21.17 (Y1)
/Slots/~CS1: SLOT1.1 (~CS1), SLOT2.1 (~CS1), U14.14 (I/O6)
/Slots/~CS2: SLOT1.2 (~CS2), SLOT2.2 (~CS2), U14.15 (I/O5)
/Slots/~CS12: SLOT1.3 (~CS12), SLOT2.3 (~CS12), U14.13 (I/O7)
/~BUSDIR1: SLOT1.10 (~BUSDIR), U14.5 (I4); also elsewhere on the board
/~BUSDIR2: SLOT2.10 (~BUSDIR), U14.6 (I5); also elsewhere on the board
/~IORQ: U21.5 (A3); also elsewhere on the board
/~KBD_WAIT: U14.16 (I/O4); also elsewhere on the board
/~M1: U21.4 (A2); also elsewhere on the board
/~M1_WAIT: U14.18 (I/O2); also elsewhere on the board
/~MREQ: U21.6 (A4); also elsewhere on the board
/~RD: U21.2 (A0); also elsewhere on the board
/~RESET: U21.8 (A6); also elsewhere on the board
/~RFSH: U21.7 (A5); also elsewhere on the board
/~SLTSL1: SLOT1.4 (~SLTSL), U14.3 (I2); also elsewhere on the board
/~SLTSL2: SLOT2.4 (~SLTSL), U14.4 (I3); also elsewhere on the board
/~SLT_INT: SLOT1.8 (~INT), SLOT2.8 (~INT); also elsewhere on the board
/~SLT_WAIT: SLOT1.7 (~WAIT), SLOT2.7 (~WAIT), U14.11 (I9/~OE); also elsewhere on the board
/~VDP_WAIT: U14.17 (I/O3); also elsewhere on the board
/~WAIT: U14.19 (I/O1); also elsewhere on the board
/~WR: U21.3 (A1); also elsewhere on the board
BUSACK: SLOT1.16 (~BUSACK), SLOT2.16 (~BUSACK); also elsewhere on the board
BUSREQ: SLOT1.5 (~BUSREQ), SLOT2.5 (~BUSREQ); also elsewhere on the board
GND: SLOT1.41 (GND), SLOT1.43 (GND), SLOT1.46 (SW2), SLOT2.41 (GND), SLOT2.43 (GND), SLOT2.46 (SW2), U14.10 (GND), U19.1 (G1), U19.10 (GND), U19.19 (G2), U20.1 (G1), U20.10 (GND), U20.19 (G2), U21.1 (G1), U21.10 (GND), U21.19 (G2), U25.10 (GND), U25.19 (CE); also elsewhere on the board
NMI: SLOT1.44 (~NMI), SLOT2.44 (~NMI); also elsewhere on the board
VCC: RR4.1 (COM), SLOT1.45 (+5V), SLOT1.47 (+5V), SLOT2.45 (+5V), SLOT2.47 (+5V), U14.20 (VCC), U19.20 (VCC), U20.20 (VCC), U21.20 (VCC), U25.20 (VCC); also elsewhere on the board
VDD: SLOT1.48 (+12V), SLOT2.48 (+12V); also elsewhere on the board
VSS: SLOT1.50 (-12V), SLOT2.50 (-12V); also elsewhere on the board

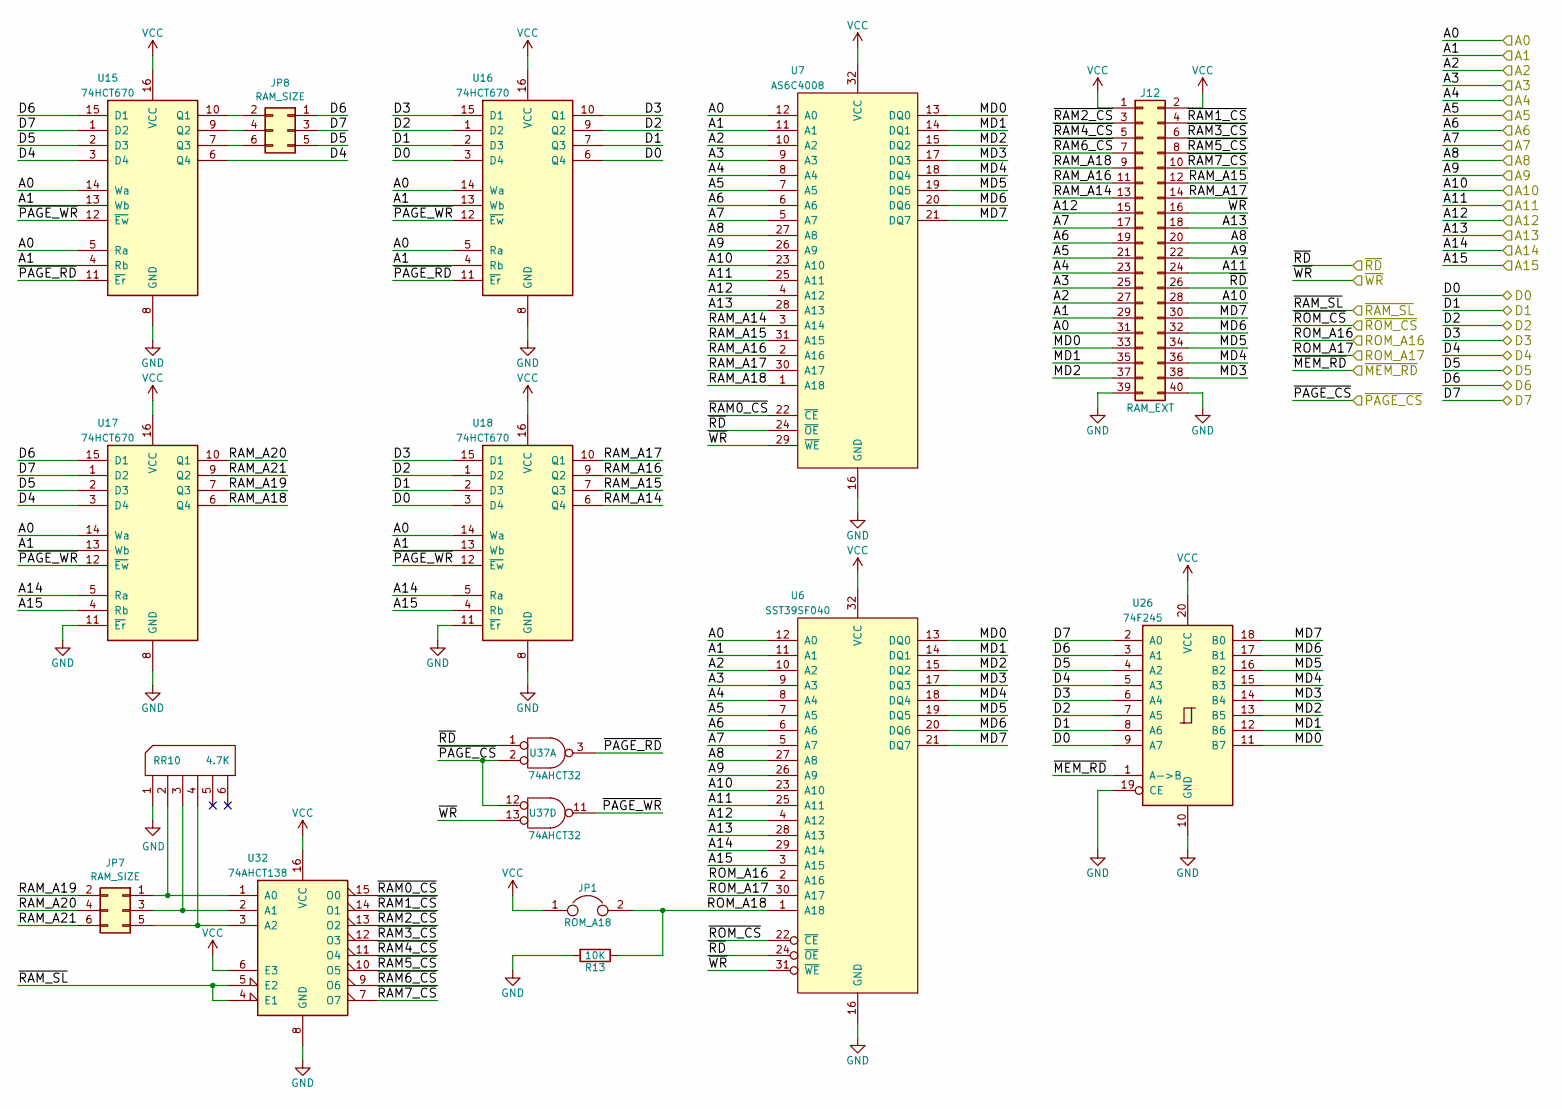
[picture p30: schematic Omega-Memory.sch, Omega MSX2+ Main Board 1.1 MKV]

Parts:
J12: RAM_EXT; PinHeader_2x20_P2.54mm_Vertical
JP1: ROM_A18; Molex_KK-254_AE-6410-02A_1x02_P2.54mm_Vertical
JP7, JP8: RAM_SIZE; PinHeader_2x03_P2.54mm_Vertical
R13: 10K; R_1206_3216Metric_Pad1.42x1.75mm_HandSolder
RR10: 4.7K; R_Array_SIP6
U6: SST39SF040; DIP-32_W15.24mm_Socket
U7: AS6C4008; DIP-32_W15.24mm_Socket
U15, U16, U17, U18: 74HCT670; DIP-16_W7.62mm_Socket
U26: 74F245; DIP-20_W7.62mm_Socket
U32: 74AHCT138; DIP-16_W7.62mm_Socket
U37: 74AHCT32; DIP-14_W7.62mm_Socket

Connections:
/A0: J12.31, U6.12 (A0), U7.12 (A0), U15.5 (Ra), U15.14 (Wa), U16.5 (Ra), U16.14 (Wa), U17.14 (Wa), U18.14 (Wa); also elsewhere on the board
/A1: J12.29, U6.11 (A1), U7.11 (A1), U15.4 (Rb), U15.13 (Wb), U16.4 (Rb), U16.13 (Wb), U17.13 (Wb), U18.13 (Wb); also elsewhere on the board
/A2: J12.27, U6.10 (A2), U7.10 (A2); also elsewhere on the board
/A3: J12.25, U6.9 (A3), U7.9 (A3); also elsewhere on the board
/A4: J12.23, U6.8 (A4), U7.8 (A4); also elsewhere on the board
/A5: J12.21, U6.7 (A5), U7.7 (A5); also elsewhere on the board
/A6: J12.19, U6.6 (A6), U7.6 (A6); also elsewhere on the board
/A7: J12.17, U6.5 (A7), U7.5 (A7); also elsewhere on the board
/A8: J12.20, U6.27 (A8), U7.27 (A8); also elsewhere on the board
/A9: J12.22, U6.26 (A9), U7.26 (A9); also elsewhere on the board
/A10: J12.28, U6.23 (A10), U7.23 (A10); also elsewhere on the board
/A11: J12.24, U6.25 (A11), U7.25 (A11); also elsewhere on the board
/A12: J12.15, U6.4 (A12), U7.4 (A12); also elsewhere on the board
/A13: J12.18, U6.28 (A13), U7.28 (A13); also elsewhere on the board
/A14: U6.29 (A14), U17.5 (Ra), U18.5 (Ra); also elsewhere on the board
/A15: U6.3 (A15), U17.4 (Rb), U18.4 (Rb); also elsewhere on the board
/D0: U16.3 (D4), U16.6 (Q4), U18.3 (D4), U26.9 (A7); also elsewhere on the board
/D1: U16.2 (D3), U16.7 (Q3), U18.2 (D3), U26.8 (A6); also elsewhere on the board
/D2: U16.1 (D2), U16.9 (Q2), U18.1 (D2), U26.7 (A5); also elsewhere on the board
/D3: U16.10 (Q1), U16.15 (D1), U18.15 (D1), U26.6 (A4); also elsewhere on the board
/D4: U15.3 (D4), U15.6 (Q4), U17.3 (D4), U26.5 (A3); also elsewhere on the board
/D5: JP8.5, U15.2 (D3), U17.2 (D3), U26.4 (A2); also elsewhere on the board
/D6: JP8.1, U15.15 (D1), U17.15 (D1), U26.3 (A1); also elsewhere on the board
/D7: JP8.3, U15.1 (D2), U17.1 (D2), U26.2 (A0); also elsewhere on the board
/Memory/MD0: J12.33, U6.13 (DQ0), U7.13 (DQ0), U26.11 (B7)
/Memory/MD1: J12.35, U6.14 (DQ1), U7.14 (DQ1), U26.12 (B6)
/Memory/MD2: J12.37, U6.15 (DQ2), U7.15 (DQ2), U26.13 (B5)
/Memory/MD3: J12.38, U6.17 (DQ3), U7.17 (DQ3), U26.14 (B4)
/Memory/MD4: J12.36, U6.18 (DQ4), U7.18 (DQ4), U26.15 (B3)
/Memory/MD5: J12.34, U6.19 (DQ5), U7.19 (DQ5), U26.16 (B2)
/Memory/MD6: J12.32, U6.20 (DQ6), U7.20 (DQ6), U26.17 (B1)
/Memory/MD7: J12.30, U6.21 (DQ7), U7.21 (DQ7), U26.18 (B0)
/Memory/RAM_A14: J12.13, U7.3 (A14), U18.6 (Q4)
/Memory/RAM_A15: J12.12, U7.31 (A15), U18.7 (Q3)
/Memory/RAM_A16: J12.11, U7.2 (A16), U18.9 (Q2)
/Memory/RAM_A17: J12.14, U7.30 (A17), U18.10 (Q1)
/Memory/RAM_A18: J12.9, U7.1 (A18), U17.6 (Q4)
/Memory/RAM_A19: JP7.2, U17.7 (Q3)
/Memory/RAM_A20: JP7.4, U17.10 (Q1)
/Memory/RAM_A21: JP7.6, U17.9 (Q2)
/Memory/ROM_A18: JP1.2, R13.1, U6.1 (A18)
/Memory/~PAGE_RD: U15.11 (~Er), U16.11 (~Er), U37.3
/Memory/~PAGE_WR: U15.12 (~Ew), U16.12 (~Ew), U17.12 (~Ew), U18.12 (~Ew), U37.11
/Memory/~RAM0_CS: U7.22 (~CE), U32.15 (O0)
/Memory/~RAM1_CS: J12.4, U32.14 (O1)
/Memory/~RAM2_CS: J12.3, U32.13 (O2)
/Memory/~RAM3_CS: J12.6, U32.12 (O3)
/Memory/~RAM4_CS: J12.5, U32.11 (O4)
/Memory/~RAM5_CS: J12.8, U32.10 (O5)
/Memory/~RAM6_CS: J12.7, U32.9 (O6)
/Memory/~RAM7_CS: J12.10, U32.7 (O7)
/ROM_A16: U6.2 (A16); also elsewhere on the board
/ROM_A17: U6.30 (A17); also elsewhere on the board
/~MEM_RD: U26.1 (A->B); also elsewhere on the board
/~PAGE_CS: U37.2, U37.12; also elsewhere on the board
/~RAM_SL: U32.4 (E1), U32.5 (E2); also elsewhere on the board
/~RD: J12.26, U6.24 (~OE), U7.24 (~OE), U37.1; also elsewhere on the board
/~ROM_CS: U6.22 (~CE); also elsewhere on the board
/~WR: J12.16, U6.31 (~WE), U7.29 (~WE), U37.13; also elsewhere on the board
GND: J12.39, J12.40, R13.2, RR10.1 (COM), U6.16 (GND), U7.16 (GND), U15.8 (GND), U16.8 (GND), U17.8 (GND), U17.11 (~Er), U18.8 (GND), U18.11 (~Er), U26.10 (GND), U26.19 (CE), U32.8 (GND), U37.7 (GND); also elsewhere on the board
unnamed: JP7.1, RR10.2, U32.1 (A0)
unnamed: JP7.3, RR10.3, U32.2 (A1)
unnamed: JP7.5, RR10.4, U32.3 (A2)
unnamed: JP8.2, U15.10 (Q1)
unnamed: JP8.4, U15.9 (Q2)
unnamed: JP8.6, U15.7 (Q3)
VCC: J12.1, J12.2, JP1.1, U6.32 (VCC), U7.32 (VCC), U15.16 (VCC), U16.16 (VCC), U17.16 (VCC), U18.16 (VCC), U26.20 (VCC), U32.6 (E3), U32.16 (VCC), U37.14 (VCC); also elsewhere on the board

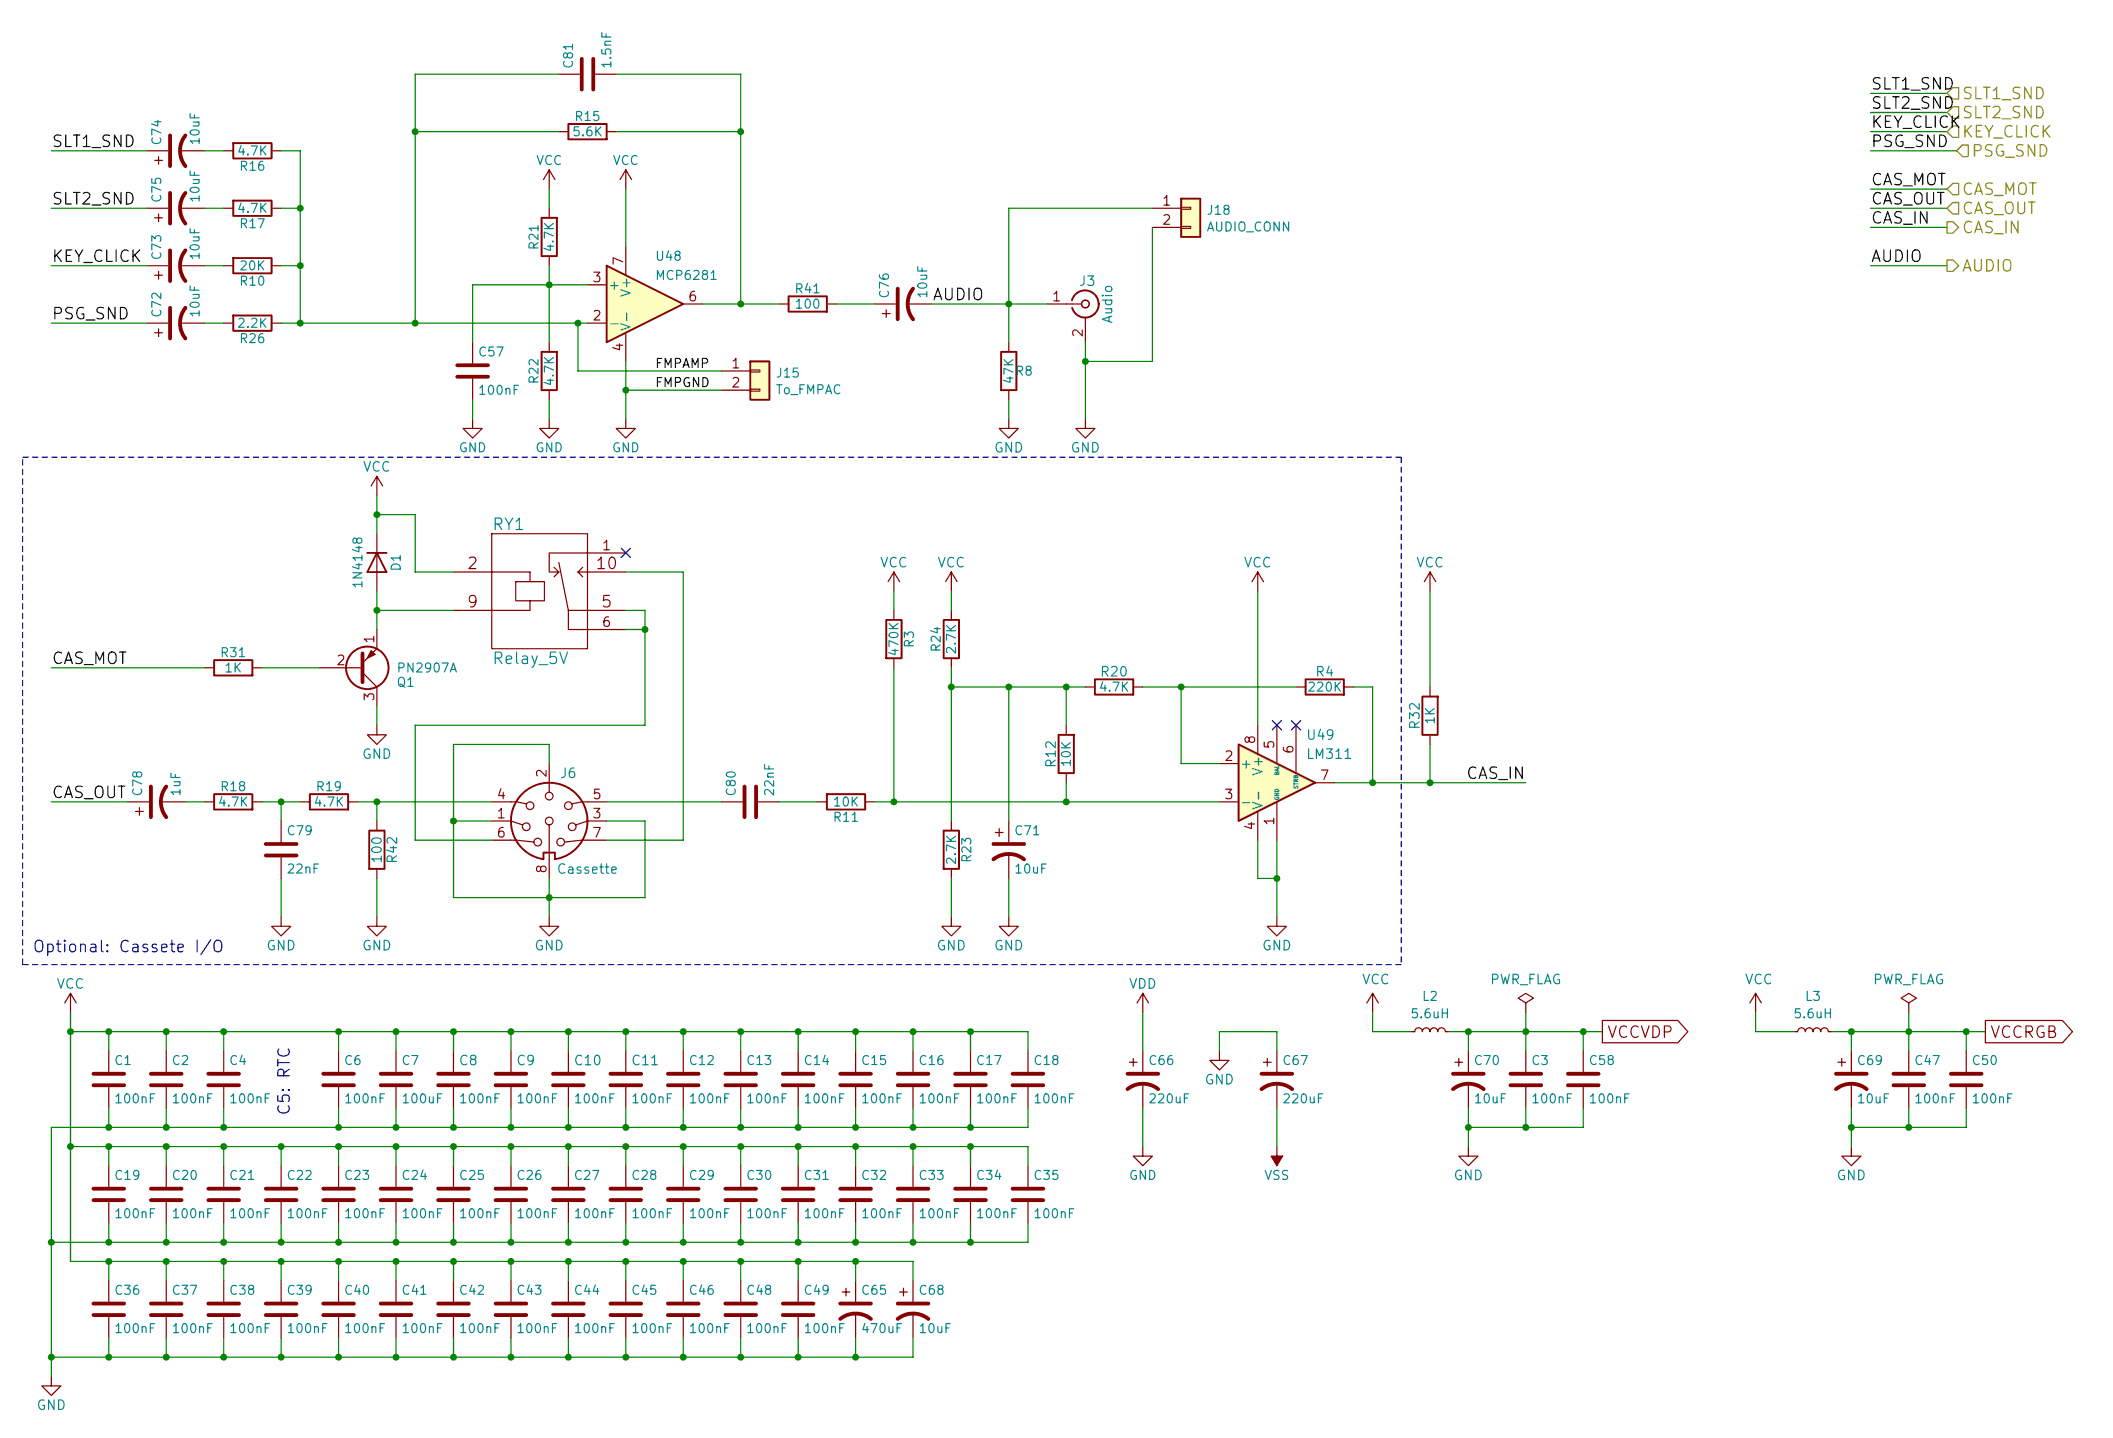
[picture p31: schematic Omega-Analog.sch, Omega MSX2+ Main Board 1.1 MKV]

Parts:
C1, C2, C3, C4, C6, C8, C9, C10, C11, C12, C13, C14, C15, C16, C17, C18, C19, C20, C21, C22, C23, C24, C25, C26, C27, C28, C29, C30, C31, C32, C33, C34, C35, C36, C37, C38, C39, C40, C41, C42, C43, C44, C45, C46, C47, C48, C49, C50, C57, C58: 100nF; C_1206_3216Metric_Pad1.42x1.75mm_HandSolder
C7: 100uF; C_1206_3216Metric_Pad1.42x1.75mm_HandSolder
C65: 470uF; CP_Radial_D10.0mm_P5.00mm
C66, C67: 220uF; CP_Radial_D10.0mm_P5.00mm
C68, C69, C70, C71, C72, C73, C74, C75, C76: 10uF; CP_Radial_D5.0mm_P2.50mm
C78: 1uF; CP_Radial_D5.0mm_P2.50mm
C79, C80: 22nF; C_1206_3216Metric_Pad1.42x1.75mm_HandSolder
C81: 1.5nF; C_1206_3216Metric_Pad1.42x1.75mm_HandSolder
D1: 1N4148; D_1206_3216Metric_Pad1.42x1.75mm_HandSolder
J3: Audio; Conn_RCA_Right
J6: Cassette; DIN8
J15: To_FMPAC; Molex_KK-254_AE-6410-02A_1x02_P2.54mm_Vertical
J18: AUDIO_CONN; Molex_KK-254_AE-6410-02A_1x02_P2.54mm_Vertical
L2, L3: 5.6uH; L_1206_3216Metric_Pad1.42x1.75mm_HandSolder
Q1: PN2907A; TO-92L_Inline_Wide
R3: 470K; R_1206_3216Metric_Pad1.42x1.75mm_HandSolder
R4: 220K; R_1206_3216Metric_Pad1.42x1.75mm_HandSolder
R8: 47K; R_1206_3216Metric_Pad1.42x1.75mm_HandSolder
R10: 20K; R_1206_3216Metric_Pad1.42x1.75mm_HandSolder
R11, R12: 10K; R_1206_3216Metric_Pad1.42x1.75mm_HandSolder
R15: 5.6K; R_1206_3216Metric_Pad1.42x1.75mm_HandSolder
R16, R17, R18, R19, R20, R21, R22: 4.7K; R_1206_3216Metric_Pad1.42x1.75mm_HandSolder
R23, R24: 2.7K; R_1206_3216Metric_Pad1.42x1.75mm_HandSolder
R26: 2.2K; R_1206_3216Metric_Pad1.42x1.75mm_HandSolder
R31, R32: 1K; R_1206_3216Metric_Pad1.42x1.75mm_HandSolder
R41, R42: 100; R_1206_3216Metric_Pad1.42x1.75mm_HandSolder
RY1: Relay_5V; Relay_SPDT
U48: MCP6281; DIP-8_W7.62mm_Socket
U49: LM311; DIP-8_W7.62mm_Socket

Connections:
/AUDIO: C76.2, J3.1 (In), J18.1, R8.1; also elsewhere on the board
/Analog/FMPAMP: C81.1, J15.1, R10.1, R15.1, R16.1, R17.1, R26.1, U48.2 (-)
/CAS_IN: R4.2, R32.1, U49.7; also elsewhere on the board
/CAS_MOT: R31.1; also elsewhere on the board
/CAS_OUT: C78.1; also elsewhere on the board
/KEY_CLICK: C73.1; also elsewhere on the board
/PSG_SND: C72.1; also elsewhere on the board
/SLT1_SND: C74.1; also elsewhere on the board
/SLT2_SND: C75.1; also elsewhere on the board
GND: C1.2, C2.2, C3.2, C4.2, C6.2, C7.2, C8.2, C9.2, C10.2, C11.2, C12.2, C13.2, C14.2, C15.2, C16.2, C17.2, C18.2, C19.2, C20.2, C21.2, C22.2, C23.2, C24.2, C25.2, C26.2, C27.2, C28.2, C29.2, C30.2, C31.2, C32.2, C33.2, C34.2, C35.2, C36.2, C37.2, C38.2, C39.2, C40.2, C41.2, C42.2, C43.2, C44.2, C45.2, C46.2, C47.2, C48.2, C49.2, C50.2, C57.2, C58.2, C65.2, C66.2, C67.1, C68.2, C69.2, C70.2, C71.2, C79.2, J3.2 (Ext), J6.1, J6.2, J6.3, J6.8, J15.2, J18.2, Q1.3 (C), R8.2, R22.1, R23.2, R42.2, U48.4 (V-), U49.1 (GND), U49.4 (V-); also elsewhere on the board
unnamed: C57.1, R21.1, R22.2, U48.3 (+)
unnamed: C71.1, R12.2, R20.1, R23.1, R24.1
unnamed: C72.2, R26.2
unnamed: C73.2, R10.2
unnamed: C74.2, R16.2
unnamed: C75.2, R17.2
unnamed: C76.1, R41.2
unnamed: C78.2, R18.1
unnamed: C79.1, R18.2, R19.1
unnamed: C80.1, J6.5
unnamed: C80.2, R11.2
unnamed: C81.2, R15.2, R41.1, U48.6
unnamed: D1.2 (A), Q1.1 (E), RY1.9
unnamed: J6.4, R19.2, R42.1
unnamed: J6.6, RY1.5, RY1.6
unnamed: J6.7, RY1.10
unnamed: Q1.2 (B), R31.2
unnamed: R3.2, R11.1, R12.1, U49.3 (-)
unnamed: R4.1, R20.2, U49.2 (+)
VCC: C1.1, C2.1, C4.1, C6.1, C7.1, C8.1, C9.1, C10.1, C11.1, C12.1, C13.1, C14.1, C15.1, C16.1, C17.1, C18.1, C19.1, C20.1, C21.1, C22.1, C23.1, C24.1, C25.1, C26.1, C27.1, C28.1, C29.1, C30.1, C31.1, C32.1, C33.1, C34.1, C35.1, C36.1, C37.1, C38.1, C39.1, C40.1, C41.1, C42.1, C43.1, C44.1, C45.1, C46.1, C48.1, C49.1, C65.1, C68.1, D1.1 (K), L2.1, L3.1, R3.1, R21.2, R24.2, R32.2, RY1.2, U48.7 (V+), U49.8 (V+); also elsewhere on the board
VCCRGB: C47.1, C50.1, C69.1, L3.2; also elsewhere on the board
VCCVDP: C3.1, C58.1, C70.1, L2.2; also elsewhere on the board
VDD: C66.1; also elsewhere on the board
VSS: C67.2; also elsewhere on the board

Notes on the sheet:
C5: RTC
Optional: Cassete I/O

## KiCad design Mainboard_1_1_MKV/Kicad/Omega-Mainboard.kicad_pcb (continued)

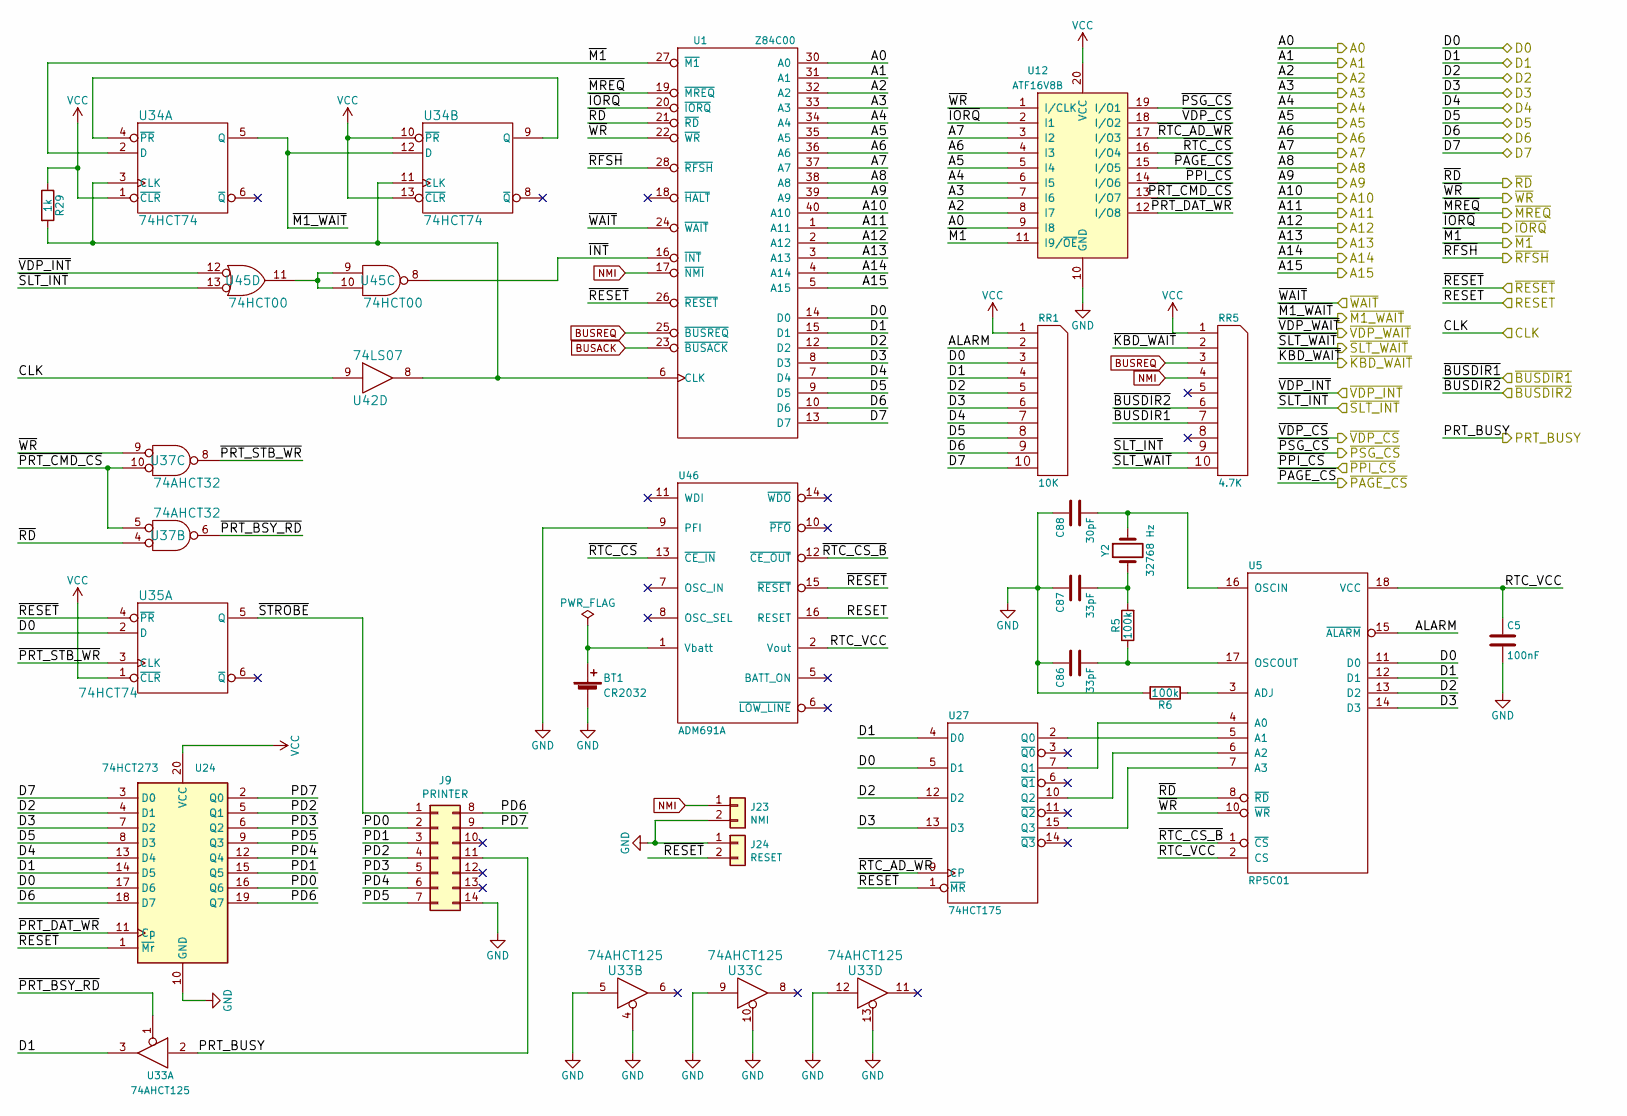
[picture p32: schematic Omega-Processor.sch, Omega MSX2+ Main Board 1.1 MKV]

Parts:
BT1: CR2032; Battery_Holder_CR2032_Universal
C5: 100nF; C_1206_3216Metric_Pad1.42x1.75mm_HandSolder
C86, C87: 33pF; C_1206_3216Metric_Pad1.42x1.75mm_HandSolder
C88: 30pF; C_1206_3216Metric_Pad1.42x1.75mm_HandSolder
J9: PRINTER; Conn_Micro_Ribbon_14F
J23: NMI; Molex_KK-254_AE-6410-02A_1x02_P2.54mm_Vertical
J24: RESET; Molex_KK-254_AE-6410-02A_1x02_P2.54mm_Vertical
R5, R6: 100k; R_1206_3216Metric_Pad1.42x1.75mm_HandSolder
R29: 1k; R_1206_3216Metric_Pad1.42x1.75mm_HandSolder
RR1: 10K; R_Array_SIP10
RR5: 4.7K; R_Array_SIP10
U1: Z84C00; DIP-40_W15.24mm_Socket
U5: RP5C01; DIP-18_W7.62mm_Socket
U12: ATF16V8B; DIP-20_W7.62mm_Socket
U24: 74HCT273; DIP-20_W7.62mm_Socket
U27: 74HCT175; DIP-16_W7.62mm_Socket
U33: 74AHCT125; DIP-14_W7.62mm_Socket
U34, U35: 74HCT74; DIP-14_W7.62mm_Socket
U37: 74AHCT32; IC_DIP14_300
U42: 74LS07; IC_DIP14_300
U45: 74HCT00; IC_DIP14_300
U46: ADM691A; DIP-16_W7.62mm_Socket
Y2: 32768 Hz; Crystal_C38-LF_D3.0mm_L8.0mm_Horizontal_1EP_style2

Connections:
/A0: U1.30 (A0), U12.9 (I8); also elsewhere on the board
/A1: U1.31 (A1); also elsewhere on the board
/A2: U1.32 (A2), U12.8 (I7); also elsewhere on the board
/A3: U1.33 (A3), U12.7 (I6); also elsewhere on the board
/A4: U1.34 (A4), U12.6 (I5); also elsewhere on the board
/A5: U1.35 (A5), U12.5 (I4); also elsewhere on the board
/A6: U1.36 (A6), U12.4 (I3); also elsewhere on the board
/A7: U1.37 (A7), U12.3 (I2); also elsewhere on the board
/A8: U1.38 (A8); also elsewhere on the board
/A9: U1.39 (A9); also elsewhere on the board
/A10: U1.40 (A10); also elsewhere on the board
/A11: U1.1 (A11); also elsewhere on the board
/A12: U1.2 (A12); also elsewhere on the board
/A13: U1.3 (A13); also elsewhere on the board
/A14: U1.4 (A14); also elsewhere on the board
/A15: U1.5 (A15); also elsewhere on the board
/CLK: U42.9; also elsewhere on the board
/D0: RR1.3, U1.14 (D0), U5.11 (D0), U24.17 (D6), U27.5 (D1), U35.2 (D); also elsewhere on the board
/D1: RR1.4, U1.15 (D1), U5.12 (D1), U24.14 (D5), U27.4 (D0), U33.3; also elsewhere on the board
/D2: RR1.5, U1.12 (D2), U5.13 (D2), U24.4 (D1), U27.12 (D2); also elsewhere on the board
/D3: RR1.6, U1.8 (D3), U5.14 (D3), U24.7 (D2), U27.13 (D3); also elsewhere on the board
/D4: RR1.7, U1.7 (D4), U24.13 (D4); also elsewhere on the board
/D5: RR1.8, U1.9 (D5), U24.8 (D3); also elsewhere on the board
/D6: RR1.9, U1.10 (D6), U24.18 (D7); also elsewhere on the board
/D7: RR1.10, U1.13 (D7), U24.3 (D0); also elsewhere on the board
/PRT_BUSY: J9.11, U33.2; also elsewhere on the board
/Processor/ALARM: RR1.2, U5.15 (~ALARM)
/Processor/PD0: J9.2, U24.16 (Q6)
/Processor/PD1: J9.3, U24.15 (Q5)
/Processor/PD2: J9.4, U24.5 (Q1)
/Processor/PD3: J9.5, U24.6 (Q2)
/Processor/PD4: J9.6, U24.12 (Q4)
/Processor/PD5: J9.7, U24.9 (Q3)
/Processor/PD6: J9.8, U24.19 (Q7)
/Processor/PD7: J9.9, U24.2 (Q0)
/Processor/RTC_VCC: C5.1, U5.2 (CS), U5.18 (VCC), U46.2 (Vout)
/Processor/~INT: U1.16 (~INT), U45.8
/Processor/~PRT_BSY_RD: U33.1, U37.6
/Processor/~PRT_CMD_CS: U12.13 (I/O7), U37.5, U37.10
/Processor/~PRT_DAT_WR: U12.12 (I/O8), U24.11 (Cp)
/Processor/~PRT_STB_WR: U35.3 (CLK), U37.8
/Processor/~RTC_AD_WR: U12.17 (I/O3), U27.9 (CP)
/Processor/~RTC_CS: U12.16 (I/O4), U46.13 (~CE_IN)
/Processor/~RTC_CS_B: U5.1 (~CS), U46.12 (~CE_OUT)
/Processor/~STROBE: J9.1, U35.5 (Q)
/RESET: U46.16 (RESET); also elsewhere on the board
/~BUSDIR1: RR5.7; also elsewhere on the board
/~BUSDIR2: RR5.6; also elsewhere on the board
/~IORQ: U1.20 (~IORQ), U12.2 (I1); also elsewhere on the board
/~KBD_WAIT: RR5.2; also elsewhere on the board
/~M1: U1.27 (~M1), U12.11 (I9/~OE), U34.2 (D); also elsewhere on the board
/~M1_WAIT: U34.5 (Q), U34.12 (D); also elsewhere on the board
/~MREQ: U1.19 (~MREQ); also elsewhere on the board
/~PAGE_CS: U12.15 (I/O5); also elsewhere on the board
/~PPI_CS: U12.14 (I/O6); also elsewhere on the board
/~PSG_CS: U12.19 (I/O1); also elsewhere on the board
/~RD: U1.21 (~RD), U5.8 (~RD), U37.4; also elsewhere on the board
/~RESET: J24.2, U1.26 (~RESET), U24.1 (~Mr), U27.1 (~MR), U35.4 (~PR), U46.15 (~RESET); also elsewhere on the board
/~RFSH: U1.28 (~RFSH); also elsewhere on the board
/~SLT_INT: RR5.9, U45.13; also elsewhere on the board
/~SLT_WAIT: RR5.10; also elsewhere on the board
/~VDP_CS: U12.18 (I/O2); also elsewhere on the board
/~VDP_INT: U45.12; also elsewhere on the board
/~WAIT: U1.24 (~WAIT); also elsewhere on the board
/~WR: U1.22 (~WR), U5.10 (~WR), U12.1 (I/CLK), U37.9; also elsewhere on the board
BUSACK: U1.23 (~BUSACK); also elsewhere on the board
BUSREQ: RR5.3, U1.25 (~BUSREQ); also elsewhere on the board
GND: BT1.2 (-), C5.2, C86.1, C87.1, C88.1, J9.14, J23.2, J24.1, R6.2, U1.29 (GND), U5.9 (GND), U12.10 (GND), U24.10 (GND), U27.8 (GND), U33.4, U33.5, U33.7 (GND), U33.9, U33.10, U33.12, U33.13, U34.7 (GND), U35.7 (GND), U37.7 (GND), U42.7 (GND), U45.7 (GND), U46.4 (GND), U46.9 (PFI); also elsewhere on the board
NMI: J23.1, RR5.4, U1.17 (~NMI); also elsewhere on the board
unnamed: BT1.1 (+), U46.1 (Vbatt)
unnamed: C86.2, R5.1, U5.17 (OSCOUT)
unnamed: C87.2, R5.2, Y2.2
unnamed: C88.2, U5.16 (OSCIN), Y2.1
unnamed: R6.1, U5.3 (ADJ)
unnamed: R29.2, U1.6 (CLK), U34.3 (CLK), U34.11 (CLK), U42.8
unnamed: U5.5 (A1), U27.2 (Q0)
unnamed: U5.4 (A0), U27.7 (Q1)
unnamed: U5.6 (A2), U27.10 (Q2)
unnamed: U5.7 (A3), U27.15 (Q3)
unnamed: U34.4 (~PR), U34.9 (Q)
unnamed: U45.9, U45.10, U45.11
VCC: R29.1, RR1.1 (COM), RR5.1 (COM), U1.11 (VCC), U12.20 (VCC), U24.20 (VCC), U27.16 (VCC), U33.14 (VCC), U34.1 (~CLR), U34.10 (~PR), U34.13 (~CLR), U34.14 (VCC), U35.1 (~CLR), U35.14 (VCC), U37.14 (VCC), U42.14 (VCC), U45.14 (VCC), U46.3 (VCC); also elsewhere on the board

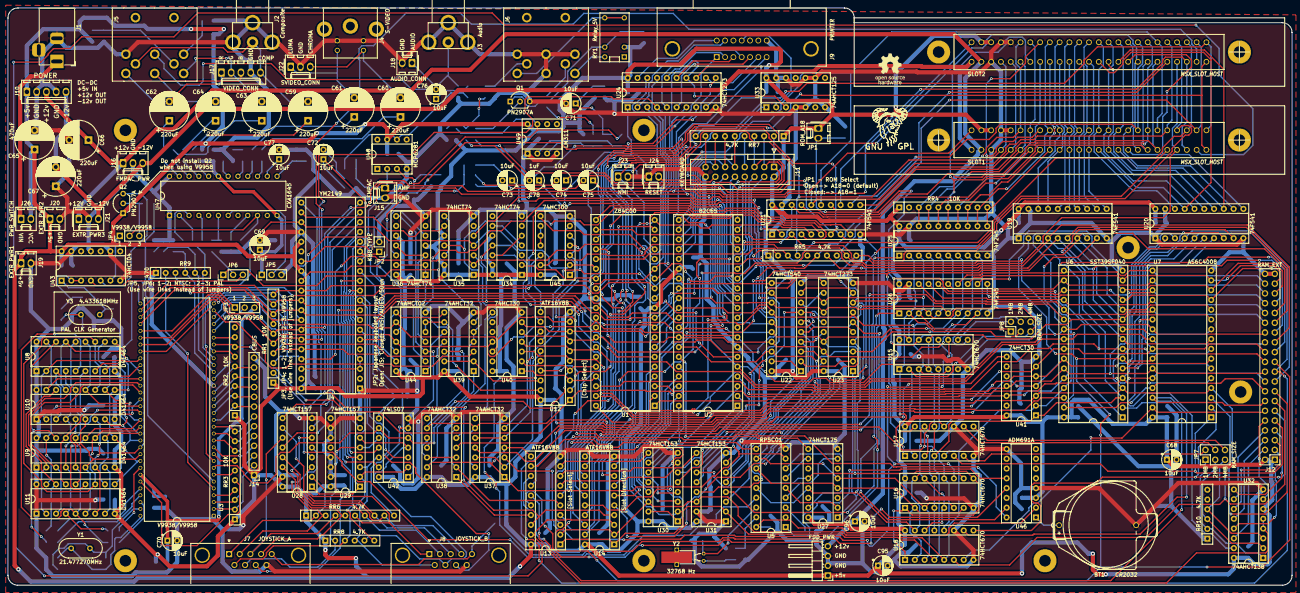
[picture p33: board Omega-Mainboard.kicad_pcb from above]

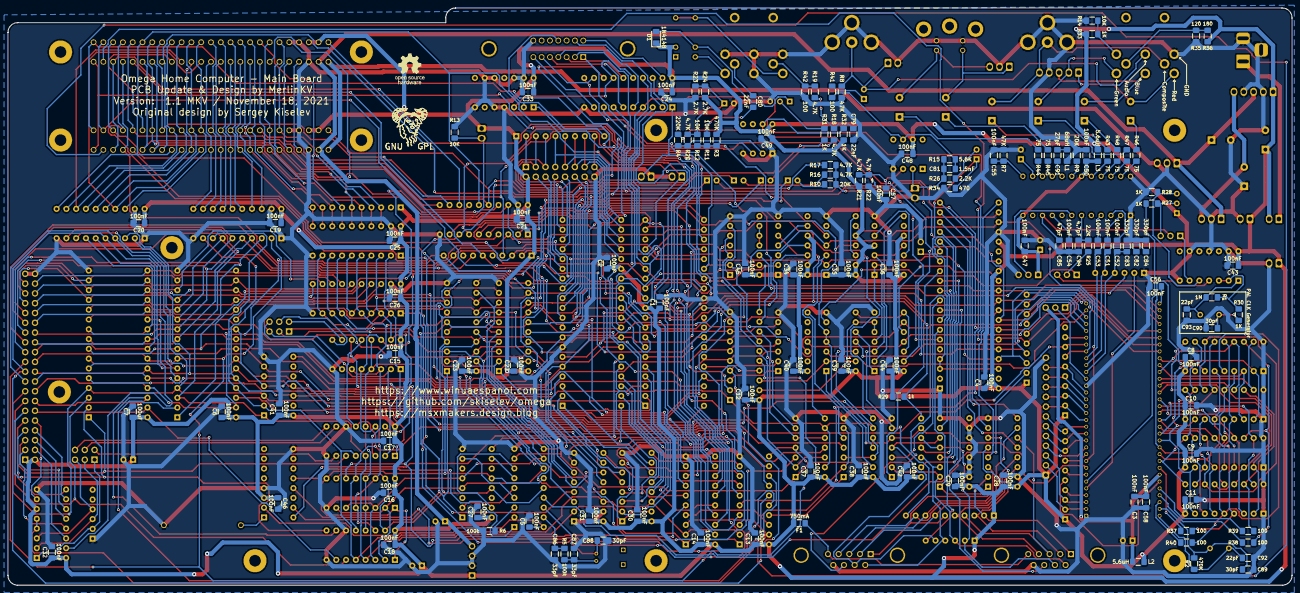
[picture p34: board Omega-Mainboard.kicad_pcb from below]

Board: 2 copper layers, 333.4 x 149.9 mm, 265 parts (129 on the bottom side), 365 nets.

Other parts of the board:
REF01, REF02: OSHW-Logo_7.5x8mm_SilkScreen
REF03, REF04: Symbol_GNU-Logo_SilkscreenTop

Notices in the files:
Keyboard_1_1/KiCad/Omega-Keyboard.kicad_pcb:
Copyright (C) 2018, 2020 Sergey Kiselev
